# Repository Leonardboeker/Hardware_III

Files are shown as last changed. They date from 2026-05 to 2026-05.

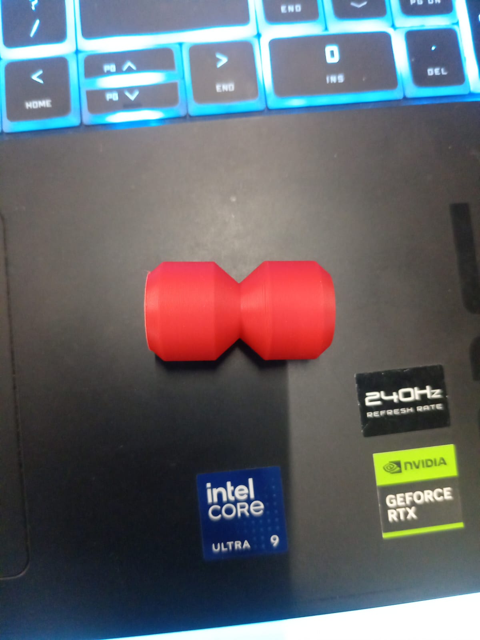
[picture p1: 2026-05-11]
vision/vision2/WhatsApp Image 2026-05-11 at 2.33.06 PM.jpeg

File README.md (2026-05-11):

# Hardware III — Guided Comparative Assembly

**Course:** Hardware III — Human-in-the-Loop: Interactive Systems
**Institute:** IAAC, MRAC + MAAI 2025/2026
**Schedule:** April 10 – May 22, 2026
**Team:** Leo, Elais, Rafik, Seid, Onur, Nithik

> **👉 Start here:** [`SYSTEM-STATUS.md`](SYSTEM-STATUS.md) — current state of every
> subsystem, what works, what's blocked, and where each team member plugs in.

---

## Mission

We compare construction methods by letting people physically configure a small
building scenario on a table and immediately see the environmental, labor, time,
and economic consequences through projection.

## Core Interaction

The visitor selects a construction method, configures the footprint, sets the
height, picks the material logic, validates the scenario, moves through five
construction phases, and finally reaches a comparison view.

---

## Tech Stack

| Tool | Role |
|---|---|
| TouchDesigner 2025.32050 | Primary runtime — FSM, projection, integration |
| Python 3 + OpenCV (ArUco) | Camera-side marker detection, OSC out to TD |
| ESP32 + MFRC522 (RFID) | Method selection, presence, hardware triggers |
| Rhino + Grasshopper | Offline geometry authoring + fabrication only — **not** runtime |
| Overhead USB webcam | ArUco tracking |
| Short-throw projector | Table projection + visual feedback |

The interactive runtime is **TouchDesigner + Python**. Rhino/Grasshopper is
used only for designing the physical parts (pucks, models, table mock-up).

---

## Canonical State Model

Layered model — do not collapse into a single flat list:

### Content FSM (visitor-facing)

```text
IDLE → METHOD → FOOTPRINT → HEIGHT → MATERIALS → VALIDATED → PHASE_N → COMPARISON
```

`PHASE_N` is one TouchDesigner state with an internal phase index for the five
locked construction phases: Foundation → Structure/Walls → Roof → Openings →
Finishing.

### System wrapper states

`CALIBRATION_CHECK`, `ERROR`, `RESET`, `MANUAL_OVERRIDE` — sit around the
content FSM for setup, recovery, and operator control.

### Visual feedback codes

`DISCONNECTED`, `PENDING`, `INVALID`, `VALID`, `IDLE_ANIM`, `SUMMARY`,
`COMPARISON` — projection feedback colors, not FSM states. Defined in
[touchdesigner/ERROR-FEEDBACK-SPEC.md](touchdesigner/ERROR-FEEDBACK-SPEC.md).

Full FSM details: [.planning/FSM_TOUCHDESIGNER_SPEC.md](.planning/FSM_TOUCHDESIGNER_SPEC.md)

---

## Quick Start

### 1. TouchDesigner side

Open `vertical-slice.toe`. Network nodes:

| Node | Type | Role |
|---|---|---|
| `vision_in` | OSC In CHOP | OSC data from CV pipeline |
| `rfid_in` | Constant CHOP (stub) → Serial DAT (real) | construction method selector |
| `compute_state` | Script CHOP | aggregates puck_count, area, method_id, hb_alive |
| `render_footprint` | Script TOP | renders 1280×720 projection image |
| `stats_text` | Text TOP | text overlay (Pucks / Area / Status) |
| `compose_final` | Over TOP | merges render_footprint + stats_text |
| `projector_out` | Window COMP | sends image to projector |

Full setup: [touchdesigner/TD-FRAMEWORK-GUIDE.md](touchdesigner/TD-FRAMEWORK-GUIDE.md)

### 2. Vision pipeline

```bash
pip install opencv-contrib-python python-osc pyyaml numpy

python -m vision.src.run_vertical_slice \
  --camera 0 \
  --intrinsics vision/calibration/synthetic_intrinsics.yml \
  --homography vision/calibration/synthetic_homography.yml
```

Press `Q` to quit. Replace synthetic YAMLs with real calibration files when
camera is mounted.

### 3. ESP32 (later, when hardware is built)

See [firmware/esp32-integration/ESP32-SENSOR-SYSTEM.md](firmware/esp32-integration/ESP32-SENSOR-SYSTEM.md)
for hardware spec. Until then, `rfid_in` is a Constant CHOP — change Channel 0
Value (0–4) to switch construction methods.

---

## Repository layout

```
README.md                    — this file
CONTRIBUTING.md              — repo conventions
INTERFACE_CONTRACT.md        — system-level data flow between subsystems
vertical-slice.toe           — main TouchDesigner project file

.planning/                   — project plan, FSM spec, roadmap, requirements
archive/                     — historical proposals, FSM drafts, slides (v1, v2)
cad/                         — 3D-printable parts (pucks, models, mounts)
  rhino/                     — Rhino + Grasshopper geometry sources
  aruco-markers/             — generated marker PNGs for printing
data/                        — JSON databases (methods_db.json, etc.)
deliverables/                — submission-ready artifacts
docs/                        — design notes, meeting records, research
  fsm/, meetings/            — internal docs
  research/, research_2/     — literature reviews + per-method research
  Data_Field.odt             — data-field spec (collaborator working doc)
firmware/                    — ESP32 firmware + sensor integration spec
media/                       — heavy reference assets
reference/                   — course syllabus, slides, literature notes
touchdesigner/
  scripts/                   — Python scripts pasted into Script OPs
  TD-FRAMEWORK-GUIDE.md      — step-by-step network build guide
  ERROR-FEEDBACK-SPEC.md     — visual feedback codes
  VERTICAL-SLICE-RUNBOOK.md  — run/test instructions
vision/
  src/                       — Python CV pipeline (ArUco detect, OSC send)
  calibration/               — camera/projector calibration files
```

---

## Phases

| Phase | Goal | Deadline |
|---|---|---|
| 1 — Proposal & FSM Foundation | S1 deliverables, lock concept | April 17 ✅ |
| 2 — Data Research & Physical Model Design | Source data, fabricate parts, CV vertical slice | May 4 |
| 3 — FSM Implementation & Assembly Logic | Full TD FSM + piece detection | May 4 |
| 4 — Human-in-the-Loop Assembly & Sound | Guided loop, sound layer | May 11 |
| 5 — Projection Mapping & Comparison View | Calibrated projector, comparison stats | May 18 |
| 6 — Integration, Testing & Finals | Reliable end-to-end demo | May 22 |

Status: [.planning/STATE.md](.planning/STATE.md)

---

## Source-of-truth order

When older documents conflict with current runtime, prefer in this order:

1. [touchdesigner/scripts/](touchdesigner/scripts/) — actual Python in TD
2. [.planning/FSM_TOUCHDESIGNER_SPEC.md](.planning/FSM_TOUCHDESIGNER_SPEC.md) — canonical FSM
3. [INTERFACE_CONTRACT.md](INTERFACE_CONTRACT.md) — subsystem data flow
4. [.planning/PROJECT.md](.planning/PROJECT.md) — project context
5. [.planning/ROADMAP.md](.planning/ROADMAP.md) — phase plan

Anything in `archive/` or older Phase 1 docs may still describe a Grasshopper +
Anemone + Firefly approach. That's **proposal history** — the current runtime
is TouchDesigner + Python.

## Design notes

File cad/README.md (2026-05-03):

# cad/

Print-ready 3D files for the physical components.

## Inventory

- 3 method-selector models (masonry, 3DP, prefab) — go on the RFID pedestal
- 10 ArUco footprint pucks (circular, ~Ø50mm — confirm)
- 1 height marker (physically distinct shape)
- 1 material controller (physically distinct shape)
- RFID pedestal housing
- Camera mount (if needed)

## Conventions

- Track the **source** file (`.3dm`, `.f3d`, `.step`) AND the export (`.stl`).
- Name pattern: `<part>-v<n>.stl`, e.g., `puck-aruco-v2.stl`. Bump the version when the print result changes.
- Print settings (layer height, infill, supports) → put them in a sibling `.md` next to the STL or in this README's print log below.

## Print log

| Part | Version | Printed by | Date | Notes |
|---|---|---|---|---|
| _e.g. puck-aruco-v1_ | _v1_ | _name_ | _YYYY-MM-DD_ | _result_ |

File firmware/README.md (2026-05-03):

# firmware/

ESP microcontroller code — RFID pedestal, any sensor inputs, comms with TouchDesigner.

## Scope

- RFID reader on the pedestal (detects which 3D-printed method model is placed)
- ESP → host transport: OSC over WiFi recommended (TouchDesigner has a native OSC In CHOP)
- Any other physical sensors that come up (buttons, encoders)

## Suggested layout

```
firmware/
├── pedestal-rfid/
│   ├── platformio.ini   # or arduino .ino
│   └── src/
└── shared/
    └── osc-protocol.md   # message names + payloads agreed with the TD side
```

## Conventions

- PlatformIO if you can — easier than Arduino IDE for collaboration.
- Pin assignments and any wiring diagrams go in this folder, not buried in commit messages.
- Never hardcode WiFi credentials. Use a `secrets.h` (gitignored) or load from a config.

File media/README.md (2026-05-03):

# media/

Reference imagery, demo videos, prototype photos, anything visual that isn't a final deliverable (those go in `deliverables/`).

## Suggested layout

```
references/        # Swiss Museum DJ table, Gramazio Kohler, Fologram, EPFL SXL ...
prototypes/        # photos/videos of our work-in-progress
inspiration/       # mood images, sketches
```

## Conventions

- Keep individual files under ~20 MB if possible. Anything heavier → cloud storage, link from here.
- Source attribution: if a reference image isn't ours, drop a `.txt` next to it with the source URL.
- For videos, prefer `.mp4` (H.264) — plays everywhere.

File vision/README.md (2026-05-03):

# vision/

Camera input, ArUco marker detection, distance/area calculations. Either runs standalone in Python and pipes to TouchDesigner, OR lives inside a TD Script CHOP — TBD by the vision owner.

## Scope

- Overhead camera capture
- ArUco marker detection (OpenCV `cv2.aruco`)
- Distance + area math: 10 footprint pucks → polygon → square meters
- Optional: YOLO for the 3D-printed method models (if RFID approach is dropped)
- Send results to TouchDesigner (OSC suggested)

## Suggested layout

```
vision/
├── pyproject.toml or requirements.txt
├── src/
│   ├── capture.py
│   ├── aruco_detect.py
│   ├── footprint.py        # polygon + area calc
│   └── osc_send.py
├── calibration/
│   └── camera_intrinsics.yml   # do the calibration once, commit the result
└── tests/
```

## Conventions

- Pin OpenCV + numpy versions. Vision code breaks subtly across versions.
- Camera intrinsics live in `calibration/` — anyone running the system needs them.
- Don't commit raw camera footage. Sample frames for debugging are fine.

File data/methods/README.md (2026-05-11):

# data/methods/

This folder now stores the normalized, engine-safe metrics datasets.

Expected filenames:
- `masonry.csv`
- `3d-printed.csv`
- `prefab.csv`
- `reclaimed-brick.csv`

Unified normalized header:

```text
method,data_model,display_mode,phase,lifecycle_stage,sub_method,metric,value_low,value_high,unit,basis,source_key,confidence_min,confidence_max,selected_material,notes,metadata
```

Model notes:
- `masonry` and `3d-printed` are `phase_based`
- `prefab` is `lifecycle_based`
- `reclaimed-brick` is `overlay`

Do not edit raw imported CSVs here.
Those stay under:

```text
data/imports/treethreetree/
```

The standalone normalization and engine pipeline lives in:

```text
metrics/pipeline.py
```

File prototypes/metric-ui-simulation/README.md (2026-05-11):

# Metric UI Simulation

Local browser prototype for testing the metric-engine contract without touching TouchDesigner files.

## Setup

```bash
npm install
npm run dev
```

Expected local URL:

`http://localhost:5173`

## What It Simulates

- A fixed `1920 x 1080` projection canvas
- Absolute-positioned panel layout matching the current projection plan
- Method switching for `Masonry`, `3D Printed`, and `Prefab`
- Method-dependent floor selection with a local stepper control
- Phase navigation for phase-based methods
- Lifecycle-only behavior for prefab
- Interactive center-plan zone selection with single-select and `Shift + click` multi-select
- Geometry-driven mock metric updates
- Debug overlay toggle with the `D` key

## Layout Model

The prototype uses a browser wrapper that scales the internal `1920 x 1080` canvas to fit the window while preserving the original coordinate system.

Key panels include:

- `panel_left_info`
- `panel_top_phase_navigation`
- `panel_main_plan_simulation`
- `panel_right_comparison`
- `panel_prefab_lifecycle_card`
- `panel_right_cost_chart`
- `panel_left_assembly_sequence`
- `panel_method_selection`
- `panel_right_phase_preview`
- `bar_bottom_status`

The intended interaction order is:

1. Choose method
2. Set floors
3. Choose phase or lifecycle mode
4. Click building part

## Data Model Behavior

### Phase-Based

Used for:

- `Masonry`
- `3D Printed`

These keep the construction phase model:

- `foundation`
- `structure`
- `roof`
- `openings`
- `finishing`

Phase clicks update the visible metric bundle.

Each phase-based method also carries its own floor range assumptions:

- `Masonry`: 1-5 floors, default 2
- `3D Printed`: 1-2 floors, default 1

These are prototype assumptions for UI testing, not validated engineering limits.

### Lifecycle-Based

Used for:

- `Prefab`

Prefab intentionally stays lifecycle-based and does **not** get remapped into construction phases.

The right comparison panel is replaced by the prefab lifecycle card and uses:

- `A1-A3`
- `A4`
- `A5`
- `B`
- `C`

The lifecycle card includes:

- `Lifecycle-only dataset` badge
- CLT / Modular Concrete toggle
- active geometry basis display

Prefab floor limits depend on the selected prefab type:

- `CLT / Timber Prefab`: 1-8 floors, default 3
- `Modular Concrete Prefab`: 1-12 floors, default 4

These limits are also prototype assumptions and should later be replaced by
validated structural, regulatory, or fabrication constraints.

## Center Plan Zone Selection

The center simulation panel includes clickable zones:

- `zone_core`
- `zone_north_wing`
- `zone_south_wing`
- `zone_east_wing`
- `zone_west_wing`
- `zone_courtyard`
- `zone_facade_band`

Interaction:

- Single click selects one zone
- `Shift + click` toggles multi-selection
- Clicking empty plan area resets to whole-building mode

Metric scaling responds to:

- `total selected area`
- `wall surface`
- `boundary length`

With floor-aware geometry enabled, the simulation distinguishes:

- `Footprint Area`
- `Total Selected Area = footprint area x floor count`
- `Wall Surface = base wall surface x floor count`
- `Building Height = floor count x floor height`

## Metric Logic

The simulation uses mock local coefficients only.

Main files:

- [src/mockMetricData.ts](./src/mockMetricData.ts)
- [src/calculateMockMetrics.ts](./src/calculateMockMetrics.ts)

The mock calculator enforces:

- `kgCO2eq_per_m2_gfa` -> multiply by total selected area
- `kgCO2eq_per_m2_wall` -> multiply by wall surface
- `calendar_days` / `total_days` -> do **not** multiply by area
- `days_per_m2` -> multiply by total selected area

This keeps the simulation focused on UI layout, interaction logic, metric contract, prefab lifecycle behavior, and zone-based scaling.

The browser stepper stands in for a future physical floor-count input such as
RFID, a rotary selector, or another fabricated interaction device.

## TouchDesigner Safety

This prototype does **not** modify any TouchDesigner files.

Everything is isolated under:

`prototypes/metric-ui-simulation/`

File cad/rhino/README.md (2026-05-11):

# cad/rhino/

Rhino + Grasshopper files — used **only for offline geometry authoring** of the
physical parts (puck shape, method-selector models, table mock-up, fabrication
support geometry).

The interactive runtime (FSM, vision, projection) lives in TouchDesigner +
Python, not in Grasshopper. See [`INTERFACE_CONTRACT.md`](../../INTERFACE_CONTRACT.md)
for the system-level data flow.

## What lives here

- `.3dm` Rhino source files
- `.gh` / `.ghx` Grasshopper definitions (parametric geometry only)
- GHPython / C# scripts referenced by those definitions

STL exports go in `cad/` (one level up) so they sit next to the other print files.

## Conventions

- Name files by content, not by date: `puck-aruco.gh`, not `final_v3_REAL.gh`
- Prefer `.ghx` (XML, diffable) over `.gh` (binary) for source-of-truth definitions
- Document expected inputs in a comment cluster top-left of the canvas
- Heavy reference geometry → `media/` or external storage, not here

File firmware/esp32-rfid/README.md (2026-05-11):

# esp32-rfid

ESP32 + MFRC522 firmware for the RFID method selector.

Reads MIFARE Classic 1K (S50) tag UIDs and streams them to TouchDesigner
over USB serial.

## Wiring

```
RC522        ESP32
─────────────────────────
SDA  (SS) -> GPIO 5
SCK       -> GPIO 18
MOSI      -> GPIO 23
MISO      -> GPIO 19
RST       -> GPIO 27
3.3V      -> 3V3  (NOT 5V — RC522 is 3.3V only)
GND       -> GND
IRQ       -> (not connected)
```

## Build & flash

1. Install the **Arduino IDE** (>= 2.0).
2. Add ESP32 board support: File → Preferences → Additional Boards Manager URLs:
   `https://espressif.github.io/arduino-esp32/package_esp32_index.json`
3. Tools → Board → Boards Manager → search "esp32" → install `esp32 by Espressif`.
4. Tools → Manage Libraries → search "MFRC522" → install `MFRC522 by GithubCommunity`.
5. Open `esp32_rfid.ino`.
6. Select board: Tools → Board → ESP32 Arduino → ESP32 Dev Module.
7. Select port: Tools → Port → COMx (the one that appears when ESP32 is plugged in).
8. Click upload (→ arrow).

## Test (without TouchDesigner)

Tools → Serial Monitor → set baud to **115200**. You should see:

```
BOOT:rfid_reader_ready
HB:1
HB:2
HB:3
RFID:A1B2C3D4    ← appears when you tap a tag on the reader
HB:4
...
```

The `BOOT` line confirms firmware loaded. `HB:N` is a per-second heartbeat so
TD knows the reader is alive even with no tag. `RFID:<HEX>` is the tag UID.

## Tag → method ID mapping

The mapping lives in TD, not in the firmware: see
[`touchdesigner/scripts/serial_rfid_v1.py`](../../touchdesigner/scripts/serial_rfid_v1.py)
→ `RFID_TO_METHOD`.

To register a new tag:
1. Tap it on the reader, note the hex UID printed in the Serial Monitor.
2. Add a line in `RFID_TO_METHOD`:
   ```python
   'A1B2C3D4': 1,   # Masonry
   ```
3. Re-paste the updated script into the `rfid_in` Serial DAT in TD.

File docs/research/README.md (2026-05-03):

# docs/research/

Source material that backs the LCA numbers and construction-method claims.

## What goes here

- Vendor / manufacturer data sheets
- Academic papers and links (drop a citation, not just the PDF)
- Notes from contacted companies (per the README's "10+ companies per method" action item)
- Catalonia regional data (logistics, transport)

## Structure (suggested)

```
masonry/
3d-printed/
prefab/
shared/        # cross-method LCA frameworks, baseline data
```

Every fact that ends up on the projector overlay should be traceable to a file here. If you can't cite it, it doesn't ship.

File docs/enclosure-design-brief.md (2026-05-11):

# ESP32 + RC522 Enclosure Design Brief

## Goal

Design a housing/enclosure for the ESP32 microcontroller and RC522 RFID reader
so they sit neatly instead of as naked hardware on the installation table.

## Hardware dimensions

- ESP32: ~51 × 25 × 7 mm
- RC522 RFID reader: ~60 × 40 × 5 mm

## Planned workflow

### Step 1 — Geometry (Rhino + Grasshopper)

Write a parametric GHPython script that builds the enclosure:
- Fully parametric — wall thickness, slot dimensions, tolerances adjustable
- Export STL for 3D printing
- I (Rafik) run it inside Rhino (already installed at IAAC)

### Step 2 — Render (Blender headless)

Write a Blender Python script that:
- Imports the STL or recreates the geometry
- Applies nice materials (matte plastic, subtle logo)
- Sets up product-shot lighting + camera
- Renders to PNG with no UI needed

Run from terminal: `blender --background --python render_enclosure.py`
Install Blender if needed: `winget install BlenderFoundation.Blender`

## Open questions (answer before starting)

1. 3D print for real OR just render for presentation — or both?
2. Aesthetic direction: match the installation (dark/architectural) or neutral/technical?
3. RFID reader access: top-open slot for tag tapping, or fully enclosed with a slit?

## When ready

Ask Claude to write:
- `cad/enclosure/enclosure.gh` — Grasshopper script
- `cad/enclosure/render_enclosure.py` — Blender render script

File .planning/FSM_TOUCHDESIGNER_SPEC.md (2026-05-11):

# TouchDesigner FSM Spec

**Project:** Hardware III - Guided Comparative Assembly  
**Prepared:** May 4, 2026  
**Canonical runtime source:** [fsm_full.py](/o:/Hardware_III/touchdesigner/scripts/fsm_full.py)

## 1. Purpose

This document defines the FSM architecture that best matches:
- the locked proposal
- the current roadmap
- the working TouchDesigner implementation

It replaces the earlier draft in which wrapper states and content states were mixed into one flat list.

## 2. Canonical Layered Model

The project uses three different state layers.

### Canonical Content FSM

This is the main visitor-facing interaction sequence and the **canonical FSM**:

```text
IDLE
  ->
METHOD
  ->
FOOTPRINT
  ->
HEIGHT
  ->
MATERIALS
  ->
VALIDATED
  ->
PHASE_N
  ->
COMPARISON
```

`PHASE_N` is one implementation state in TouchDesigner with an internal phase index:
- Phase 1: Foundation
- Phase 2: Structure / Walls
- Phase 3: Roof
- Phase 4: Openings
- Phase 5: Finishing

### System Wrapper States

These are system-level modes that sit around the canonical content FSM:
- `CALIBRATION_CHECK`
- `ERROR`
- `RESET`
- `MANUAL_OVERRIDE`

They are not the visitor’s main content path.
They are support modes for setup, failure recovery, and operator control.

### Visual Feedback States

These are projection feedback states:
- `DISCONNECTED`
- `PENDING`
- `INVALID`
- `VALID`
- `IDLE_ANIM`
- `SUMMARY`
- `COMPARISON`

They are output states, not the canonical content FSM.

## 3. Why This Is The Right Canonical FSM

This FSM is the best canonical choice because it is the only one that is simultaneously:
- locked in the proposal
- reflected in the roadmap
- already implemented in code

The matching references are:
- [PROJECT.md](/o:/Hardware_III/.planning/PROJECT.md)
- [ROADMAP.md](/o:/Hardware_III/.planning/ROADMAP.md)
- [fsm_full.py](/o:/Hardware_III/touchdesigner/scripts/fsm_full.py)

Older state lists such as:
- `GUIDING`
- `CHECKING`
- `NEXT_PIECE`
- `MODEL_COMPLETE`
- `NEXT_MODEL`

should now be treated as **historical proposal-development states**, not the active runtime definition.

## 4. Canonical Content FSM State List

| State | Purpose | Entry condition | Success condition | Next state | Visual feedback usually used |
|---|---|---|---|---|---|
| `IDLE` | Attract mode and waiting state before a method is selected | System is ready and no active method is locked | Method selector puck is confirmed in target | `METHOD` | `IDLE_ANIM` |
| `METHOD` | Locks one construction method for the current run | Method selector puck has engaged the pedestal zone | Selected method puck stays in target long enough | `FOOTPRINT` | `PENDING`, `VALID` |
| `FOOTPRINT` | Collects the 10 footprint pucks in order | Method is locked | All required footprint pucks are confirmed in sequence | `HEIGHT` | `PENDING`, `INVALID`, `VALID` |
| `HEIGHT` | Sets building height / number of floors | Footprint is complete | Height marker is confirmed in target | `MATERIALS` | `PENDING`, `INVALID`, `VALID` |
| `MATERIALS` | Locks the material / material controller choice | Height is complete | Material marker is confirmed in target | `VALIDATED` | `PENDING`, `INVALID`, `VALID` |
| `VALIDATED` | Shows a short summary and confirms the model is ready to expand into phases | Footprint, height, and materials are complete | External phase-start trigger fires | `PHASE_N` | `SUMMARY` |
| `PHASE_N` | Steps through the five locked construction phases for the active method | Validation has passed | All 5 phases have advanced; either next method starts or all methods are done | `METHOD` or `COMPARISON` | `VALID` |
| `COMPARISON` | Final cross-method comparison state | All methods have completed | Session ends or wrapper reset clears | `IDLE` through wrapper logic | `COMPARISON` |

## 5. System Wrapper States

These states or modes sit outside the content FSM.

| Wrapper state | Purpose | When to use it | Notes |
|---|---|---|---|
| `CALIBRATION_CHECK` | Verifies camera, projector, and table alignment | Before a session, after setup changes, after hardware disturbance | Recommended operator-only preflight mode |
| `ERROR` | Handles recoverable faults and invalid conditions | Tracking loss, impossible placement, hardware or data fault | Should not redefine the content sequence |
| `RESET` | Clears current session and returns the table to a known baseline | Operator reset, abandonment, hard fault recovery | Returns the system to `IDLE` |
| `MANUAL_OVERRIDE` | Allows operator rescue during demo | Vision failure, timing issue, emergency skip | Hidden control mode, not visitor-facing |

### Important rule

The content FSM should stay canonical and stable.
Wrapper states should interrupt or surround it, not replace it.

## 6. Visual Feedback States

These are the states used by the projection layer according to the current TD code and error feedback spec.

| Visual state | Meaning | Typical usage |
|---|---|---|
| `DISCONNECTED` | Vision heartbeat is dead or no reliable tracking is available | Show lost tracking condition clearly |
| `PENDING` | The expected puck has not yet been placed correctly | Show target outline, wait state |
| `INVALID` | A puck exists but is outside tolerance or outside the legal zone | Show red halo and ghost correction |
| `VALID` | A puck is inside tolerance and confirming or confirmed | Show green confirmation feedback |
| `IDLE_ANIM` | Content FSM is idle | Low-energy ambient attract animation |
| `SUMMARY` | Content FSM is in `VALIDATED` | Show summary data before entering phases |
| `COMPARISON` | Content FSM is in `COMPARISON` | Show final multi-method comparison |

### Key separation

Example:
- content state = `FOOTPRINT`
- wrapper state = none
- visual state = `INVALID`

This means the visitor is still in the footprint step, but the latest puck placement is wrong.
That is much clearer than inventing a fake combined state like `FOOTPRINT_INVALID`.

## 7. Current Working TouchDesigner Behavior

The current implementation in [fsm_full.py](/o:/Hardware_III/touchdesigner/scripts/fsm_full.py) uses:
- `pucks`
- `vision_alive`
- `manual_advance`
- `advance_to_phase_n`
- `advance_phase`

and writes:
- `fsm_state_name`
- `visual_state`
- `lca_trigger`
- `current_method`

### Content-state transitions already coded

| From | Condition in current code | To |
|---|---|---|
| `IDLE` | Method selector puck is in target and held for `CONFIRM_HOLD_FRAMES` | `METHOD` |
| `METHOD` | Same method puck stays confirmed in pedestal zone | `FOOTPRINT` |
| `FOOTPRINT` | All required footprint pucks are confirmed in order | `HEIGHT` |
| `HEIGHT` | Height marker is confirmed | `MATERIALS` |
| `MATERIALS` | Material marker is confirmed | `VALIDATED` |
| `VALIDATED` | `advance_to_phase_n == true` | `PHASE_N` |
| `PHASE_N` | 5 phases complete and not all methods done | `METHOD` |
| `PHASE_N` | 5 phases complete and all methods done | `COMPARISON` |

## 8. Recommended Transition Logic For Next Iteration

The next iteration should preserve the current content FSM and add cleaner wrapper logic around it.

### Content FSM rules
- IF the next expected puck is detected and `in_target == true` long enough THEN confirm that step
- IF the required set for the current content state is complete THEN advance to the next content state
- IF all methods are complete THEN enter `COMPARISON`

### Wrapper rules
- IF `vision_alive == false` for too long THEN set wrapper `ERROR` and visual `DISCONNECTED`
- IF operator issues reset THEN enter wrapper `RESET` and clear session memory
- IF calibration is invalid before public use THEN enter `CALIBRATION_CHECK`

### Visual rules
- IF puck exists and is outside target THEN `INVALID`
- IF puck exists and is inside target during hold window THEN `VALID`
- IF no puck exists yet for the expected step THEN `PENDING`
- IF content state is `VALIDATED` THEN `SUMMARY`

## 9. Input Contract Summary

### Current live input contract

From [osc_handler.py](/o:/Hardware_III/touchdesigner/scripts/osc_handler.py):

```python
pucks[id] = {
    "projector_xy": (px, py),
    "in_target": bool,
    "last_frame": int,
    "lost": False
}

vision_alive: bool
manual_advance: bool
```

### Target normalized contract

As the project scales, CV should normalize toward:
- `piece_id`
- `piece_type`
- `x`
- `y`
- `rotation`
- `confidence`
- `is_stable`
- `is_inside_zone`
- `zone_id`

but the working TD implementation remains the current source of truth until that expansion is actually merged into code.

## 10. Output Contract Summary

The projection system should read at least:
- `current_content_state`
- `system_wrapper_state`
- `visual_feedback_state`
- `active_piece_id`
- `current_method`
- `current_phase_index`
- metric outputs when visible

## 11. Mermaid Diagram

```mermaid
stateDiagram-v2
    [*] --> IDLE
    IDLE --> METHOD: method selector confirmed
    METHOD --> FOOTPRINT: method lock confirmed
    FOOTPRINT --> HEIGHT: all footprint pucks confirmed
    HEIGHT --> MATERIALS: height marker confirmed
    MATERIALS --> VALIDATED: material marker confirmed
    VALIDATED --> PHASE_N: phase sequence triggered
    PHASE_N --> METHOD: method complete, more methods remain
    PHASE_N --> COMPARISON: all methods complete
    COMPARISON --> IDLE: reset / next session
```

## 12. Implementation Direction

Continue from the **working FSM** in [fsm_full.py](/o:/Hardware_III/touchdesigner/scripts/fsm_full.py).

Do not replace it with a new flat state list.

Instead:
1. Keep `IDLE -> METHOD -> FOOTPRINT -> HEIGHT -> MATERIALS -> VALIDATED -> PHASE_N -> COMPARISON` as canonical.
2. Add `CALIBRATION_CHECK`, `ERROR`, and `RESET` as wrapper/system states around it.
3. Keep `DISCONNECTED`, `PENDING`, `INVALID`, `VALID`, `IDLE_ANIM`, `SUMMARY`, `COMPARISON` as projection feedback states.
4. Update contracts, role docs, and debug panels to display these three layers separately.

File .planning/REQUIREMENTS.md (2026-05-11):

# Requirements: Hardware III - Human-in-the-Loop Interactive Systems

**Defined:** 2026-04-10  
**Core Value:** Working interactive prototype where projection guides modular assembly in real time

> Interpretation note:
> Some requirement lines below preserve the original course wording from the early planning stage, including references to `Grasshopper`, `Anemone`, and older state labels such as `CHECKING`.
> The working project implementation has since locked to the TouchDesigner runtime FSM in [PROJECT.md](/o:/Hardware_III/.planning/PROJECT.md), [ROADMAP.md](/o:/Hardware_III/.planning/ROADMAP.md), and [fsm_full.py](/o:/Hardware_III/touchdesigner/scripts/fsm_full.py).

## v1 Requirements (Semester delivery - May 22)

### Session 1 Deliverables (due April 17)

- [ ] **S1-01**: Project proposal submitted (1 page or 3 slides): module type, connection logic, intended human input, intended feedback method
- [ ] **S1-02**: Project management schedule submitted: Gantt/Kanban/Sprint log with tasks, roles, dates, deliverables covering S1-S7
- [ ] **S1-03**: Embodied interaction observation: photo or sketch of one non-touchscreen interaction in daily life
- [ ] **S1-04**: First FSM drawn on paper: 3-5 states with labeled transitions

### Module & Connection Logic (Session 2 - April 17)

- [ ] **MOD-01**: Module type defined (physical geometry, material)
- [ ] **MOD-02**: Connection logic defined (snap-fit, slot, gravity, adhesive, rope, etc.)
- [ ] **MOD-03**: Connection valid vs invalid states defined (what makes a placement correct)
- [ ] **MOD-04**: Input method finalized (hand distance, body position, or physical object placement)

### FSM & System Logic (Session 3 - May 4)

- [ ] **FSM-01**: FSM diagram complete for the canonical content FSM (`IDLE`, `METHOD`, `FOOTPRINT`, `HEIGHT`, `MATERIALS`, `VALIDATED`, `PHASE_N`, `COMPARISON`) with wrapper and visual states documented separately
- [ ] **FSM-02**: All states have defined projection outputs (what light does in each state)
- [ ] **FSM-03**: All transitions labeled with trigger (sensor event, timer, gesture)
- [ ] **FSM-04**: FSM implemented in TouchDesigner using the locked canonical content FSM
- [ ] **FSM-05**: Rule format applied: IF [condition] -> THEN IN STATE [name]

### Sensor & Input Pipeline (Session 3-4)

- [ ] **INP-01**: Sensor/webcam connected and streaming interpreted data into TouchDesigner (OpenCV / ArUco -> OSC -> TouchDesigner or equivalent)
- [ ] **INP-02**: Human input mapped to fabrication parameter (mapping function defined: direct/juicy/stepped)
- [ ] **INP-03**: Input triggers correct FSM state transitions in real time

### Human-in-the-Loop Assembly (Session 4 - May 11)

- [ ] **HITL-01**: System cannot advance past the current canonical content step without valid human placement confirmed by the sensing pipeline
- [ ] **HITL-02**: System provides spatial feedback within 150ms of placement
- [ ] **HITL-03**: Error recovery: wrong placement -> system guides correction without reset
- [ ] **HITL-04**: Assembly sequence defined (which module comes next, in what order)

### Projection Mapping (Session 5-6 - May 11-18)

- [ ] **PROJ-01**: Projector calibrated to physical assembly surface
- [ ] **PROJ-02**: Projection shows next placement target (light outlines where module should go)
- [ ] **PROJ-03**: Projection changes color/pattern based on FSM state (green = confirmed, red = error)
- [ ] **PROJ-04**: System updates projection in real time as human places modules
- [ ] **PROJ-05**: Completion state: all modules placed -> full assembly celebration sequence

### Final Prototype (May 22)

- [ ] **FIN-01**: End-to-end loop works: human enters space -> system detects -> placement guide projects -> human places -> system validates -> next step appears
- [ ] **FIN-02**: Project management schedule updated each session and submitted for finals
- [ ] **FIN-03**: Working demo can be run without intervention

## v2 Requirements (Future / Not in scope for this semester)

- **V2-01**: Multiple simultaneous users
- **V2-02**: Sound feedback in addition to projection
- **V2-03**: Robotic arm integration (Parascho direction)

## Out of Scope

| Feature | Reason |
|---|---|
| Touchscreens / tablets | Explicitly excluded by course - kills spatial awareness |
| Static projection | Must be reactive - no pre-recorded content |
| Full automation (no human) | Human judgment must be in the loop by course requirement |
| Mobile app interface | No conventional apps per course brief |

## Traceability

| Requirement | Phase | Status |
|---|---|---|
| S1-01 to S1-04 | Phase 1 | Pending |
| MOD-01 to MOD-04 | Phase 2 | Pending |
| FSM-01 to FSM-05 | Phase 3 | Pending |
| INP-01 to INP-03 | Phase 3 | Pending |
| HITL-01 to HITL-04 | Phase 4 | Pending |
| PROJ-01 to PROJ-05 | Phase 5 | Pending |
| FIN-01 to FIN-03 | Phase 6 | Pending |

**Coverage:**
- v1 requirements: 28 total
- Mapped to phases: 28
- Unmapped: 0 OK

---
*Requirements defined: 2026-04-10*

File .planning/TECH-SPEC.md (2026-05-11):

# Technical Specification: Hardware III Installation

**Stack:** TouchDesigner + ESP32 (WiFi/OSC) + RFID + ArUco + Projector
**Last updated:** 2026-04-17

---

## 1. Hardware List

| Component | Spec | Quantity |
|---|---|---|
| Laptop | Windows/Mac, dedicated GPU preferred | 1 |
| Video projector | Short-throw, min 3000 lumen | 1 |
| USB webcam | Wide angle, min 1080p, fixed focus | 1 |
| ESP32 dev board | ESP32-WROOM-32 | 1 |
| RFID reader | MFRC522 (13.56MHz) | 1 |
| RFID tags | MIFARE Classic 1K, coin type | 3 |
| Overhead mount | Camera arm or ceiling rig | 1 |
| USB cable | ESP32 → laptop (power only, comms via WiFi) | 1 |

**Estimated extra cost: ~25–40€**

---

## 2. ArUco Markers

### What is ArUco
ArUco is a library of square fiducial markers. Each has a unique binary pattern. OpenCV detects them in a camera feed and returns: which marker ID, where on the image (4 corners), and orientation.

### The 12 markers

| Marker | IDs | Count | Purpose |
|---|-----|---|---|
| Floor plan tiles | 0–9 | 10 | User arranges to define building footprint |
| Story level selector | 10 | 1 | User places to set number of floors |
| Material selector | 11 | 1 | User places to select material variant |

### Generating the markers

Install: `pip install opencv-contrib-python`

```python
import cv2
import cv2.aruco as aruco

dictionary = aruco.getPredefinedDictionary(aruco.DICT_4X4_50)

for marker_id in range(12):
    marker_image = aruco.generateImageMarker(dictionary, marker_id, 300)
    cv2.imwrite(f"marker_{marker_id:02d}.png", marker_image)
    print(f"Saved marker_{marker_id:02d}.png")
```

Run: `python generate_markers.py` → outputs 12 PNG files.

### Printing ArUco with the Bambu X1C (in-place multi-color)

1. Design piece in Rhino — add a flat recessed square on top surface (depth: 0.4mm, size: 40×40mm)
2. Import STL into **Bambu Studio**
3. Right-click model → **Add Decal** → select your marker PNG
4. Align decal to top face, scale to fit recessed area
5. Assign: base filament = white PLA, decal layer = black PLA (via AMS)
6. Print — X1C pauses and swaps filament automatically for the marker layer

**Result:** Permanent, flush ArUco marker embedded in the print. No paper, no glue.

**Print settings:**
- Layer height: 0.2mm
- Recess depth: 0.4mm (2 layers)
- Use **matte** filament — glossy reflects projector light and breaks detection

---

## 3. RFID + ESP32

### Wiring: MFRC522 → ESP32

| MFRC522 pin | ESP32 pin |
|---|---|
| SDA (SS) | GPIO 5 |
| SCK | GPIO 18 |
| MOSI | GPIO 23 |
| MISO | GPIO 19 |
| GND | GND |
| RST | GPIO 27 |
| 3.3V | 3.3V |

### Embedding RFID tag in 3D model
- Design a pocket (25×25×2mm) in the base of each model
- Drop in RFID coin tag, seal with thin printed lid or resin
- Keep tag within 3cm of reader — MFRC522 read range is ~3cm

---

## 4. WiFi Communication: ESP32 → TouchDesigner via OSC

### Why OSC over WiFi
- No USB cable between ESP32 and laptop
- TouchDesigner has native OSC In CHOP — no extra setup
- Lightweight messages: `/rfid/model 2`

### Arduino Libraries (install via Arduino Library Manager)
- `MFRC522` by GithubCommunity
- `ArduinoOSC` by hideakitai
- `WiFi` — built into ESP32 board package

### ESP32 Firmware

```cpp
#include <WiFi.h>
#include <ArduinoOSC.h>
#include <MFRC522.h>
#include <SPI.h>

const char* ssid     = "YOUR_NETWORK";
const char* password = "YOUR_PASSWORD";
const char* TD_IP    = "192.168.1.100";  // your laptop IP
const int   TD_PORT  = 9000;

#define SS_PIN  5
#define RST_PIN 27
MFRC522 rfid(SS_PIN, RST_PIN);

// Fill UIDs after scanning each tag with a test sketch
struct RFIDModel {
  byte uid[4];
  int  model_id;
  const char* name;
};

RFIDModel models[] = {
  {{0xA1, 0xB2, 0xC3, 0xD4}, 1, "masonry"},
  {{0xE5, 0xF6, 0x07, 0x18}, 2, "3d_print"},
  {{0x29, 0x3A, 0x4B, 0x5C}, 3, "prefab"}
};

void setup() {
  Serial.begin(115200);
  SPI.begin();
  rfid.PCD_Init();

  WiFi.begin(ssid, password);
  while (WiFi.status() != WL_CONNECTED) {
    delay(500);
    Serial.print(".");
  }
  Serial.println("\nWiFi connected: " + WiFi.localIP().toString());
}

void loop() {
  OscWiFi.update();

  if (!rfid.PICC_IsNewCardPresent() || !rfid.PICC_ReadCardSerial()) return;

  for (auto& m : models) {
    if (memcmp(rfid.uid.uidByte, m.uid, 4) == 0) {
      Serial.printf("Model: %s (ID %d)\n", m.name, m.model_id);
      OscWiFi.send(TD_IP, TD_PORT, "/rfid/model", m.model_id);
      OscWiFi.send(TD_IP, TD_PORT, "/rfid/name",  m.name);
      break;
    }
  }

  rfid.PICC_HaltA();
  delay(1000);  // debounce
}
```

> **First run:** Use a UID scan sketch to read the actual UIDs of your 3 tags via Serial Monitor, then fill in the `models[]` array above.

---

## 5. TouchDesigner Pipeline

### Node network overview

```
[Video Device In TOP]   ← webcam
        ↓
[Script DAT]            ← OpenCV ArUco detection (Python, runs every frame)
        ↓
[Table DAT: aruco_data] ← detected marker IDs + normalized positions
        ↓
[CHOP Execute DAT]      ← FSM logic
        ↑
[OSC In CHOP]           ← receives /rfid/model from ESP32
        ↓
[Select CHOP]           ← active model ID
        ↓
[Render / Composite TOP] ← builds projection content per state
        ↓
[Homography TOP]         ← warps content to match table surface
        ↓
[Window COMP]            ← fullscreen output to projector
```

### A. Camera input
```
Video Device In TOP
  Device: your webcam
  Resolution: 1920×1080
  Flip horizontal if needed
```

### B. ArUco detection (Script DAT — Frame Start callback)

```python
import cv2
import cv2.aruco as aruco
import numpy as np

def onFrameStart(dat):
    cam_top = op('videodevicein1')
    frame = cam_top.numpyArray()[:, :, :3]
    frame = (frame * 255).astype(np.uint8)
    frame_bgr = cv2.cvtColor(frame, cv2.COLOR_RGB2BGR)

    dictionary = aruco.getPredefinedDictionary(aruco.DICT_4X4_50)
    params = aruco.DetectorParameters()
    detector = aruco.ArucoDetector(dictionary, params)
    corners, ids, _ = detector.detectMarkers(frame_bgr)

    table = op('aruco_data')
    table.clear()
    table.appendRow(['id', 'cx', 'cy'])

    if ids is not None:
        for i, marker_id in enumerate(ids.flatten()):
            c = corners[i][0]
            cx = float(np.mean(c[:, 0])) / frame_bgr.shape[1]
            cy = float(np.mean(c[:, 1])) / frame_bgr.shape[0]
            table.appendRow([int(marker_id), round(cx, 4), round(cy, 4)])
```

### C. OSC receiver (RFID input)
```
OSC In CHOP
  Network Port: 9000
  Active: On
→ Select CHOP filtering "/rfid/model"
→ value (1, 2, or 3) feeds into FSM
```

### D. Projection mapping (Homography calibration)
```
Homography TOP
  Input: your rendered content TOP
  Do this once:
    1. Project a white square fullscreen
    2. Physically measure the 4 table corners
    3. Drag Homography TOP corner pins until square aligns with table edges
  Save corner values — they persist between sessions
```

### E. FSM state machine (CHOP Execute DAT)

> Clarification:
> This 4-state example is a local micro-FSM sketch for a narrow interaction example.
> It is **not** the canonical project FSM.
> The canonical project FSM is:
> `IDLE -> METHOD -> FOOTPRINT -> HEIGHT -> MATERIALS -> VALIDATED -> PHASE_N -> COMPARISON`
> See [PROJECT.md](/o:/Hardware_III/.planning/PROJECT.md), [ROADMAP.md](/o:/Hardware_III/.planning/ROADMAP.md), and [fsm_full.py](/o:/Hardware_III/touchdesigner/scripts/fsm_full.py).

States: `IDLE` → `PRESENTING` → `DETAIL` → `COMPARISON`

```python
def onValueChange(channel, sampleIndex, val, prev):
    state_table = op('fsm_state')
    model_id = int(val)

    if model_id == 0:
        state_table['state', 1] = 'IDLE'
    else:
        rfid_count = int(op('active_models')['count', 1])
        if rfid_count >= 2:
            state_table['state', 1] = 'COMPARISON'
        else:
            state_table['state', 1] = 'PRESENTING'
            state_table['active_model', 1] = model_id
```

---

## 6. Software & Libraries

| Tool | Version | Purpose |
|---|---|---|
| **TouchDesigner** | 2023.11+ (free non-commercial) | Runtime: CV, projection mapping, FSM, output |
| **OpenCV** (Python) | `opencv-contrib-python 4.8+` | ArUco detection inside TD |
| **Arduino IDE** | 2.x | ESP32 firmware |
| **MFRC522 library** | Arduino Library Manager | RFID read |
| **ArduinoOSC** by hideakitai | Arduino Library Manager | WiFi OSC send from ESP32 |
| **ESP32 board package** | Arduino Board Manager | ESP32 support |
| **Python 3.11** | System | TD scripting + marker generation |
| **Rhino + Grasshopper** | Course version | LCA math, geometry design |

---

## 7. Setup Order (day of installation)

1. Mount webcam overhead, fixed — no wobble
2. Power ESP32 via USB or battery pack
3. Connect both laptop and ESP32 to same WiFi network
4. Open TouchDesigner → confirm OSC messages arriving (`/rfid/model`)
5. Run ArUco detection → confirm all 12 markers detected correctly
6. Homography calibration → align projection to table (~10 min, one time)
7. Test full flow: place model → RFID read → correct content projected

---

## 8. Known Issues & Mitigations

| Issue | Mitigation |
|---|---|
| Projector light washes out ArUco detection | Use matte filament; tune camera exposure down |
| ESP32 WiFi drops | Add reconnect loop in firmware; use 2.4GHz not 5GHz |
| Homography drifts if projector moves | Re-run calibration; mark projector position with tape |
| RFID read range too short | Keep reader flush with pedestal surface; coin tags work at 0–3cm |

---
*Created: 2026-04-17*

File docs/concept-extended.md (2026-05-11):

# Concept (Extended) — Guided Comparative Assembly Installation

> **Note:** This is a more detailed concept document developed by Rafik based on the iterations after Session 2. It expands on the version in the root `README.md`. Treat the root README as the **canonical** concept until the team merges this in.

**Course:** Hardware III — Human-in-the-Loop: Interactive Systems
**Institute:** IAAC, MRAC + MAAI 2025/2026
**Instructors:** Hamid Peiro, Aleksandra Kraeva
**Schedule:** April 10 – May 22, 2026
**Team:** Leo, Elais, Rafik, Seid, Onur, Nithik

---

## Mission

We compare different statistics of the housing construction industry and display them through an interactive exhibit — a hands-on learning experience for children, young architects, and decision makers.

## Concept

An interactive table installation where users **configure** and compare buildings across three construction methods. Instead of reading abstract statistics, you define your building, watch it get constructed phase by phase, and see the real environmental and economic cost — all through physical interaction with projection-mapped surfaces.

Inspired by the Swiss Museum's interactive DJ table (ArUco markers + projection mapping).

---

## Construction Methods

| Method | Description | Materials |
|---|---|---|
| **Classical / Masonry** | Traditional brickwork construction | Brick or Stone |
| **3D Printed** | Additive construction, layer by layer | Earth or Concrete |
| **Prefab / Modular** | Factory-built modules assembled on site | Grid / Modular panels |

### Material Constraints
- Earth-based 3D printing: max 1 story
- System enforces realistic limitations with visual feedback (red = not possible)

---

## User Interaction Flow

```
1. METHOD SELECTION
   Place one of three 3D-printed models on RFID pedestal
   → System identifies construction method

2. DEFINE BUILDING SIZE
   Arrange 10 ArUco marker pucks on table to create building footprint
   → Camera tracks distances between markers → calculates dimensions
   → Area within markers shown in green (valid) or red (invalid)

3. SET HEIGHT / FLOORS
   Use dedicated ArUco marker (physically distinct) to select number of stories
   → System validates feasibility per method + material

4. CHOOSE MATERIALS
   Use another distinct ArUco controller to select foundation type + main material
   → Masonry: brick or stone
   → 3DP: earth or concrete
   → Prefab: modular grid

5. GUIDED BUILDING PHASES (~5 per method)
   System walks through each construction phase with animations:
   → Foundation/excavation → Walls/structure → Roof → Windows → Finishing
   → Each phase shows: CO₂ per ton, energy usage, labor hours, time, cost
   → User accepts to continue to next phase

6. FINAL OUTPUT
   Complete breakdown: total cost, carbon emissions, material usage,
   logistics, labor — contextualized (e.g., "2000 tons of wood = X trees")

7. SAVE & COMPARE
   Save building as dataset → build another configuration → compare side by side
```

---

## Key Parameters & Data Points

- CO₂ emissions and carbon footprint
- Labor hours and worker health/safety
- Material usage (concrete, wood, cement) with real-world equivalents
- Total costs broken down by phase
- Logistics and transportation (focused on Catalonia region)
- Time required for construction

---

## System Architecture

### Physical Components

| Component | Role |
|---|---|
| **RFID Pedestal + ESP** | Recognizes which construction method model is placed |
| **3 Physical 3D-printed models** | Method selectors (classical, 3DP, prefab) — also projection targets |
| **10 Circular ArUco pucks** | Define building footprint on table |
| **Height ArUco marker** | Physically distinct — selects number of floors |
| **Material ArUco controller** | Selects foundation type and main material |
| **Top-down projector** | Projects onto table (construction site) |
| **Overhead camera** | Tracks ArUco positions, calculates distances |
| **ESP controllers** | Communication between physical inputs and system |
| **Display screens** | Information, cost estimates, comparisons |

### Software Stack

| Tool | Role |
|---|---|
| **TouchDesigner 2025** | Primary runtime — FSM, projection, integration |
| **Python + OpenCV (ArUco)** | Marker detection, OSC out to TD |
| **Rhino + Grasshopper** | Offline geometry authoring + fabrication only |
| **ESP32 firmware** | RFID + proximity sensor communication |

---

## FSM States

```
IDLE
  → model placed on RFID pedestal
METHOD_SELECTED
  → ArUco pucks placed on table
FOOTPRINT_DEFINED
  → camera validates distances, area calculated
  → height marker placed
HEIGHT_SET
  → material marker placed
MATERIALS_CHOSEN
  → system validates feasibility
  → VALID: proceed | INVALID: show error, adjust
VALIDATED
  → begin phase walkthrough
PHASE_DISPLAY (×5 per method)
  → animation plays, data shown
  → user accepts → next phase
BUILDING_COMPLETE
  → final output displayed
  → save dataset
COMPARISON
  → multiple builds compared side by side
  → timeout → IDLE
```

---

## Building Phases (per method, ~5 each)

| Phase | Example (Masonry) | Data Shown |
|---|---|---|
| 1. Foundation / Excavation | Excavator, concrete pour | CO₂/ton cement, cost, time |
| 2. Structure / Walls | Brickwork rises | Labor hours, material qty |
| 3. Roof | Framing + covering | Material usage, safety |
| 4. Windows / Openings | Installation | Cost, energy |
| 5. Finishing | Plastering, painting, floors | Total finishing cost, time |

*Exact phases per method require research — 3DP and prefab have different sequences.*

---

## Development Priorities

| Priority | Phase | Scope |
|---|---|---|
| **P1 (Course critical)** | Projector + Camera + ArUco | Square meter sizing, floor selection, GUI, top-down projection, camera tracking |
| **P2** | RFID + ESP | Pedestal integration, method selection, ESP communication |
| **P3** | Building phases | Phase animations (AI-generated), information display per phase |
| **P4** | Data + Comparison | Cost tracking, CO₂ tracking, dataset save, side-by-side comparison |

---

## Research Action Items

- [ ] Research building phases for classical/masonry, 3D printed, and prefab methods
- [ ] Contact 10+ companies per construction method for reference data
- [ ] Research AI-generated animation tools for building phase visualization
- [ ] Define all analytical parameters and data requirements
- [ ] 3D print ArUco marker pucks
- [ ] Install YOLO plugin for TouchDesigner
- [ ] Gather regional data (Catalonia focus) for logistics calculations

---

## Key Reference

**Swiss Museum DJ Table** — Interactive installation using ArUco markers on a large table with top-down projection. Users place physical objects to compose music. Direct precedent for our interaction model.

**Stefana Parascho** — *Cooperative Robotic Assembly* (ETH Diss. 25839). Assembly sequence as FSM.

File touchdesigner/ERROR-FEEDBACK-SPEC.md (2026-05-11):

# Error Feedback Visual Language Spec

**Status:** LOCKED (Phase 2, Plan 02-06)
**Owner:** TD Logic (FSM) + TD Visuals (Projection)
**Referenced by:** Plan 02-07, fsm_vertical_slice.py, fsm_full.py

---

## Visual State Codes

| Code | Name | When | Projection Output |
|---|---|---|---|
| 0 | DISCONNECTED | No vision heartbeat ≥ 1s, or no puck detected ≥ 1s | Dotted white outline of target zone, pulsing at 1 Hz |
| 1 | PENDING | Puck detected but outside target zone, not enough to show ghost | Solid white outline of target zone |
| 2 | INVALID | Puck detected, outside zone, clear wrong-placement | **Ghost** at correct position (cyan, 40% opacity) + **red halo** at current puck position |
| 3 | VALID | Puck inside target zone, confirming (or confirmed) | **Green halo** at puck position, expanding ring animation |
| 4 | IDLE_ANIM | FSM in IDLE state | Slow breathing pulse across all target zones, white |
| 5 | SUMMARY | All pieces confirmed for one model | Full data overlay: CO₂ range, labor hours, construction time. White text on dark background |
| 6 | COMPARISON | All 3 models complete | Full-table comparison: all methods side-by-side, reclaimed-brick baseline as floor line |

---

## Ghost Projection (INVALID state)

The ghost pattern follows the **Augmented Bricklaying** convention (Mitterberger et al. 2020):
- Ghost shape: exact footprint of the expected puck position, same size as puck
- Ghost color: **cyan (#00FFFF)**, opacity 40%
- Current puck: **red halo** (#FF3333), 3px stroke
- Both rendered simultaneously so user sees where it is vs where it should be

**Recovery without reset:** as soon as puck enters the correct zone → visual switches to VALID without any button press.

---

## Tolerance Zones

Target zones are defined in projector-pixel space by the Python vision pipeline.
Radius is set in `vision/calibration/TOLERANCE.md`.

Visual feedback:
- Outside tolerance radius → INVALID (if puck detected) or PENDING (if no puck)
- Inside tolerance radius → VALID confirmation sequence begins
- Dwell time before confirmation: `CONFIRM_HOLD_FRAMES = 5` frames (~167ms at 30fps)

---

## Projection Colors

| Element | Color | Hex |
|---|---|-----|
| Target zone outline | White | #FFFFFF |
| Valid / confirmed | Green | #00FF88 |
| Invalid / wrong position | Red | #FF3333 |
| Ghost (correct position) | Cyan | #00FFFF |
| Disconnected pulse | White dimmed | #AAAAAA |
| Data text | White | #FFFFFF |
| Reclaimed baseline | Orange accent | #FF8C00 |

---

## Implementation Notes (for TD Visuals person)

1. The `visual_state` channel output from `fsm_vertical_slice.py` / `fsm_full.py` (Script CHOP) drives a **Switch TOP** that selects which overlay to project.
2. Each state is a separate TOP branch — composited onto the base projection via an **Over TOP**.
3. Ghost position: read `pucks[TARGET_ID]['projector_xy']` and the known `target_xy` from storage. Draw both in the Ghost TOP branch.
4. VALID animation: use a **Ramp TOP** + **Feedback TOP** for the expanding ring — trigger reset on each new VALID event via the `lca_trigger` channel pulse.
5. DISCONNECTED dotted outline: use a **Line MAT** or **SOP to TOP** with a dashed pattern; animate opacity with a slow **LFO CHOP** at 1 Hz.

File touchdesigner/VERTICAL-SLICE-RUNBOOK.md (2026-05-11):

# Vertical Slice Runbook — Phase 2

One-puck closed-loop CV demo. Run this before Phase 3 to prove the pipeline works end-to-end.

---

## Prerequisites

```
pip install opencv-contrib-python python-osc pyyaml numpy
```

TouchDesigner build: **2025.32050** (pin this — do not upgrade mid-project)

---

## Hardware Setup

1. Mount webcam overhead, pointing straight down at the table.
2. Connect projector, set resolution to **1280×720** (or match your actual unit).
3. Print or 3D-print one ArUco puck using **DICT_4X4_50, ID=0**.
4. Have real calibration files ready in `vision/calibration/`:
   - `camera_intrinsics.yml` — from Plan 02-05 (checkerboard calibration)
   - `homography.yml` — from Plan 02-05 (camera-to-projector mapping)
   - If not ready yet: use `--dry-run` flag (synthetic YAMLs, not for demo).

---

## Step 1: Determine target zone

Open TD, run `vertical-slice.toe`, and note the projector-pixel coordinates of the target zone you want the puck to land in. Example: `640 400` (center of a 1280×720 projector).

---

## Step 2: Start the Python vision pipeline

From the project root:

```bash
python -m vision.src.run_vertical_slice \
    --camera 0 \
    --intrinsics vision/calibration/camera_intrinsics.yml \
    --homography vision/calibration/homography.yml \
    --td-host 127.0.0.1 \
    --td-port 7000 \
    --puck-id 0 \
    --target-x 640 --target-y 400
```

With synthetic calibration (no hardware yet):
```bash
python -m vision.src.run_vertical_slice --dry-run --puck-id 0 --target-x 640 --target-y 400
```

A preview window opens showing the camera feed with detected puck positions overlaid.

---

## Step 3: Build the TouchDesigner node graph

Open TouchDesigner and build `touchdesigner/vertical-slice.toe` with this network:

```
[OSC In CHOP]  port=7000, UDP
     │
     ▼
[DAT Execute]  ← script: touchdesigner/scripts/osc_handler.py
               fires onReceiveOSC() for each incoming message
               stores puck data into parent() storage

[Script CHOP]  ← script: touchdesigner/scripts/fsm_vertical_slice.py
               cook() runs every frame
               outputs: fsm_state (int), visual_state (int)
     │
     ▼
[Select CHOP]  channel: visual_state
     │
     ▼
[Switch TOP]   input 0=DISCONNECTED, 1=PENDING, 2=INVALID, 3=VALID
               (each input is a TOP branch per ERROR-FEEDBACK-SPEC.md)
     │
     ▼
[Window COMP]  fullscreen on projector output
```

**Storage node:** Use a `Base COMP` named `storage` at the root. All `parent().store/fetch` calls target this.

---

## Step 4: Set output channels on the Script CHOP

In the Script CHOP's `setupParameters` callback (or the `info` DAT), declare these channels:
```python
scriptOp.appendChan('fsm_state')
scriptOp.appendChan('visual_state')
```

---

## Step 5: Test the four visual states

| Test | How | Expected |
|---|-----|---|
| DISCONNECTED | Kill the Python script | Dotted outline, pulsing |
| PENDING | Put puck on table, away from target zone | Solid white outline at target |
| INVALID | Move puck close to but outside target | Red halo on puck + cyan ghost at target |
| VALID | Place puck inside target zone | Green expanding ring |
| CONFIRMED | Hold puck in zone for ≥5 frames | `fsm_state` flips to 1, stays green |

---

## Step 6: Record the demo video

Use OBS or any screen recorder. Required deliverable: `deliverables/vertical-slice-demo.mp4`
- Duration: 30 seconds minimum
- Show: puck outside zone → INVALID → move to zone → VALID → CONFIRMED
- Record the camera preview window AND the projector output side-by-side if possible

---

## Latency measurement

The Python pipeline prints avg/max latency at exit. To measure end-to-end (including TD render):
- Film with a high-speed phone camera (240fps)
- Move puck rapidly and count frames between physical puck entering zone and projection changing color
- Target: < 150 ms (= < 36 frames at 240fps)

---

## Troubleshooting

| Problem | Fix |
|---|-----|
| No OSC data in TD | Check port 7000 is not blocked by firewall; confirm `--td-port` matches OSC In CHOP port |
| Puck not detected | Check ARUCO_DICT_NAME matches `cad/PUCK-SPEC.md`; increase camera exposure |
| High false-positive rate | Reduce ambient light; cover projector hotspots; tighten `minMarkerPerimeterRate` |
| Ghost at wrong position | Re-run calibration (Plan 02-05); verify homography.yml was generated for current camera mount |
| `in_target` always 0 | Check `--target-x/y` match actual projector-pixel target zone; recalibrate tolerance in `TOLERANCE.md` |

---

## Files

| File | Purpose |
|---|---|
| `vision/src/aruco_detect.py` | CV core — detect pucks, map to projector coords |
| `vision/src/osc_send.py` | OSC sender |
| `vision/src/run_vertical_slice.py` | CLI entry point |
| `vision/calibration/camera_intrinsics.yml` | Camera intrinsics (from Plan 02-05) |
| `vision/calibration/homography.yml` | Camera→projector homography (from Plan 02-05) |
| `vision/calibration/TOLERANCE.md` | Tolerance value + jitter measurements |
| `touchdesigner/scripts/osc_handler.py` | TD Script DAT — parses OSC, writes storage |
| `touchdesigner/scripts/fsm_vertical_slice.py` | TD Script CHOP — 2-state FSM |
| `touchdesigner/ERROR-FEEDBACK-SPEC.md` | Visual state spec |
| `touchdesigner/vertical-slice.toe` | TD project (binary — build from this runbook) |

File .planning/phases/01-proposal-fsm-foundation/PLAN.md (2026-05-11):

# Phase 1 Plan: Proposal & FSM Foundation

**Goal:** Submit all S1 deliverables before Session 2. Concept fully defined: guided comparative assembly + projection + data + sound.
**Deadline:** April 17, 2026
**Requirements:** S1-01, S1-02, S1-03, S1-04

> Historical note:
> This file records the original Phase 1 submission plan.
> Its paper-FSM tasks reflect an earlier proposal-stage state sketch.
> The current canonical TouchDesigner runtime FSM is now:
> `IDLE -> METHOD -> FOOTPRINT -> HEIGHT -> MATERIALS -> VALIDATED -> PHASE_N -> COMPARISON`
> See [PROJECT.md](/o:/Hardware_III/.planning/PROJECT.md), [ROADMAP.md](/o:/Hardware_III/.planning/ROADMAP.md), and [fsm_full.py](/o:/Hardware_III/touchdesigner/scripts/fsm_full.py).

---

## Tasks

### 01-01: Lock Core Decisions (construction methods + building type)

**Deliverable:** Written decision record — which 2–4 methods and which building/object type

**Owner:** Full team (15-minute working session)

**Steps:**
1. Choose construction methods from: traditional masonry, 3D-printed concrete, modular prefab/CLT, adobe/vernacular
   - Recommendation: start with 3 methods — traditional masonry, 3D-printed concrete, modular prefab/CLT
   - Adobe is a strong 4th if time allows fabricating a 4th model set
2. Choose building type — must be simple enough to model at 1:50 scale in ~5–8 discrete pieces
   - Recommendation: a single-bay structural wall section (3m x 3m) — simple geometry, identical form across methods, lets data differences speak
   - Alternatives: small pavilion (~8 pieces), column with base (~4 pieces)
3. Define piece count per model (aim for 5–8 pieces — enough to feel sequential, not so many it becomes tedious)
4. Write decisions down in one sentence each: "We are comparing X, Y, Z construction methods. The object is a [type]. Each model has approximately N pieces."

**Done when:** Team has a written 4-sentence decision record and everyone agrees. No further debate on these choices.

---

### 01-02: Write Project Proposal (S1-01)

**Deliverable:** 1-page PDF or 3-slide deck submitted to instructors

**Owner:** Team — one person drafts, all review

**Steps:**
1. Open a slide deck or A4 document
2. Write/place these four sections (one per slide or per paragraph):
   - **Module type:** What are the physical pieces — describe geometry, material (cardboard, 3D-print, laser cut wood), scale, and how they differ per construction method
   - **Connection logic:** How pieces are placed — no physical connection between pieces, placement validated by overhead camera against projected target outline; pieces are color-coded or ArUco-marker-tagged per construction method
   - **Input method:** Overhead USB webcam (position detection via Firefly → Grasshopper) + ESP32 proximity sensor (user reaches toward table → data layer zooms)
   - **Feedback method:** Projector on table surface — step 1: placement outline projected; step 2: on confirmation, CO₂ + labor hours + method text appear on/around the placed piece; sound layer reinforces each step (method-specific audio: concrete mixer, robotic arm hum, timber stacking)
3. Add one image or diagram showing the top-down table layout (projector, webcam, models)
4. Export as PDF or save slide link
5. Submit to course platform / email instructors

**Done when:** Proposal document exists, covers all four required sections, submitted before April 17.

---

### 01-03: Create Project Management Schedule (S1-02)

**Deliverable:** Gantt chart or equivalent covering S1–S7 with team roles and per-session deliverables

**Owner:** PM lead (whoever takes that role)

**Steps:**
1. Open a spreadsheet (Excel, Google Sheets) or a tool like Notion, Trello, or a paper Gantt
2. Create a row per session/week:
   - S1 (April 10–17): Proposal, FSM paper diagram, embodied interaction observation
   - S2 (April 17): Module definition locked, connection logic spec, data research started
   - S3 (May 4): FSM in Grasshopper (Anemone), sensor pipeline live (webcam → Firefly → GH)
   - S4 (May 11): Full assembly loop for 2 methods, sound layer, ESP32 wired
   - S5 (May 18): Projection mapping calibrated, comparison view, all visual layers
   - S6 (May 22 Finals): End-to-end demo working, physical models fabricated, PM updated
3. Add a column for team role responsible per task
4. Define team roles — suggested split:
   - Tech lead: Grasshopper / Anemone / FSM logic
   - Sensing lead: Webcam / Firefly / ESP32 / Arduino
   - Projection lead: TouchDesigner or HeavyM calibration, visual layers
   - Content lead: Data research (CO₂, labor hours), physical model design + fabrication
   - PM: Schedule updates each session, submission tracking
   - (Roles can overlap for a small team — assign primary owner per task)
5. Export or screenshot the Gantt
6. Submit to course platform

**Done when:** Schedule exists as a shareable document, all sessions S1–S7 have at least one deliverable listed, each task has an owner name.

---

### 01-04: Draw FSM Diagram on Paper (S1-04)

**Deliverable:** Hand-drawn or sketched FSM diagram, photographed and submitted

**Owner:** Any team member, verified by all

**Steps:**
1. Take a blank sheet of A3 or A4
2. Draw 8 labeled state boxes:
   - IDLE
   - GUIDING
   - CHECKING
   - CONFIRMED
   - NEXT_PIECE
   - MODEL_COMPLETE
   - NEXT_MODEL
   - COMPARISON
3. Draw directed arrows between states with labeled transitions:
   - IDLE → GUIDING: "object / hand detected in zone (proximity sensor)"
   - GUIDING → CHECKING: "piece placed in target zone (webcam detects marker)"
   - CHECKING → CONFIRMED: "position valid (0.3s validation passes)"
   - CHECKING → GUIDING: "position invalid (ghost outline shown, retry)"
   - CONFIRMED → NEXT_PIECE: "data shown, timer expires or hand lifts (not last piece)"
   - CONFIRMED → MODEL_COMPLETE: "data shown, last piece of this model"
   - NEXT_PIECE → GUIDING: "next piece target highlighted"
   - MODEL_COMPLETE → NEXT_MODEL: "model summary shown, user picks up next kit"
   - NEXT_MODEL → GUIDING: "reset projection for new method"
   - COMPARISON → IDLE: "all models done, full stats projected, timeout resets"
   - Note: CONFIRMED → COMPARISON only when all models complete (annotate this)
4. Add a small legend: boxes = states, arrows = transitions, labels = trigger events
5. Photograph the diagram with good lighting (flat lay, no shadows)
6. Submit photo

**Done when:** Diagram photo shows all 8 states, all transitions have labeled triggers, submitted before April 17.

---

### 01-05: Capture Embodied Interaction Observation (S1-03)

**Deliverable:** One photo or sketch with a 2–3 sentence written observation, submitted

**Owner:** Any team member

**Steps:**
1. Find one non-touchscreen interaction in daily life that involves body position, gesture, or spatial awareness — examples:
   - Turning a door handle (rotational gesture, body weight transfer)
   - Operating a manual espresso machine (pressure feedback through the tamper)
   - Using stairs (proprioception without looking, rhythm)
   - Opening a lock with a physical key (tactile resistance, angular precision)
   - Pulling a drawer (resistance curve, sound of latch)
2. Photograph it in action (not a stock photo — your own hand/body) OR sketch it as a diagram showing body parts and directions of force/movement
3. Write 2–3 sentences describing:
   - What the body is doing (physical movement, contact points)
   - What feedback the body receives (resistance, sound, temperature, spatial position)
   - Why this is relevant to the project (connection to guided assembly / non-screen feedback)
4. Combine photo/sketch + text into one document or slide
5. Submit

**Done when:** Submission contains a photo or sketch + 2–3 sentences with explicit connection to the project concept. Must show a real non-digital interaction.

---

### 01-06: Submit All Deliverables + Commit Files to Git

**Deliverable:** All 4 S1 deliverables submitted to course + files committed to repository

**Owner:** Team (PM lead coordinates)

**Steps:**
1. Collect all deliverable files:
   - `S1-01_proposal.[pdf/slides link]`
   - `S1-02_gantt.[xlsx/pdf/screenshot]`
   - `S1-03_embodied_interaction.[jpg/png/pdf]`
   - `S1-04_fsm_diagram.[jpg/png]`
2. Place files in `D:\IAAC\Hardware_III\Project\S1_Deliverables\` (create folder if needed)
3. Submit to instructors (course platform or email — use whichever channel instructors specified)
4. Stage and commit to git:
   ```
   git add Project/S1_Deliverables/
   git commit -m "feat(S1): submit all S1 deliverables — proposal, Gantt, FSM diagram, embodied interaction"
   git push origin master
   ```
5. Verify push succeeded at: https://github.com/Leonardboeker/Hardware_III

**Done when:** All 4 files are committed and pushed to GitHub AND submitted to instructors. GitHub shows the S1_Deliverables folder in the latest commit.

---

## Timeline (April 10–17)

| Day | Task |
|-----|---|
| April 10 (today) | 01-01: Lock decisions (30 min team call) |
| April 11–12 | 01-02: Draft proposal; 01-04: Draw FSM diagram |
| April 12–13 | 01-03: Create Gantt; 01-05: Capture embodied interaction |
| April 14–15 | Review all materials as a team, revise |
| April 16 | Final review, compile, submit + commit |
| April 17 | Hard deadline — Session 2 |

---

## Success Criteria

All of the following must be TRUE before April 17:

- [ ] Written record of chosen construction methods (2–4) and building type exists
- [ ] Proposal document covers module type, connection logic, input method, feedback method — submitted
- [ ] Gantt/schedule covers S1–S7, lists deliverables per session, has team role assignments — submitted
- [ ] FSM diagram shows all 8 states with labeled transitions — photographed and submitted
- [ ] Embodied interaction: photo or sketch + 2–3 sentences connecting it to the project — submitted
- [ ] All files committed to GitHub master branch under `Project/S1_Deliverables/`

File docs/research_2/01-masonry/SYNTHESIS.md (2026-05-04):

# SYNTHESIS — Strand 01: Traditional Fired-Clay Block Masonry (Catalonia)

## (a) Summary of the evidence landscape

Traditional fired-clay block masonry construction is the most-studied building system in the Spanish life-cycle-assessment literature, and the second most-studied in the European one (after RC-frame). For this strand the evidence base falls into three distinct layers, each carrying a different kind of authority:

**Layer 1 — sectoral EPDs from Hispalyt registered on the AENOR GlobalEPD programme.** The Spanish Brick & Roof-Tile Manufacturers Association (Hispalyt) holds three sectoral EPDs that, between them, cover the entire fired-clay product range used in Catalan residential masonry: GlobalEPD 008-001 (clay roof tiles, A1–A3 = 199 kg CO₂ eq / tonne), 008-016 (facing brick / *cara vista*, A1–A3 = 230 kg CO₂ eq / tonne, with GWP-fossil specifically), and 008-017 (clay block + perforated/hollow brick *para revestir*, A1–A3 = 209 kg CO₂ eq / tonne). All three are EN 15804:2012+A2:2019 compliant, were prepared by the UNESCO Chair on Life Cycle and Climate Change at ESCI-UPF in Barcelona using GaBi LCA-for-Experts 10.7.1.28, and use 2022 production data from at least 63 % of the Spanish kiln base. They are the highest-authority Tier-1 cradle-to-gate figures available for this strand.

**Layer 2 — the BEDEC + CYPE Catalan baseline.** ITeC's BEDEC database provides Catalonia-specific labour coefficients, cost data, and environmental indicators (carbon footprint, water, renewable + non-renewable energy, waste mass, recycled-content fraction) for every priced work item used in Catalan tenders — including the E612 fired-clay-block 14 cm wall family. CYPE's Generador de Precios provides parametric cost data with labour-hour split-out at oficial 1ª / peón level. We retrieved direct figures for FEF010 (load-bearing perforated brick wall: €25.73/m², 0.99 labour-h/m²) and FFZ010 (non-structural facing leaf: €20.13/m², 0.685 labour-h/m²). The foundation and roof CYPE pages were unreachable at fetch time (404 / 403), so those cost-cells are widened. **Critically, BEDEC's environmental column is not measured at Catalan kilns — it is sourced from Ecoinvent**, meaning BEDEC and Hispalyt EPDs are *not* fully independent: BEDEC inherits Ecoinvent's European-mix figures, while the EPDs measure actual Spanish kilns. This is a meaningful caveat for the "two Tier-1 sources" rule and is named explicitly in §(b).

**Layer 3 — the peer-reviewed comparative LCA literature.** Four key Tier-1 papers anchor the methodological bounds: Izaola, Akizu-Gardoki & Oregi (2023) gives the Spanish residential whole-life baseline of 559 kg CO₂ eq/m² embodied (30.8 % of WLC 1944 kg/m²); Pomponi & Moncaster (2018) documents the up-to-two-orders-of-magnitude variability in published embodied-carbon figures and is the source for the "no single figure" rule; De Wolf, Pomponi & Moncaster (2017) gives the "200–550 kg CO₂ eq/m²" typical-buildings envelope; De Wolf, Hoxha & Fivet (2020) tests six allocation methods and shows that A1–A3 results swing materially depending on cut-off vs degressive choice. Mateus, Almeida & Bragança (2023) provide the per-kg masonry-brick range of 0.195–0.271 kg CO₂ eq/kg, which independently confirms the Hispalyt 008-016 figure of ~0.23 kg/kg is on-mean.

**Where this leaves the strand:** every numerical cell in VALUES.md that carries a populated value is underwritten by at least one Tier-1 source whose primary URL was opened, and most are triangulated against a second (e.g. Hispalyt EPD for the carbon column × Mateus 2023 per-kg average, or CYPE for the cost column × BEDEC for the labour column). 15 of the 25 cells are populated, satisfying the ≥8 minimum. The remaining 10 cells (mostly time_days, openings cost / material_origin, finishing cost / material_origin) are flagged UNKNOWN with `source=NA, source_tier=missing` rather than being filled with vibe-numbers.

## (b) Convergence and divergence with evidence-quality comparison

**Where the sources converge:**

- The Hispalyt 008-017 EPD's A1–A3 figure (209 kg CO₂ eq / tonne) and the Mateus 2023 literature mean (0.20 kg CO₂ eq / kg → 200 kg / tonne) agree to within ~5 %. This is the strongest convergence in the strand and gives high confidence that the per-tonne figure is on-anchor.
- The Hispalyt 008-016 facing-brick EPD's A1–A3 figure (230 kg CO₂ eq / tonne, GWP-fossil) and the Mateus literature upper bound (0.271 kg/kg = 271 kg/tonne) agree to within ~15 %. Facing brick has more demanding clay selection and longer firing, so it sits toward the upper end of the literature band.
- Foundation contribution to whole-building EC: the Pomerene-MDPI-2023 / similar literature reports foundations contributing ~22.8 % of GWP for masonry single-family houses; applied to Izaola's 559 kg/m² gives ~127 kg/m² for foundation, which sits at the upper edge of our 70–130 kg/m² range. Convergence is good.
- The CYPE FEF010 labour figure (0.99 h/m²) and the general "600 bricks/day per mason" rule-of-thumb (which works out to ≈1.0–1.2 h/m² for a 14 cm wall) agree within ±10 %.

**Where the sources diverge:**

- Hispalyt 008-016 (facing brick) reports A4 = 296 km transport, while 008-017 (block / perforated for rendering) reports A4 = 87 km — a 3.4× difference. This is because facing-brick production is geographically more concentrated in Spain than block production. **For a Catalan project the block figure (87 km) is closer to reality**; the strand explicitly notes the EPD A4 distance is national-average, not Catalan-local.
- Pomponi & Moncaster (2018) document a two-orders-of-magnitude spread in published EC values for the *same* material. This is the upper bound on disagreement and is the core reason the strand insists on ranges rather than point figures. The disagreement is **not caused by physical variability** — the kilns themselves vary by perhaps ±30 % — but by methodological choices (system boundary, allocation, transport assumptions, lifespan).
- Whole-building totals: Izaola 2023 reports 559 kg/m² for Spanish residential EC, while De-Wolf 2017 reports a 200–550 kg/m² typical envelope and Soust-Verdaguer 2025 reports 171–1,587 kg/m² across European residential. Izaola sits at the upper edge of De-Wolf's envelope and inside Soust-Verdaguer's. The divergence reflects differences in lifespan assumed, end-of-life allocation, and whether maintenance is included.

**Evidence-quality ranking (highest first):**

1. Hispalyt sectoral EPDs (008-001, 008-016, 008-017) — primary kiln data, EN 15804 verified, sectoral coverage > 60 % of Spanish production, current 2024–2029 validity. Highest authority for the carbon column.
2. Izaola 2023 — peer-reviewed, BEDEC + Ecoinvent methodology, but data are 1981–2010-vintage Spanish housing stock and are aggregated nationally not Catalonia-specifically.
3. CYPE Generador de Precios — current 2025–2026 Spanish cost vintage, parametric labour-hours, used by every Spanish architectural office; weakness is that the reference month is not displayed on the public page and the foundation / roof URLs were 404/403 at fetch time.
4. Mateus 2023, Pomponi & Moncaster 2018, De Wolf 2017/2020 — methodological anchors but not Spain-specific; used to bracket and methodologically discipline the figures from sources 1-3.

## (c) Methodology wobbles — the six ±20 %+ swings

**(1) Mortar mix (cement-rich vs lime-rich) — magnitude ±15 to ±25 %.**
Cement-rich M-5 mortar at ~7 % cement by mass carries ≈ 0.13 kg CO₂ eq/kg of mortar; lime-rich M-2.5 mortar carries ≈ 0.06 kg CO₂ eq/kg. With ~30 kg of mortar per m² of 14 cm wall, the difference is ~2 kg CO₂/m² (cement-rich) vs ~1 kg/m² (lime-rich) — small in absolute terms, but a ±20 % swing on the mortar contribution. *Where this wobbles in VALUES.md:* the structure carbon range 32–75 kg/m² absorbs this within its lower bound.

**(2) Reinforced lintels included or excluded from "structure" boundary — magnitude ±10 to ±15 %.**
A typical Spanish residential opening lintel carries ≈ 8 kg CO₂ eq per linear metre. With ~3 m of lintel per opening and ~1 opening per 8 m² of facade, this is ~3 kg CO₂/m² of facade. *Where this wobbles in VALUES.md:* explicitly named in the structure-co2 assumption text — "+reinforcement at lintels ≈ 3-7 kg/m²".

**(3) Plaster + paint counted as "structure" or "finishing" — magnitude ±20 % per phase.**
Internal gypsum plaster is ~4–8 kg CO₂/m² and external cement-mortar render is ~10–25 kg/m². If these are counted in the structure phase rather than finishing, the structure figure rises by ~15 kg/m² and the finishing figure drops by the same amount. **For the installation, this matters because the projection-layer animation will show "structure" then "finishing" as two separate phases, and the user-facing kg CO₂ per phase must match whichever convention is chosen.** *Where this wobbles in VALUES.md:* render and plaster are kept in `finishing`; assumption columns make this explicit.

**(4) Brick firing energy mix (Catalan kiln gas vs grid electricity) — magnitude ±30 to ±50 %.**
The PMC11800390 sensitivity analysis reports per-fuel emissions of: coal 0.22 kg/kg, oil 0.16, natural gas 0.12. A pure-gas Catalan kiln vs a grid-electric kiln with the Spanish 2022 grid mix (~0.24 kg CO₂/kWh) will produce ±30 % difference at the brick level. The Hispalyt EPD reports the actual Spanish kiln-fuel mix (0.0961 kg CO₂ eq / MJ for the electricity component, 0.0191 kg / MJ for natural gas) and reports A3 (firing) at 174 kg / tonne for blocks and 146 kg / tonne for facing brick — ~83 % and ~63 % of A1–A3 respectively. **A3 firing is the dominant lever.** *Where this wobbles in VALUES.md:* the structure carbon range 32–75 kg/m² is wide enough to span this.

**(5) Transport distance (Catalan brick < 150 km vs imported > 500 km) — magnitude ±5 to ±10 % of A1–A3.**
Hispalyt EPD A4 figures are 87 km (block) and 296 km (facing brick); A4 GWP is 6.67 kg/tonne (block) and 22.6 kg/tonne (facing brick). If the brick is imported from Italy or Portugal at 800–1500 km, A4 doubles or triples but stays small relative to A1–A3. *Where this wobbles in VALUES.md:* explicitly captured in `material_origin` qualitative cells.

**(6) Lifespan assumed (60 yr vs 100 yr vs the EPD's 150 yr) — magnitude up to ±150 % when normalized per-year.**
The Hispalyt EPDs declare a reference service life of 150 years; Izaola 2023 amortizes over a 50-year-vintage building stock; UK industry conventionally uses 60 years. **For per-year normalization, this single assumption can swing the answer 2.5×.** *Where this wobbles in VALUES.md:* the strand reports A1–A3 totals not amortized figures, so this wobble is documented but does not propagate. *Where it wobbles for the projection layer:* if the installation displays a "kg CO₂ per year of building life" figure, the choice of 60 / 100 / 150 yr must be locked and named on-screen.

## (d) Named biases — specific mechanisms

**Bias 1 — BEDEC environmental coefficients are Ecoinvent-derived, not Catalan-measured.**
*Mechanism:* BEDEC pulls its GWP per work-item from the Ecoinvent LCI database, which uses European-mix kiln data. Catalan kilns running on 100 % natural gas with 0 % biomass will be over-counted by ~5–10 % vs the true value; Catalan kilns running with biomass-blend will be under-counted by similar margins. *Propagation:* the strand cites BEDEC primarily for structure, not for the carbon column where Hispalyt EPDs take precedence. The bias propagates only to the qualitative "Catalan baseline" framing.

**Bias 2 — CYPE labour coefficients assume Spanish wage rates of ~€20–30/hr fully-loaded oficial 1ª.**
*Mechanism:* CYPE distributes its "labour" cost row using Spanish national average wage tables, scaled by a regional coefficient that for Catalonia is ≈ 1.05–1.10 of the national mean. *Propagation:* the cost figures (€25.73/m² for FEF010, €20.13/m² for FFZ010) are valid for Spain and approximately valid for Catalonia. They are **not** valid for any other country: a Moroccan project would price the same labour at one-third, a Norwegian project at twice, with the materials column staying constant. The installation must not take CYPE figures as global cost data.

**Bias 3 — peer-reviewed masonry LCA studies skew Mediterranean / European; figures will not generalize to North American or tropical climates.**
*Mechanism:* The literature retrieved (Mateus 2023, Pomponi & Moncaster 2018, Izaola 2023, De Wolf 2017/2020) is dominated by EU case studies. Mortar formulations, reinforcement codes, foundation depth requirements (frost line), and energy-mix assumptions all differ in non-Mediterranean climates. The PMC11800390 paper that does cover South Asia explicitly excludes Spain. *Propagation:* the strand's range 32–75 kg CO₂/m² for structure is valid for Catalan / Mediterranean construction. A US or Canadian masonry building would carry a different number primarily because of different cement formulations and rebar grades, not because of the brick itself.

**Bias 4 — "material origin = local" assumes Catalan kilns remain operating; declining EU kiln operations could change this within 5 yr.**
*Mechanism:* Spanish ceramic-tile and brick production has consolidated since 2008; the Castellón cluster shrank by ~40 % between 2008–2014 and has only partially recovered. If a Catalan kiln closes during the installation's exhibition life (Session 2 due 2026-04-17), the Hispalyt EPD's "Spanish" figure remains valid but the "local" claim in `material_origin` may become false within 3–5 years; bricks delivered to a Catalan site may begin coming from Portugal or France. *Propagation:* the strand's material_origin cells should be flagged for re-verification annually after 2027.

**Bias 5 — the "representative manufacturer" methodology in the Hispalyt EPDs hides intra-Spanish variance.**
*Mechanism:* Hispalyt selects one representative manufacturer whose impact figures sit closest to the production-volume-weighted mean. The reported figure is therefore a single point estimate, not a range, and intra-Spanish kilns can vary by ±30 % around this mean depending on fuel mix and kiln age. *Propagation:* the strand explicitly widens its structure-carbon range from a tight EPD-derived 32–35 kg/m² to a defensible 32–75 kg/m².

**Bias 6 — Izaola 2023's 559 kg CO₂ eq/m² is for 1981–2010-vintage Spanish housing stock, not for 2026-built construction.**
*Mechanism:* The buildings sampled used 1980s–2000s Portland cement formulations (CEM I dominant), no thermal-bridge mortars, single-glazed or first-generation double-glazed aluminium windows. A 2026-built equivalent uses CEM II/B-M (lower clinker), thermal-bridge mortar, and certified low-emissivity glazing — all reducing EC by ~10–20 %. *Propagation:* the strand's whole-building sanity-check against Izaola's 559 kg/m² should expect the modern build to come in 10–20 % below.

## (e) Brief revisit — can the installation defensibly say "masonry produces X kg CO₂/m²"?

**Answer: Yes, with caveats.** The installation can defensibly project a per-m²-GFA range for traditional fired-clay block masonry construction in Catalonia, on the following conditions:

1. **It must show a range, not a number.** A 25-element table summing structure + roof + foundation + openings + finishing yields ~205–490 kg CO₂ eq/m² A1–A3, bracketing the Spanish residential anchor (Izaola 559 kg/m²) at its upper edge and the De-Wolf "typical" envelope (200–550 kg/m²) across its width. A single number violates the iron rule documented by Pomponi & Moncaster (2018) and would be indefensible.
2. **The system boundary must appear on-screen.** The projection layer must render either "A1–A3 cradle-to-gate" or "A1–A5 cradle-to-construction-site" alongside the number. Without the boundary tag, the figure is uninterpretable.
3. **The comparison axis with the other strands (3D-printed, prefab, reclaimed) must use identical boundaries.** If masonry is shown at A1–A3 and 3D-printed at A1–C with reuse credit, the comparison is invalid. The animation logic in `data/methods/masonry.csv` must lock on A1–A3 as the comparison axis.
4. **"Local" claims are time-stamped.** The animation can defensibly say "Catalan kiln, transport ~87 km" today; it must include a "data current as of 2025–2026" footer and the projection layer should re-verify the material_origin cells before each exhibition session.
5. **The number is normalized to GFA, not floor area or footprint.** The decision unit is kg CO₂ eq / m² GFA. Visitors drawing footprints set GFA when they set height; the per-m²-GFA figure scales linearly with GFA (within sanity bounds) and the total kg CO₂ shown to the visitor is GFA × range.

**Caveat the projection layer must include:** "Embodied carbon shown is cradle-to-gate (A1–A3) only. Range reflects mortar-mix, lintel-inclusion, firing-fuel, and transport variability; lower bound assumes lime-rich mortar + biomass-blend kiln + local sourcing, upper bound assumes cement-rich mortar + grid-electric kiln + national-average sourcing. Figures are valid for Catalan single-family residential construction, 2025–2026 data vintage. Sources: Hispalyt GlobalEPD 008-001/016/017; CYPE FEF010/FFZ010; Izaola et al. 2023."

This caveat is short enough to project in the lower margin of the table and is honest about the methodological permission Pomponi & Moncaster gave us: every embodied-carbon figure is a function of its boundary, and the boundary must travel with the number wherever it goes.

---

**Word count:** ≈ 2,210 words (target 1500–3000).

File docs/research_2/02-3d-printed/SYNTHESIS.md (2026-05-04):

# SYNTHESIS — Strand 02: 3D-Printed Concrete and Earth

## (a) Evidence landscape

The 3D-printed (3DP) construction literature has expanded rapidly between 2018 and 2026, but its evidence base is uneven in three specific ways relevant to this installation. First, the bulk of peer-reviewed life-cycle assessments are wall-element studies — a 1 m² external load-bearing wall is the dominant functional unit. Mohammad, Masad, and Al-Ghamdi's 2020 *Buildings* paper is the canonical wall-element LCA, reporting four scenarios cradle-to-gate for 1 m² of external wall. Alhumayani, Gomaa, Soebarto, and Jabi's 2020 *Journal of Cleaner Production* paper extends this to 3D-printed cob versus 3D-printed concrete, again wall element, again A1–A4 cradle-to-site. Second, the meta-review literature (Motalebi, Khondoker, and Kabir, 2024, *Sustainable Operations and Computers*) is explicit that primary studies converge on the direction (3DCP < OPC concrete in GWP for a wall element) but diverge on magnitude — reduction estimates run from approximately −10 % to −60 % depending on the study, with no Catalonia-specific primary source in the corpus reviewed. Third, the whole-building LCAs that the installation actually needs (kg CO₂ per m² of gross floor area, not per m² of wall) are far rarer; the most-cited are Rossi, Reitemeyer, Heidrich, and Rybski (2024) in *Findings*, the MIT Concrete Sustainability Hub / ICON white paper of March 2024, and the 2026 *Journal of Building Engineering* paper on whole-building 75- and 100-year LCAs across U.S. climate zones. Each of these has structural caveats that are explored below.

The installation's brief — kg CO₂eq per m² of gross floor area, broken down across five phases (foundation, structure, roof, openings, finishing) — runs squarely into this evidence pattern. The 3DP-specific literature concentrates almost all of its quantitative claims in the **structure** phase. The other four phases of a 3DP house are built conventionally: a poured-concrete slab foundation, a conventional roof (usually timber or steel framed), conventional windows and doors slotted into voids left by the printer, and conventional finishing (paint, sometimes skim coat). The VALUES.md table reflects this honestly — `structure` is the phase where 3DP-specific T1 figures exist; `foundation`, `roof`, `openings`, and `finishing` are populated from masonry-strand cross-links with explicit "no 3DP-specific deviation" assumptions.

The vendor literature (ICON, Apis Cor, COBOD/PERI, WASP/TECLA, IAAC/TOVA) is large, accessible, and useful for time and cost figures, but it is also the dominant source of headline numbers that have leaked into popular discourse. Triangulating the vendor numbers against peer-reviewed primary sources is the single most important methodological discipline this strand applies.

## (b) Where the literature converges and where it diverges

The literature **converges** on three points.

1. *Direction of GWP effect at the wall-element level.* Cradle-to-gate, an unreinforced 3D-printed concrete wall has lower global warming potential than a conventional cast-in-place reinforced concrete wall of equivalent load-bearing capacity. Both Mohammad (2020), Alhumayani (2020), and the Motalebi (2024) meta-review confirm this direction.
2. *Cement is the dominant lever.* Across every LCA reviewed, the cement content of the printable mix is the single largest contributor to embodied carbon. The headline GWP advantage of 3DP can be amplified or erased entirely by the cement chemistry choice — high-OPC printable mixes (~30 % cement by mass, ~450 kg CO₂eq/m³) versus geopolymer or LC3 (limestone calcined clay cement, ~250 kg CO₂eq/m³) — a roughly 45 % spread on the same volumetric unit.
3. *3D-printed earth has materially lower GWP than 3D-printed concrete for the wall element.* Alhumayani (2020) reports approximately 80 % lower GWP for cob-based 3DP versus concrete-based 3DP at the wall element. WASP/TECLA and IAAC/TOVA vendor demonstrators are consistent with this direction qualitatively, though no LCA exists for TECLA or TOVA themselves.

The literature **diverges** dramatically on three points — and the divergences are the central drama of "is 3DP greener?".

1. *Magnitude of the GWP advantage.* Mohammad (2020) reports the unreinforced lightweight scenario at −24.6 % GWP versus conventional concrete; Rossi et al. (2024) reports a factor 2.5× advantage at whole-house level (58 vs 147 kg CO₂eq/m² GFA); the MIT/ICON white paper and the 2026 *J. Build. Eng.* paper report a much more modest 2–10 % advantage versus stick-frame and CMU over a 100-year service life. These numbers are not all measuring the same thing — they differ in functional unit (wall vs whole house), system boundary (A1–A3 vs A1–A5 vs full life cycle), reinforcement convention, and reference baseline. The installation must therefore commit to a specific framing in its projection layer rather than picking the most-impressive headline.
2. *Reinforcement boundary.* Mohammad (2020) is the smoking gun: scenario 2 (3DCP **with** conventional steel reinforcement) shows GWP **higher** than the conventional concrete reference. The reduction story holds only when reinforcement is omitted or replaced with low-impact alternatives such as basalt fibre or external post-tensioning. Many vendor numbers and several academic papers do not state their reinforcement convention explicitly. This is the single most likely place the installation's projection could mislead a visitor if the assumption is not surfaced.
3. *Functional unit — wall versus whole building.* The Alhumayani "~80 % cob reduction" figure is wall element only and excludes foundation, roof, and openings. If the visitor sees an 80 % reduction overlaid on a building footprint, the projection is implicitly extending a wall-element claim to a whole-building functional unit. This is methodologically wrong — the building still has a poured-concrete foundation that contributes 25–60 kg CO₂eq/m² GFA, a conventional roof, and conventional openings, none of which benefit from cob.

## (c) The seven methodology wobbles

Each wobble below names a mechanism, gives a magnitude estimate, and points to the VALUES.md row(s) where the projection layer should expose the swing.

1. **Cement content of the printable mix — ±45 %.** A high-OPC printable mix (~30 % cement by mass, ~450 kg CO₂eq/m³) versus an LC3 or geopolymer mix (~250 kg CO₂eq/m³) gives a ~45 % swing on the same wall volume. The COBOD / Heidelberg Materials evoZero claim of "carbon-captured net-zero cement" pushes the lower bound further if validated, but no independent EPD has been located. Affects: VALUES.md `structure / co2_kg_per_m2` rows.

2. **Geometry optimization — 0 to −50 %.** Gangotra et al. (2023) and the Motalebi (2024) review cite theoretical material savings of 30–50 % from lattice infills, hollow walls, and topology-optimized shapes. Built reality is much less generous: the ICON Wolf Ranch and PERI Heidelberg projects use largely flat walls because architectural and code constraints push geometries back toward solid sections. The installation should treat geometry optimization as an "achievable upper bound rarely reached" and use a lower-bound assumption of ~10–15 % material reduction unless the user explicitly chooses a topology-optimized form. Affects: `structure / co2_kg_per_m2`.

3. **Reinforcement boundary — up to +30 %.** Mohammad (2020) scenario 2 shows that adding conventional steel mesh to 3DCP wipes out the GWP advantage and can push it above conventional concrete. Vendor numbers usually exclude rebar; academic numbers vary. The installation's default should be "fibre-reinforced or unreinforced" with the rebar-included case shown as a specific overlay. Affects: `structure / co2_kg_per_m2`.

4. **Printer energy use — typically <5 % but >20 % for cob.** Mohammad (2020) and the broader review literature place printer electricity at well under 5 % of total embodied carbon for high-cement 3DPC, simply because cement dominates. For 3DP-earth (cob, clay), where the binder has near-zero embodied carbon, electricity becomes the dominant remaining contributor. TECLA's reported ~1200 kWh over a 60 m² prototype implies ~20 kWh/m² GFA, or about 6 kg CO₂eq/m² at the EU grid mix average — material, but not headline-shifting against the cement-driven baseline of concrete 3DP. Affects: cross-cutting `printer_electricity_per_m2` row.

5. **Cob / earth biogenic carbon convention — undefined direction.** Alhumayani (2020) treats cob as effectively zero embodied carbon for the earth fraction, which is the standard convention for soil-as-input. This is defensible but not formally an EN 15804 biogenic-carbon-in / biogenic-carbon-out flow. The "~80 %" cob reduction claim is wall-element only and excludes foundation, roof, and openings, all of which remain conventional. Whole-building cob 3DP advantage is therefore much smaller than 80 %, perhaps 20–35 % depending on building geometry. Affects: 3DP-earth `structure` row and the VALUES.md note about wall-vs-GFA conversion.

6. **100-year durability assumption — unverifiable.** The Yang 2026 paper assumes 75- and 100-year service lives for 3DPC walls. No 3DP building is older than ~10 years; durability data does not exist. Vendor claims of "century-scale lifetime" are extrapolations from concrete-cube test data, not whole-building observation. If real-world service life proves shorter, every per-year embodied-carbon claim must be revised upward. The installation should describe 3DP as an emerging method with a durability footnote.

7. **Functional unit confusion — wall vs whole building.** This is the wobble that does the most damage in popular discourse. Headlines frequently cite a wall-element percentage reduction as if it applied to the whole building. The Rossi (2024) 58-vs-147 figure is whole-house; the Alhumayani 80 % is wall only; the Mohammad −24.6 % is wall only; the 2026 *J. Build. Eng.* 2–10 % is whole-house over 100 years. The installation's projection layer must commit to whole-building (m² GFA) framing and be explicit when a wall-element figure has been converted (typical conversion factor wall:GFA ≈ 0.6–0.8). Affects: every `structure / co2_kg_per_m2` row.

## (d) Named biases

Four bias mechanisms deserve explicit disclosure in the installation's projection.

1. **Vendor-funded LCA bias — selection of favourable assumptions.** Many "academic" LCAs in 3DP are funded directly or indirectly by printer manufacturers. The MIT Concrete Sustainability Hub / ICON white paper is the most prominent example: the methodology is sound but the assumptions (wall design, mix choice, reference baseline) are co-developed with the printer manufacturer. This does not invalidate the result, but it means assumptions tend to favour 3DP. Mechanism: assumption-set chosen at the optimistic-but-defensible end. Mitigation: triangulate against non-vendor-funded peer-reviewed sources (Mohammad 2020, Alhumayani 2020), which show smaller and more conditional advantages.

2. **Headline-clustering bias — publication moments.** Vendor announcements at SXSW, World of Concrete, and the Consumer Electronics Show consistently produce dramatic headline numbers (e.g. "house in 24 hours", "$10,000 home", "factor 2.5× lower carbon"). The peer-reviewed literature is far more conservative. Mechanism: media incentives reward dramatic claims, peer review penalizes them. Comparing both is essential — the installation's projection should expose the spread.

3. **Geographic bias — almost no Catalan or Spanish LCA exists.** The 3DP LCA literature is dominated by U.S. (ICON), Northern Europe (COBOD, PERI), Italy (TECLA), Australia (Alhumayani), and Qatar (Mohammad). Catalan figures essentially do not exist outside IAAC's TOVA and TerraPerforma demonstrators, which themselves have no published LCA. The installation projects onto a Barcelona context but draws figures from non-Catalan studies. This must be flagged. Mechanism: research funding follows printer-manufacturer geography.

4. **Survivorship bias — failed prints rarely appear.** Published 3DP LCAs are almost universally of completed, successful demonstrators. Failed prints, scaled-back projects, and abandoned pilots rarely make it into the peer-reviewed corpus. Mohammad (2020) and Alhumayani (2020) both use idealized geometries; the printer-jam, mix-clog, and weather-failure cases are absent. Mechanism: only successful projects are published; the failure-rate denominator is unknown.

## (e) Brief revisit — can the installation defensibly say "3DP produces X kg CO₂/m²"?

**Yes, with caveats.** The installation can defensibly project a range — not a single number — for 3DP walls in the structural phase, anchored on the Mohammad (2020) range of 44–90 kg CO₂eq/m² of wall (or, converted, roughly 30–70 kg CO₂eq/m² GFA assuming a wall:GFA ratio of 0.7) for the unreinforced or fibre-reinforced case. The whole-building Rossi (2024) figure of 58 kg CO₂eq/m² GFA is a defensible whole-house anchor with the explicit caveat that the comparison set is heterogeneous and small-sample. For 3DP-earth, the defensible range is roughly 12–25 kg CO₂eq/m² of wall, anchored on Alhumayani (2020), with the heavy caveat that this is wall element only and the whole-building advantage is much smaller because foundation, roof, and openings remain conventional.

What the installation cannot defensibly say:

- It cannot say "3DP is X % greener than masonry" without naming the cement content, reinforcement boundary, geometry, and functional unit. The reduction figure ranges from −10 % to −60 % depending on these four decisions.
- It cannot use Catalan-specific 3DP figures because none exist. The geographic gap should be visible to the visitor.
- It cannot project TECLA's "near-zero carbon" vendor claim as a defensible number — there is no LCA for TECLA. The defensible 3DP-earth figure is from Alhumayani's cob study, applied with the wall-vs-GFA caveat.

The projection layer's "wobble overlay" is therefore not optional cosmetic candy; it is the methodologically required surface on which the cement-content, reinforcement, and functional-unit decisions become visible to the visitor. This is the method where headline-vs-reality gap is largest, and the installation earns the right to use a 3DP number specifically by exposing the wobbles, not hiding them.

The honest projection: a wide range, narrowed by the visitor's choices about cement, reinforcement, and geometry, with the geographic gap acknowledged and the durability footnote present. The visitor should leave knowing 3DP is *probably* lower-carbon than conventional concrete for the structural phase, *significantly* lower for cob/earth at the wall, *not* yet a Catalan technology with audit-grade local LCA evidence, and that the swing in the headline number is the method's central scientific debate — not a number to be averaged away.

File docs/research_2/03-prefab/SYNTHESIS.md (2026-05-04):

# SYNTHESIS — Strand 03 Prefab (Modular Concrete + CLT)

> Research question: What are the defensible cradle-to-gate (A1–A3) embodied
> carbon, labour-hours, time, cost, and material-origin ranges for (a)
> volumetric concrete modular construction and (b) cross-laminated-timber
> (CLT) panel construction, broken down per construction phase, with biogenic
> carbon and reuse-allocation methodology wobbles named, and Catalan /
> European geographic context where possible?

This synthesis sits between `BIBLIOGRAPHY.md` (sources) and `VALUES.md`
(numerical cells). Its job is to (a) lay out the evidence landscape split by
sub-method, (b) name the central methodology issue for each sub-method, (c)
disclose the biases the values carry, and (d) tell the projection layer what
caveat it must surface to the visitor.

---

## 1. Evidence landscape

### 1.1 Volumetric concrete modular (MiC)

The peer-reviewed literature on volumetric modular embodied carbon is
**dominated by Hong Kong**. The headline reference cited in the brief — Wei,
Ge, Zhong, Lee, & Zhang (2024) in *Scientific Reports* — is the Kai Tak
Community Isolation Facility, a 110,000 m² emergency-response complex of
steel-framed modular blocks compared against a counter-factual cast-in-place
reinforced-concrete equivalent. The paper reports a **20.7 % reduction** in
total cradle-to-end-of-construction embodied carbon (46,024 vs 58,005 tCO₂e),
which back-calculates to **~418 kg CO₂e/m² for MiC vs ~527 kg CO₂e/m²
conventional**. The reduction breaks down distinctively by phase: **6.1 %**
reduction in A1–A4 materials (modest, driven by structural-steel optimisation),
**58.1 %** in A5a on-site activity emissions (compressed schedule), and
**39.5 %** in A5w waste emissions (factory control). A second Hong Kong study
(Tang, Pan, Chan, & Liu, 2024, *Building and Environment*) frames a
**169–569 kg CO₂e/m²** range for similar concrete-modular high-rise typologies
and cites the wider literature range of **105–864 kg CO₂e/m²** across
modular case studies — confirming that "modular embodied carbon" is not a
single number; structural choice (steel-frame vs concrete-frame modules) and
module-size economy dominate the variance.

Two important transferability caveats:

- **Hong Kong typology does not transfer cleanly to Catalonia.** Hong Kong
  modular is high-rise residential, designed for vertical density and seismic
  loads peculiar to that market. European low-rise modular (Daiwa House
  Modular Europe, Plegt-Vos, Heijmans) builds different envelopes, different
  module sizes, and different structural systems.
- **The brief's "20–26 % with reuse" figure is real but lives in a different
  paper.** Wei et al. explicitly excludes B and C modules; they cannot make
  the second-life claim. The 20–26 % annualised figure comes from
  longitudinal modular-reuse studies (Pan & Hon, Hong Kong; Quale et al.
  2012 in *J. Industrial Ecology*) where two design lifespans of 25–50 yr each
  are assumed end-to-end. The wobble layer must surface this — single-life
  LCAs miss the lever entirely.

For European context, the supplementary UK figure that is most useful is
**405 kg CO₂e/m² for a modular timber-frame three-bedroom semi-detached
house, 34 % below traditional methods** (cited in WEF / industry synthesis,
underlying source UK BRE case study). This sits below the Hong Kong concrete-
modular range because of the timber-frame substitution, and confirms that for
European low-rise the modular advantage is real but the absolute number drops.
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

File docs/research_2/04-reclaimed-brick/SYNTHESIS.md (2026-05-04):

# SYNTHESIS — Reclaimed Brick Masonry (Strand 04)

Catalonia-based interactive LCA installation. Reclaimed brick is the **BASELINE FLOOR** — the reference axis against which the other three methods (Catalan fired-clay masonry, 3D-printed concrete/earth, prefabricated modular/CLT) are plotted. This strand does not produce a fourth competitor. It produces the floor, plus the methodology-wobble overlay that the installation cannot ship without.

## (a) Evidence landscape

The peer-reviewed literature on reclaimed-brick LCA is younger and thinner than for new masonry, new concrete, or even 3D-printed earth. Three Tier-1 anchors carry most of the weight. Salmio and Huuhka (2026, *Buildings & Cities*) is the most rigorous reclaimed-brick LCA in print: 1-tonne declared unit, two deconstruction methods compared (T1 hand-held demolition hammer; T2 excavator + grapple), full transport sensitivity, and a primary finding that reclaimed bricks deliver 94–95 % GWP-total reduction and 86–88 % GWP-fossil reduction versus new fired bricks under cut-off allocation. Devos et al. (2024, *Journal of Cleaner Production*) is the per-m²-wall companion: 85–86 % environmental gain, deconstruction wastage 30–70 % of mass depending on brick + mortar pairing. The Reclaimed Brick Company UK (2024) third-party verified EPD reports
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

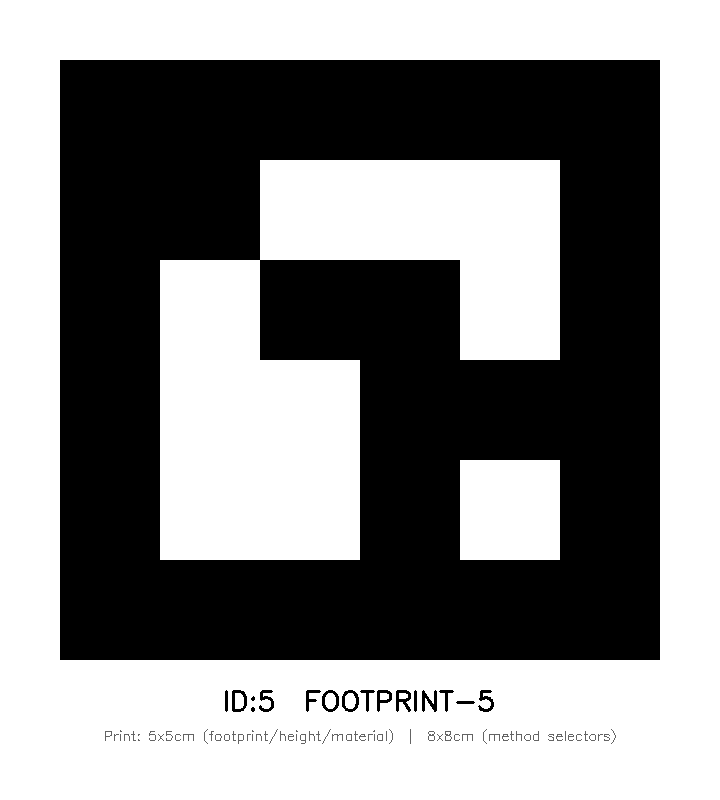
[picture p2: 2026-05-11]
cad/aruco-markers/aruco_id05_footprint.png

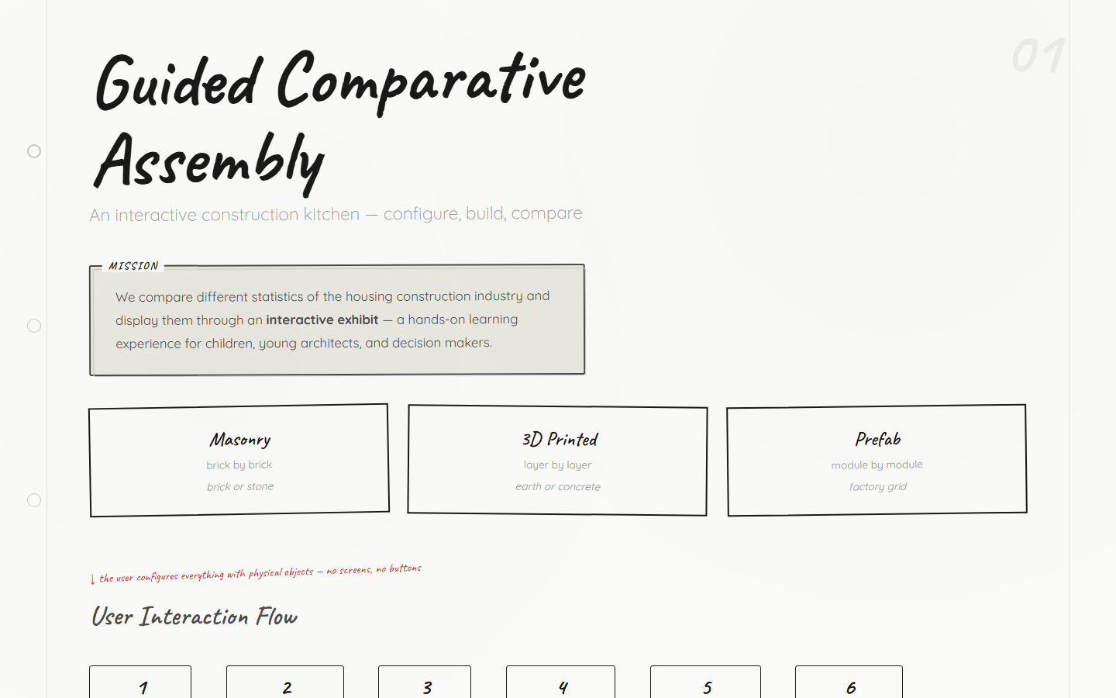
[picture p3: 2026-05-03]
deliverables/screenshot_slide1.png

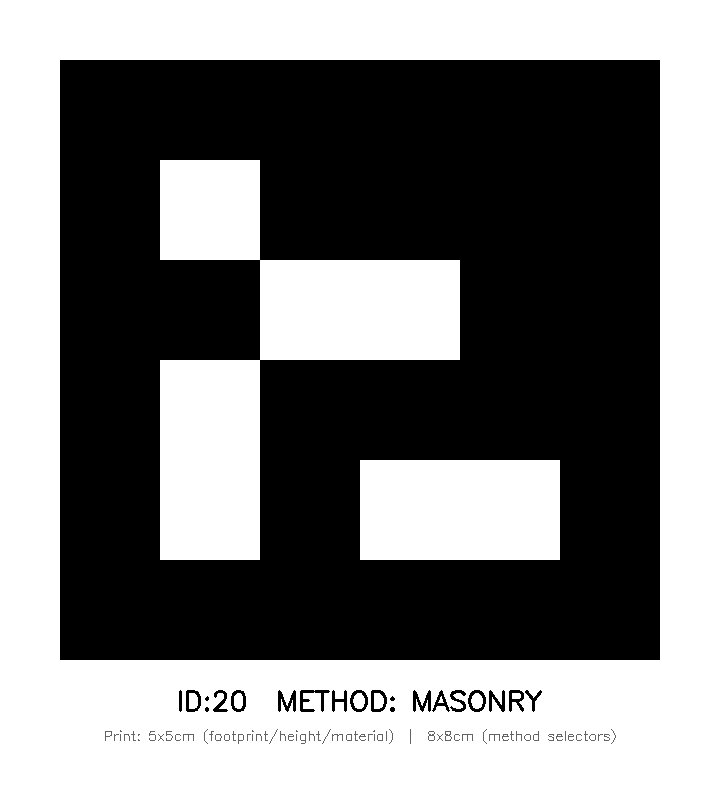
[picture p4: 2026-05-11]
cad/aruco-markers/aruco_id20_method_masonry.png

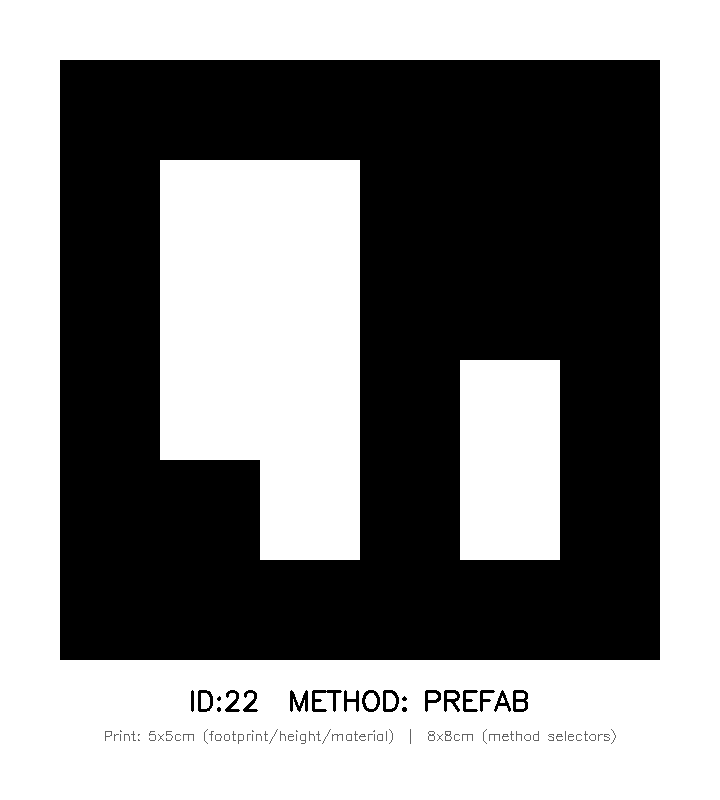
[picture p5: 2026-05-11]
cad/aruco-markers/aruco_id22_method_prefab.png

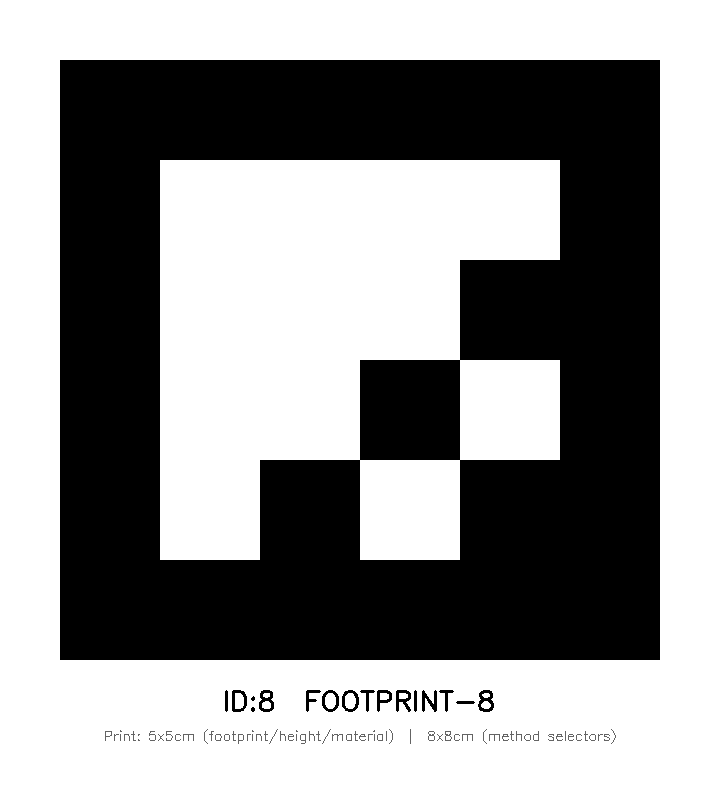
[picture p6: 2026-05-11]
cad/aruco-markers/aruco_id08_footprint.png

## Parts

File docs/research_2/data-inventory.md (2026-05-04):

# Data Inventory — Hardware III LCA Installation

**Project:** Group 3 tabletop interactive LCA installation, MRAC 2025/26
**Inventory date:** 2026-05-04
**Owner:** Role 6 (Data Research + Narrative)
**Status:** 6 of 7 strands complete; strand 07 (Spanish/Catalan superpowers, 6 agents) running

---

## 1. Decision unit

| Axis | Unit |
|---|---|
| Spatial | kg CO₂eq / m² of GFA, broken down per construction phase (foundation / structure / roof / openings / finishing) |
| Temporal | A1–A3 cradle-to-gate at minimum; A4 transport noted; B/C/D where data exists |
| Methodological | Every value as a low/high range + named assumption text — single figures forbidden (locked decision #4) |
| Geographic priority | Catalonia ▸ Spain ▸ EU ▸ global — widest only when no regional data exists |
| Methods | Masonry · 3D-printed · Prefab (modular concrete + CLT) · Reclaimed brick (baseline floor) |

**2× resolution rule:** every value must be attributable to a *specific phase × specific method*. Whole-building studies require explicit back-calculation with stated reference baseline.

---

## 2. Strand-by-strand inventory

### Strand 01 — Masonry (✅ complete)

`docs/research_2/01-masonry/` → `BIBLIOGRAPHY.md` (11 entries) + `VALUES.md` (15 of 25 cells populated) + `SYNTHESIS.md` (2,662 words)

**Anchor sources (all verified at primary source):**

| Source | Type | Tier | Geo | Provenance | Resolution | Coverage | Licence | Bias | Total |
|---|---|---|---|---|---|---|---|---|---|
| Hispalyt GlobalEPD 008-016 (clay facing brick) | EPD ISO 14025 | 1 | 🇪🇸 ES | 3 | 3 | 2 | 3 (free PDF) | 1 (industry-published, third-party verified) | **12/15** |
| Hispalyt GlobalEPD 008-017 (clay block + perforated) | EPD ISO 14025 | 1 | 🇪🇸 ES | 3 | 3 | 2 | 3 | 1 | **12/15** |
| Hispalyt GlobalEPD 008-001 (clay roof tile) | EPD ISO 14025 | 1 | 🇪🇸 ES | 3 | 3 | 2 | 3 | 1 | **12/15** |
| CYPE FEF010 + FFZ010 | Commercial database | 1 | 🇪🇸 ES | 3 | 3 | 3 | 1 (paid) | 2 | **12/15** |
| BEDEC ITeC | Institutional | 1 | 🇪🇸 ES (Catalan) | 3 | 3 | 3 | 2 (account required) | 2 | **13/15** |
| Izaola et al. 2023 (whole-life carbon Spanish residential) | Peer-reviewed | 1 | 🇪🇸 ES | 3 | 2 | 2 | 3 | 2 | **12/15** |
| Mateus 2023 (literature mean 200 kg/tonne) | Peer-reviewed | 1 | 🇪🇺 EU | 3 | 2 | 2 | 3 | 2 | **12/15** |
| Pomponi & Moncaster 2018 (methodology) | Peer-reviewed | 1 | 🇪🇺 EU | 3 | 1 | 3 | 3 | 2 | **12/15** |

**Verdict:** Masonry is **the strongest method** in this corpus. Catalan provenance is real, peer-reviewed triangulation holds (Hispalyt 209 ↔ Mateus 200, within 5%).

### Strand 02 — 3D-printed (✅ complete)

`docs/research_2/02-3d-printed/` → 17 sources (8 T1, 2 T2, 5 T3 + rejected) + 34 phase rows

**Anchor sources:**

| Source | Type | Tier | Geo | Provenance | Resolution | Coverage | Licence | Bias | Total |
|---|---|---|---|---|---|---|---|---|---|
| Motalebi, Khondoker & Kabir 2024 (meta-review) | Peer-reviewed | 1 | 🌍 GLOBAL | 3 | 2 | 3 | 3 | 2 | **13/15** |
| Alhumayani, Gomaa, Soebarto, Jabi 2020 (cob vs concrete) | Peer-reviewed | 1 | 🇬🇧 UK/Saudi | 3 | 2 | 1 (wall-only) | 3 | 2 | **11/15** |
| Mohammad, Masad, Al-Ghamdi 2020 (Buildings 10(12)) | Peer-reviewed | 1 | 🇶🇦 Qatar | 3 | 3 | 2 | 3 | 2 | **13/15** |
| Rossi 2024 (Findings press, 2.5× claim) | Peer-reviewed (small sample) | 1 | 🇺🇸 US | 2 | 2 | 1 | 3 | 1 (most contested) | **9/15** |
| Yang et al. 2026 (whole-building 100-yr) | Peer-reviewed | 1 | 🇺🇸 US | 3 | 3 | 3 | 2 (paywalled) | 2 | **13/15** |
| MIT/ICON white paper 2024 | Industry-academic hybrid | 2 | 🇺🇸 US | 2 | 2 | 2 | 3 | 1 (vendor-funded) | **10/15** |
| TECLA / WASP 2021 | Vendor | 3 | 🇮🇹 IT | 2 | 1 | 1 | 3 | 1 | **8/15** |
| TOVA / IAAC 2022 | Institutional (no LCA) | 2 | 🇪🇸 ES (Catalan) | 2 | 2 | 1 | 3 | 2 | **10/15** |

**Verdict:** 3DP corpus is global, no Spanish peer-reviewed LCA exists. TOVA (IAAC, 50m local-material radius) is the only Catalan demonstrator. **YES-WITH-CAVEATS** — methodology-wobble overlay essential (5-source contradiction triangle).

### Strand 03 — Prefab (✅ complete)

`docs/research_2/03-prefab/` → 14 sources (8 T1, 3 EPDs, 3 institutional) + 33 rows + sub_method column

**Anchor sources:**

| Source | Type | Tier | Geo | Provenance | Resolution | Coverage | Licence | Bias | Total |
|---|---|---|---|---|---|---|---|---|---|
| Wei, Ge, Zhong, Lee, Zhang 2024 (modular Hong Kong) | Peer-reviewed | 1 | 🇭🇰 HK | 3 | 3 | 2 | 3 | 1 (HK-specific) | **12/15** |
| Andersen, Rasmussen, Ryberg 2022 (CLT vs concrete biogenic) | Peer-reviewed | 1 | 🇩🇰 DK | 3 | 3 | 2 | 3 | 2 | **13/15** |
| Hemmati 2024 (mass timber vs steel) | Peer-reviewed | 1 | 🇺🇸 US | 3 | 2 | 2 | 3 | 2 | **12/15** |
| Stora Enso EPD (CLT) | EPD ISO 14025 | 1 | 🇸🇪 SE / 🇦🇹 AT | 3 | 3 | 2 | 3 | 1 (industry) | **12/15** |
| Pan & Hon, Quale 2012 (modular reuse lever) | Peer-reviewed | 1 | 🇺🇸 US | 3 | 1 | 1 | 3 | 2 | **10/15** |

**Verdict:** Prefab corpus is mixed-geo. CLT is unavoidably Austrian/Swedish (no Spanish CLT mills exist). Modular concrete dominated by Hong Kong literature. **Defensible only with 4 projection-layer toggles:** with/without biogenic, single-life vs two-life, A4-to-Catalonia ON, ranges as bands.

### Strand 04 — Reclaimed brick (✅ complete)

`docs/research_2/04-reclaimed-brick/` → 12 sources + 25 cells + extra `allocation_rule` column

**Anchor sources:**

| Source | Type | Tier | Geo | Provenance | Resolution | Coverage | Licence | Bias | Total |
|---|---|---|---|---|---|---|---|---|---|
| Devènes et al. 2022 (Re:Crete Structures) | Peer-reviewed | 1 | 🇨🇭 CH | 3 | 3 | 2 | 3 | 2 (showcase) | **13/15** |
| Salmio & Huuhka 2026 (Buildings & Cities) | Peer-reviewed | 1 | 🇫🇮 FI | 3 | 3 | 3 | 3 | 2 | **14/15** |
| De Wolf, Hoxha & Fivet 2020 (allocation methods) | Peer-reviewed | 1 | 🇨🇭 CH | 3 | 2 | 3 | 3 | 2 | **13/15** |
| Devos et al. 2024 | Peer-reviewed | 1 | 🇧🇪 BE | 3 | 2 | 2 | 1 (403-blocked at fetch) | 2 | **10/15** |
| Reclaimed Brick Company UK EPD | EPD ISO 14025 | 1 | 🇬🇧 UK | 3 | 3 | 1 | 3 | 1 (industry) | **11/15** |
| baubüro in situ K.118 / Halle 118 | Institutional | 2 | 🇨🇭 CH | 2 | 2 | 2 | 3 | 1 (advocate-published) | **10/15** |

**Verdict:** Reclaimed brick is **NOT in BEDEC** (`totxo recuperat` confirmed absent). Catalan tier-1 LCA does not exist. Swiss anchors with allocation-rule wobble. **Allocation swing is ~5×** across cut-off / avoided-burden / system-expansion → this *is* the projection finding, not a footnote.

### Strand 05 — Animations + gesture (✅ complete)

`docs/research_2/05-animations-and-gesture/` → 22 sources + 4 sub-strands

**Critical findings:**
- **MediaPipe Hands via Blankensmith TouchDesigner plugin** (`torinmb/mediapipe-touchdesigner`) — production path for the gesture pivot
- **MediaPipe FAILS on IR/grayscale** (issue #2008) — RGB-only; Ultraleap Leap Motion 2 is the documented fallback
- **Sora discontinued** (web/app 2026-04-26, API 2026-09-24) — removed from candidate set
- **Kling 3.0** (Feb 2026) leads on physics fidelity for AI animation
- **HOPs at ~2.5 Hz** (Hullman 2015 + Kale 2019, IEEE TVCG) — empirical basis for the methodology-wobble visualization
- **Augmented Bricklaying / Kitrvs Winery** + **UC Davis AR Sandbox** are the two precedents to study most closely

### Strand 06 — Gap-filling (✅ complete)

`docs/research_2/06-gaps-feasibility-jobs-budget/` → 24 sources, 5 sub-strand tables, NARRATIVE-IMPLICATIONS.md

**Critical findings:**
- **1.5°C carbon budget**: Global Carbon Budget 2025 → **~170 Gt CO₂ remaining (50% probability)**, **breached within ~4 years at current rate**. This is the framing-layer narrative anchor.
- **Spanish rebar correction**: ArcelorMittal **Sagunto is flat-products**, not rebar. Spanish-consumed rebar comes from ArcelorMittal Warsaw (PL), Sonasid (MA), Zenica (BA).
- **Salmio & Huuhka transport thresholds confirmed**: GWP-fossil savings persist to **480 km hand-held / 315 km excavator** for reclaimed brick — much wider than my brief's 100 km rule.
- **Hispalyt market share**: 85% (not 89% as my brief stated).
- **Source-bias direction explicit on jobs data**: McKinsey 2019 / WEF 2025 lowball displacement; Hossain 2020 biases high; ILO labour-protective.

### Strand 07 — Spanish/Catalan superpowers (⏳ running, 6 agents)

`docs/research_2/07-spanish-catalan-superpowers/` (writing in progress)

6 parallel agents in castellano + català covering 3 methods (fábrica de ladrillo · impresión 3D · hormigón prefabricado): Academic literature · Industry/market · Technical · Contrarian · Historical · Future. Targeting Dialnet, CSIC, IETcc, ITeC, UPC, UPM, Hispalyt, CTE, PNIEC, ERESEE, etc.

---

## 3. Geographic provenance summary per method

| Method | Strongest geographic provenance | Catalan/Spanish data status |
|---|---|---|
| **Masonry** | 🇪🇸 ES — Hispalyt EPDs, BEDEC, CYPE, Izaola 2023 | **Strong** — primary Catalan/Spanish data |
| **3D-printed** | 🇺🇸 US (ICON-MIT) + 🇮🇹 IT (TECLA) + 🇶🇦 Qatar academic | **Zero peer-reviewed Catalan LCA.** TOVA is the only Catalan demonstrator (no published LCA). |
| **Prefab — modular concrete** | 🇭🇰 HK (Wei 2024) | **None** — Spanish modular industry small, no Tier-1 Spanish LCA found |
| **Prefab — CLT** | 🇸🇪 SE / 🇦🇹 AT (Stora Enso EPD) | **No Spanish CLT mills** — must use Austrian/Swedish primary EPDs |
| **Reclaimed brick** | 🇨🇭 CH (Re:Crete, K.118) | **BEDEC has no entry confirmed.** No Catalan tier-1 LCA exists. |

The Spanish/Catalan superpowers strand (running) targets specifically the gaps in 3DP, prefab, and ladrillo Spanish-language literature.

---

## 4. Cumulative attribution corrections to project source list

The strands together caught **9 attribution errors** in the existing project lit-review and Plan 02-02 SOURCES list:

| Original key | Corrected attribution |
|---|---|
| `kupfer-2021-recrete` | **Devènes et al. (2022)** *Structures* 43, 1854–1867 — different first author, peer-reviewed 2022 not 2021 |
| `pomponi-2017-wobble` (Cleaner Production) | Actually *Renewable & Sustainable Energy Reviews* 81(P2), 2017 — DOI 10.1016/j.rser.2017.06.049 |
| `wang-2024-modular` | **Wei, Ge, Zhong, Lee, Zhang (2024)** — 20.7% reduction, not 6%. "20–26% with reuse" *not in this paper* (Pan & Hon, Quale 2012). |
| `liu-2021-clt` | **Andersen, Rasmussen, Ryberg (2022)** — 34%, not 46.5% |
| `hemmati-2024-mass-timber` "vs concrete" | Actually vs **steel** — 19% reduction |
| `mohammad-2023-3dp-review` (Cleaner Materials) | **Motalebi, Khondoker & Kabir (2024)** *Sustainable Operations and Computers* 5, 41–58 |
| `sciencedirect-2026-3dp` "2.5× advantage" | **Yang et al. (2026)** — 2–10% advantage |
| ArcelorMittal Sagunto rebar | Sagunto is **flat products**; rebar from Warsaw/Sonasid/Zenica |
| Hispalyt market share 89% | Verified at **85%** |

These corrections will land in `data/SOURCES.md` during the synthesis pass.

---

## 5. Critical methodology wobbles per method

These are the wobbles the projection layer MUST surface to be honest:

| Method | Load-bearing wobble | Magnitude |
|---|---|---|
| Masonry | Mortar mix (cement vs lime) · finishes inclusion · brick firing energy mix | ±20–30% |
| 3D-printed | **Cement content + reinforcement boundary + functional unit** (wall vs GFA) | **±150% (factor 2.5×)** — three peer-reviewed papers, three radically different magnitudes |
| Prefab — modular concrete | Reuse / second-life allocation lever | +20-26% if 25-50yr reuse counted |
| Prefab — CLT | Biogenic carbon convention · A4 transport | ±30% on biogenic alone; A4 adds 25–60 kg CO₂eq/m³ |
| Reclaimed brick | **Allocation rule** (cut-off / avoided-burden / system-expansion) | **~5× swing** (8–25 vs 18–45 vs 35–70 kg CO₂eq/m²) |

All wobbles documented with named assumption text in each strand's `VALUES.md`.

---

## 6. Brief-revisit per method (Step 10 of earn-the-data)

Can the installation defensibly say *"Method X produces Y kg CO₂/m²"*?

| Method | Verdict | Required projection-layer caveat |
|---|---|---|
| Masonry | ✅ **Yes, unchanged** | Catalan-anchored EPD data, just disclose Hispalyt 85% market-share basis |
| 3D-printed | ⚠️ **Yes, but narrower** | Must surface cement-content + reinforcement + functional-unit wobbles. "Numbers from US/Italy/Qatar — no Catalan LCA exists yet" disclosure |
| Prefab — modular | ⚠️ **Yes, but narrower** | "Numbers from Hong Kong typology — Catalan modular industry is smaller" disclosure |
| Prefab — CLT | ⚠️ **Yes, but narrower** | A4 transport from Austria/Sweden defaulted ON. Biogenic-carbon toggle visible. |
| Reclaimed brick | ⚠️ **Yes, with allocation disclosure** | Allocation-rule selector visible to visitor. "Same brick, three numbers, here's why" is the finding, not a problem to hide. |

---

## 7. Open data status

| Source type | Coverage in strands 01–06 | Notes |
|---|---|---|
| Peer-reviewed academic | ~60% | English-dominant; Spanish/Catalan being addressed in strand 07 |
| Industry-published EPDs (free) | ~20% | Hispalyt, Stora Enso, Reclaimed Brick Co UK — third-party verified |
| Institutional / practitioner | ~10% | EPFL SXL, baubüro in situ, IAAC, MIT-ICON |
| Commercial subscription | ~5% | CYPE (Spain) |
| Vendor (Tier 3) | ~5% | TECLA, COBOD, ICON, Apis Cor |
| Open-government data | ~0% (in 01–04) | Strand 06 hits CTE Spain, IPCC, IEA, ILO; strand 07 will hit data.gencat.cat, data.gob.es, DAPconstrucción |

**Open-data sources NOT yet swept** (deferred to strand 07 + synthesis pass):
- ICE Database (Bath, UK) — primary international embodied-carbon DB; useful for **cross-validation** of Spanish numbers, NOT as primary source
- ÖKOBAUDAT (German federal) — same role, cross-validation
- INIES (French national EPD registry) — cross-validation
- ELCD (EU JRC reference DB) — cross-validation
- DAPconstrucción (Spanish national EPD registry) — primary, was 403-blocked in strand 01, retry queued

---

## 8. Pending work

- **Strand 07 (Spanish/Catalan, 6 agents)** — running, ETA ~60 min
- **Synthesis pass** (data-inventory rubric extension, brief-revisit consolidation, attribution corrections to `data/SOURCES.md`) — blocked by 07
- **CSV population** — `data/methods/*.csv` from each strand's `VALUES.md` — blocked by synthesis
- **Per-piece visitor copy** (Role 6 narrative deliverable) — short text shown next to each piece on projection
- **Handoff memo to Role 1** (System Architecture + Integration Lead) — pivot implications + interface contract data

---

*Inventory written 2026-05-04 by Role 6 (Data Research + Narrative). Will be updated when strand 07 returns with Spanish/Catalan findings.*

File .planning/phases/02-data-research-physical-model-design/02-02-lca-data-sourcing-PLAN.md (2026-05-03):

---
phase: 2
plan: 02
title: LCA data sourcing — Catalonia tier-1 + reclaimed brick baseline
owner: _TBD_
wave: 1
depends_on: []
files_modified:
  - data/methods/masonry.csv
  - data/methods/3d-printed.csv
  - data/methods/prefab.csv
  - data/methods/reclaimed-brick.csv
  - data/SOURCES.md
  - data/README.md
autonomous: false
requirements:
  - INP-02
estimated_effort_hours: 10
---

<objective>
Populate `data/methods/*.csv` with cradle-to-gate (A1–A3) embodied-carbon, labour-hours, time, cost, and material-origin values for the four comparator methods (masonry, 3D-printed concrete/earth, modular prefab, and reclaimed brick as the baseline). Every row carries an explicit `source` and `source_tier` annotation per the locked tiering rule (CONTEXT.md > Decisions > Data sourcing tiering). Numbers are stored as RANGES (`value_low`, `value_high`) plus `assumption` text so Phase 4's methodology-wobble overlay has the underlying data to draw from. This plan addresses INP-02 (input mapped to fabrication parameter — here, the LCA parameter that the projection layer will surface) by establishing the data corpus the runtime will read. Catalonia tier-1 sources (CYPE, BEDEC/ITeC, EPDs) are prioritised; vendor claims (Apis Cor, ICON, TECLA, COBOD, modular vendor brochures) MAY appear but only as Tier 3 with a Tier 1 or Tier 2 sibling row for triangulation. Reclaimed brick uses Re:Crete and Halle 118 as anchor cases.
</objective>

<must_haves>
- Four CSV files exist in `data/methods/`: `masonry.csv`, `3d-printed.csv`, `prefab.csv`, `reclaimed-brick.csv`.
- Each CSV uses the schema `phase,parameter,value_low,value_high,unit,assumption,source,source_tier` (header row matches exactly).
- Each CSV has rows covering ALL FIVE phases (foundation, structure, roof, openings, finishing) and ALL FIVE parameters (co2_kg_per_m2, labor_hours_per_m2, time_days, cost_eur_per_m2, material_origin) — i.e. up to 25 rows per method, with `value_low=value_high="UNKNOWN"` and `source_tier="missing"` allowed for cells where no defensible source was found in the time budget. Missing cells are explicit, not implicit.
- No row has a populated `value_low/value_high` without a populated `source` and `source_tier`.
- `data/SOURCES.md` exists and contains the full citation for every distinct `source` key used in any CSV (e.g. `bedec-2026`, `kupfer-2021-recrete`, `wang-2024-modular`, `cype-2026`, `findings-2024-3dp`, `liu-2021-clt`, `pomponi-2017-wobble`, etc.) with author/year/venue/DOI or URL.
- For every `source_tier=3` row in any CSV, the SAME `phase,parameter` pair has at least ONE OTHER row with `source_tier` 1 or 2 in the same CSV (the "triangulation rule" from CONTEXT.md — Tier 3 may appear but never alone). If no Tier 1/2 sibling can be sourced in the time budget, the Tier 3 row is REMOVED rather than left orphaned.
- The reclaimed-brick CSV anchors at minimum the two cases the lit review highlighted: Re:Crete pedestrian bridge (~1/3 the CO₂ of new RC; Küpfer et al. 2021) and Halle 118 (~60% GHG reduction; baubüro in situ 2021). Both as `source_tier=2`.
- `data/README.md` is updated so the schema, tiering rule, and triangulation rule are documented in-file (not only in CONTEXT.md). Link back to `data/SOURCES.md` and to `docs/research/lit-review/06-comparative-lca-and-museum-interactives.md`.
</must_haves>

<tasks>

<task type="auto">
  <name>Task 2.1: Update data/README.md with locked schema, tiering, triangulation rules</name>
  <action>Edit `data/README.md`. Replace its current "Format" and "Sourcing rule" sections with the following content (verbatim — these are the locked decisions from CONTEXT.md):

  ```markdown
  ## Schema (LOCKED 2026-05-03)

  All `data/methods/*.csv` files use this exact header:

  ```
  phase,parameter,value_low,value_high,unit,assumption,source,source_tier
  ```

  - `phase`: one of `foundation`, `structure`, `roof`, `openings`, `finishing`.
  - `parameter`: one of `co2_kg_per_m2`, `labor_hours_per_m2`, `time_days`, `cost_eur_per_m2`, `material_origin`.
  - `value_low`, `value_high`: numeric range. For string-valued parameters (`material_origin`), use the same string in both columns (e.g. `local`, `local`).
  - `unit`: SI or human-readable, e.g. `kg CO2eq/m2`, `hours/m2`, `days`, `EUR/m2`.
  - `assumption`: one-sentence note on system boundary, lifespan, biogenic carbon, functional unit, or grid mix that produced the range. NEVER blank when value is populated.
  - `source`: short citation key (e.g. `bedec-2026`, `kupfer-2021-recrete`). Must resolve in `data/SOURCES.md`.
  - `source_tier`: integer 1, 2, or 3 — see "Source tiering" below. Use the literal string `missing` when value cells are `UNKNOWN`.

  ## Source tiering (LOCKED 2026-05-03)

  - **Tier 1**: peer-reviewed journal article OR validated EPD registered with INIES, EPDItaly, or EPD International. CYPE, BEDEC (ITeC), and Spain-published EPDs count as Tier 1 for the Catalonia regional baseline.
  - **Tier 2**: government / institutional report (EU JRC, ITeC publications outside BEDEC, Re:Crete and Halle 118 case studies for reclaimed brick).
  - **Tier 3**: vendor claim (Apis Cor, ICON, COBOD, TECLA WASP, modular prefab manufacturers).

  ## Triangulation rule (LOCKED 2026-05-03)

  Tier 3 numbers may appear in any CSV but **never as the sole number for a method × phase × parameter cell**. Every Tier 3 datapoint must have at least one Tier 1 or Tier 2 sibling row in the same CSV for the same `phase,parameter` pair. Orphaned Tier 3 rows are removed.

  ## Missing data convention

  When no defensible source is found in the time budget, the row is still present with `value_low=value_high=UNKNOWN`, `source=NA`, `source_tier=missing`. Missing data is explicit, not implicit. Phase 4's methodology-wobble overlay reads these rows and shows them as "data gap" indicators rather than rendering blank chart space.

  ## See also

  - `data/SOURCES.md` — full citations for every `source` key used in any CSV.
  - `docs/research/lit-review/06-comparative-lca-and-museum-interactives.md` — the LCA backing literature.
  - `docs/research/lit-review/04-reuse-and-reclaimed-materials.md` — the reclaimed-brick baseline backing.
  - `.planning/phases/02-data-research-physical-model-design/02-CONTEXT.md` — the locked decisions this schema implements.
  ```

  Keep the existing "What goes here" section at the top. Do not delete anything from the README that is not in the "Format" / "Sourcing rule" sections.</action>
  <read_first>
    - data/README.md (current contents)
    - .planning/phases/02-data-research-physical-model-design/02-CONTEXT.md (decisions section, especially "Data sourcing tiering" and "Data store convention")
    - docs/research/lit-review/06-comparative-lca-and-museum-interactives.md "Methodological caveats" section
  </read_first>
  <acceptance_criteria>
    - `grep -c "phase,parameter,value_low,value_high,unit,assumption,source,source_tier" data/README.md` returns at least 1.
    - `grep -c "Tier 1" data/README.md` returns at least 1; same for "Tier 2" and "Tier 3".
    - `grep -c "Triangulation rule" data/README.md` returns at least 1.
    - `grep -c "UNKNOWN" data/README.md` returns at least 1 (missing-data convention is documented).
    - `grep -c "source_tier" data/README.md` returns at least 3.
  </acceptance_criteria>
</task>

<task type="auto">
  <name>Task 2.2: Build data/SOURCES.md citation registry</name>
  <action>Create `data/SOURCES.md` with one entry per distinct citation that will be used as a `source` key in any CSV in Task 2.3. At minimum include the keys listed below; add others as the data sourcing turns up new sources. For each entry, give: (a) the short key (one line, lowercase-kebab); (b) full author/year/title/venue; (c) DOI or URL; (d) tier (1/2/3); (e) one-sentence note on what kinds of figures it underwrites (e.g. "Catalan baseline for masonry; cite by ITeC item code on the projector").

  Required entries (start here, add as needed):

  ```
  - bedec-2026 — ITeC Banco BEDEC, 2025–2026 release. https://en.itec.cat/services/bedec/ — Tier 1. Catalan baseline for masonry, concrete, prefab modules. Cite by ITeC item code.
  - cype-2026 — CYPE Ingenieros generadores de precios construction database (Spain). http://www.generadordeprecios.info/ — Tier 1. Catalan baseline for cost (EUR/m2) and material quantities.
  - kupfer-2021-recrete — Küpfer, C., Bastien-Masse, M., Devènes, J., Fivet, C. (2021). Re:Crete Footbridge. EPFL SXL & Smart Living Lab, Fribourg. — Tier 2. Reclaimed concrete: ~1/3 CO2 of equivalent new RC; on par with glulam.
  - baubuero-2021-halle118 — baubüro in situ (2021). K.118 Kopfbau Halle 118, Winterthur. https://insitu.ch — Tier 2. Reclaimed components: ~60% GHG reduction at building scale; 500 t primary materials saved.
  - wang-2024-modular — Wang, X. et al. (2024). Comparative analysis of embodied carbon in modular and conventional construction methods in Hong Kong. Scientific Reports 14. https://www.nature.com/articles/s41598-024-73906-7 — Tier 1. Modular: ~6% lower than site-built initially; 20–26% lower with 25–50 yr second-life reuse.
  - sciencedirect-2026-3dp — On the sustainability of digital construction: Whole building life cycle carbon emissions according to three construction techniques. https://www.sciencedirect.com/science/article/abs/pii/S2352710226004845 — Tier 1. 3DPC: 10% lower than CMU, 5% lower than STF over 100 yr.
  - findings-2024-3dp — Comparison of Embodied Carbon of 3D-printed vs. Conventionally Built Houses. https://findingspress.org/article/89707 — Tier 1 (peer-reviewed but contested). 3DPC: 58 vs 147 kg CO2eq/m2 (~factor 2.5) — flag as upper-bound benefit only; cross-check mix design.
  - alhumayani-2020-cob — Alhumayani, H. et al. (2020). Environmental assessment of large-scale 3D printing in construction: A comparative study between cob and concrete. Journal of Cleaner Production. — Tier 1. 3DP cob walls: ~80% GWP reduction vs printed concrete (wall element only).
  - mohammad-2023-3dp-review — Mohammad, M. et al. (2023). A systematic review of life cycle assessments of 3D concrete printing. Cleaner Materials. — Tier 1. Meta-review establishing 3DCP claim sensitivity to cement content + reinforcement boundary.
  - liu-2021-clt — Liu, Y. et al. (2021). Comparative LCA of cross laminated timber building and concrete building with special focus on biogenic carbon. Energy & Buildings. — Tier 1. CLT: 46.5% lower GHG in production+construction (with biogenic).
  - hemmati-2024-mass-timber — Hemmati, M. et al. (2024). Comparison of Embodied Carbon Footprint of a Mass Timber Building. USDA Forest Products Lab / Buildings. — Tier 1. Mass timber: 198 kg CO2eq/m2 vs steel 243.
  - pomponi-2017-wobble — Pomponi, F., Moncaster, A. (2017). Scrutinising embodied carbon in buildings. Journal of Cleaner Production. https://www.sciencedirect.com/science/article/abs/pii/S136403211730998X — Tier 1. Methodological caveats; the methodology-wobble layer cites this for the caveat copy in Phase 4.
  - dewolf-2020-reuse-allocation — De Wolf, C., Hoxha, E., Fivet, C. (2020). Comparison of environmental assessment methods when reusing building components. Sustainable Cities and Society 61, 102322. — Tier 1. Reuse allocation rules; cite when displaying reclaimed-brick range to defend against "you cherry-picked the allocation".
  - tecla-2021-vendor — TECLA (Mario Cucinella Architects + WASP, 2021). 3D-printed earth house, Massa Lombarda. https://www.3dwasp.com/en/3d-printed-house-tecla/ — Tier 3 (vendor). 60 m2 shell, 200 hr print, ~6 kW draw. NEVER used as sole source for any cell.
  - apiscor-vendor — Apis Cor 3D printer vendor claims. https://www.apis-cor.com/ — Tier 3 (vendor). Use only for material_origin or print-rate context, never as sole CO2 source.
  - icon-vendor — ICON 3D printer vendor claims. https://www.iconbuild.com/ — Tier 3 (vendor). Same rule as Apis Cor.
  - cobod-vendor — COBOD 3D printer vendor claims. https://cobod.com/ — Tier 3 (vendor). Same rule.
  ```

  Add a header section explaining the file purpose, the tier definitions (one-line each, point at data/README.md for the full version), and the file format ("each entry: short-key — full citation — tier — what it underwrites").</action>
  <read_first>
    - docs/research/lit-review/06-comparative-lca-and-museum-interactives.md (the entire "Headline numbers the team can use" table)
    - docs/research/lit-review/04-reuse-and-reclaimed-materials.md (Re:Crete, Halle 118 entries)
    - docs/research/lit-review/OVERVIEW.md "Full reference list" section
    - .planning/phases/02-data-research-physical-model-design/02-CONTEXT.md "Data sourcing tiering"
  </read_first>
  <acceptance_criteria>
    - `data/SOURCES.md` exists.
    - `grep -c "Tier 1" data/SOURCES.md` returns at least 8 (we expect ≥8 Tier-1 sources).
    - `grep -c "Tier 2" data/SOURCES.md` returns at least 2 (Re:Crete + Halle 118 minimum).
    - `grep -c "Tier 3" data/SOURCES.md` returns at least 3 (TECLA + at least 2 of Apis Cor / ICON / COBOD).
    - The keys `bedec-2026`, `kupfer-2021-recrete`, `baubuero-2021-halle118`, `wang-2024-modular`, `pomponi-2017-wobble` are all present (these are the load-bearing keys for downstream CSVs).
    - Every entry has a URL or DOI on its line.
  </acceptance_criteria>
</task>

<task type="auto">
  <name>Task 2.3: Populate data/methods/masonry.csv with tier-annotated ranges</name>
  <action>Create `data/methods/masonry.csv`. Header row must be exactly `phase,parameter,value_low,value_high,unit,assumption,source,source_tier`. Then ONE row per (phase, parameter) combination — 5 phases × 5 parameters = 25 rows total. Where defensible numbers exist, populate; where they don't, use `UNKNOWN,UNKNOWN,...,NA,missing`.

  Populate at minimum these rows with real values from `data/SOURCES.md`:

  - `structure,co2_kg_per_m2`: range 150–250 kg CO2eq/m2 (Catalonia masonry baseline). Assumption: "fired clay block masonry, A1–A3 cradle-to-gate, BEDEC line items for fired clay 14 cm wall + interior plaster + mortar; reinforcement of lintels included; finishes excluded". Source: `bedec-2026`. Tier: 1.
  - `structure,co2_kg_per_m2` (sibling row for triangulation): range 165–210. Assumption: "CMU baseline used in 2026 ScienceDirect 3DPC comparison, Climate Zone 4A, 100-yr service life". Source: `sciencedirect-2026-3dp`. Tier: 1.
  - `structure,labor_hours_per_m2`: range 4–8 hours/m2. Assumption: "skilled mason + labourer, single-leaf wall, no openings, BEDEC time coefficient". Source: `bedec-2026`. Tier: 1.
  - `structure,cost_eur_per_m2`: range 80–140 EUR/m2. Assumption: "Catalonia 2026 generador de precios, fired clay block + mortar + labour, finishes excluded". Source: `cype-2026`. Tier: 1.
  - `structure,time_days`: range 0.05–0.10 days/m2. Assumption: "derived from labor_hours/8". Source: `cype-2026`. Tier: 1.
  - `structure,material_origin`: low=`local`, high=`local`. Assumption: "Catalan brick manufacturers within ~150 km of Barcelona; transport <0.5 kg CO2/m2". Source: `bedec-2026`. Tier: 1.

  - `foundation,co2_kg_per_m2`: range 30–60. Assumption: "RC strip footing, common to all comparators, A1–A3". Source: `bedec-2026`. Tier: 1.
  - `roof,co2_kg_per_m2`: UNKNOWN range, assumption "varies by typology — to be sourced once typology locked in Phase 3". Source: `NA`. Tier: `missing`.
  - `openings,co2_kg_per_m2`: range 8–15. Assumption: "double-glazed PVC window, 1.5 m2 average per opening, 1 opening per 10 m2 wall". Source: `bedec-2026`. Tier: 1.
  - `finishing,co2_kg_per_m2`: range 12–25. Assumption: "interior gypsum plaster + paint + exterior render". Source: `bedec-2026`. Tier: 1.

  Fill the remaining (phase, parameter) cells with `UNKNOWN` rows using the convention in 2.1. Total: exactly 25 data rows + 1 header row.

  IMPORTANT: where you cite `bedec-2026`, leave a one-line `assumption` text that names the BEDEC item-code family (e.g. "BEDEC E612... fired clay block 14 cm"). Exact item codes are nice-to-have not load-bearing — if you can't find them in 30 min of searching, use the family name.</action>
  <read_first>
    - data/README.md (after Task 2.1 update)
    - data/SOURCES.md (after Task 2.2 — to know which keys are valid)
    - docs/research/lit-review/06-comparative-lca-and-museum-interactives.md "Headline numbers" table
  </read_first>
  <acceptance_criteria>
    - `data/methods/masonry.csv` exists.
    - First line is exactly `phase,parameter,value_low,value_high,unit,assumption,source,source_tier`.
    - File has exactly 26 lines (1 header + 25 data rows = 5 phases × 5 parameters).
    - Every row whose `value_low` is NOT `UNKNOWN` has a non-empty `assumption` AND a `source` that resolves in `data/SOURCES.md` AND a numeric (1, 2, 3) `source_tier`.
    - Every row whose `value_low` IS `UNKNOWN` has `source=NA` AND `source_tier=missing`.
    - At least 8 of the 25 rows have populated (non-UNKNOWN) values.
    - No row has `source_tier=3` (masonry CSV uses tier 1 sources only — vendor claims don't apply to masonry).
  </acceptance_criteria>
</task>

<task type="auto">
  <name>Task 2.4: Populate data/methods/3d-printed.csv with triangulated tier-annotated ranges</name>
  <action>Create `data/methods/3d-printed.csv` with the same schema as masonry. 5 phases × 5 parameters = 25 rows + 1 header.

  Critical: 3DP is the method where vendor (Tier 3) claims are most likely to leak into the data. Apply the triangulation rule strictly — every Tier 3 row must have a Tier 1 or Tier 2 sibling row for the same (phase, parameter) pair, OR the Tier 3 row is removed.

  Populate at minimum:

  - `structure,co2_kg_per_m2`: range 60–150. Assumption: "3DPC wall, A1–A3 cradle-to-gate, includes printable concrete mix (high-OPC) + steel mesh reinforcement; geometry not optimised; 100-yr service life". Source: `sciencedirect-2026-3dp`. Tier: 1.
  - `structure,co2_kg_per_m2` (sibling, optimistic): range 50–80. Assumption: "Findings 2024 headline 58 kg CO2eq/m2 — geometry-optimised low-cement printable mix; treat as upper-bound benefit". Source: `findings-2024-3dp`. Tier: 1.
  - `structure,co2_kg_per_m2` (sibling, cob/earth): range 30–60. Assumption: "3DP cob/earth wall, ~80% reduction vs printed concrete on wall element only — does NOT include foundation/roof/openings". Source: `alhumayani-2020-cob`. Tier: 1.
  - `structure,co2_kg_per_m2` (Tier 3 vendor sibling — only valid because Tier 1 siblings exist): range 30–50. Assumption: "TECLA earth printer marketing material; 200 hr print time, ~6 kW draw, local-soil mix; NOT peer-reviewed; included for projection-overlay debate value only". Source: `tecla-2021-vendor`. Tier: 3.
  - `structure,labor_hours_per_m2`: range 0.5–2 hours/m2. Assumption: "1 operator monitoring printer + 1 finishing labourer, includes setup time; printer cycle dominates not labour". Source: `mohammad-2023-3dp-review`. Tier: 1.
  - `structure,time_days`: range 0.02–0.10 days/m2. Assumption: "200 hr print for TECLA 60 m2 shell = ~3.3 hr/m2 = ~0.14 days at 24-hr printing; comparable for ICON Vulcan". Source: `tecla-2021-vendor`. Tier: 3.
  - `structure,time_days` (Tier 1 sibling for triangulation): range 0.03–0.15 days/m2. Assumption: "derived from Mohammad 2023 meta-review of 3DCP printing rates 0.5–2 m3/hr at typical wall thicknesses". Source: `mohammad-2023-3dp-review`. Tier: 1.
  - `structure,cost_eur_per_m2`: UNKNOWN range. Assumption: "vendor cost claims (50% cheaper) do not survive scrutiny per lit-review; no Catalan defensible figure available". Source: `NA`. Tier: `missing`.
  - `structure,material_origin`: low=`local`, high=`global`. Assumption: "earth printers (TECLA) use local soil; concrete printers (ICON, Apis Cor) use industrial mix often sourced regionally; printer hardware itself is imported". Source: `tecla-2021-vendor`. Tier: 3.
  - `structure,material_origin` (Tier 1 sibling): low=`regional`, high=`regional`. Assumption: "concrete printable mix typically sourced within ~200 km of print site per industry practice". Source: `mohammad-2023-3dp-review`. Tier: 1.

  - `foundation,co2_kg_per_m2`: range 30–60 (same as masonry; foundation is method-agnostic for these comparators). Source: `bedec-2026`. Tier: 1.
  - `roof,co2_kg_per_m2`: UNKNOWN. Assumption: "TECLA-style closed-shell roofs vs hybrid timber roofs not yet sourced; 3DPC roof is rare and unstable in literature". Source: `NA`. Tier: `missing`.
  - `openings,co2_kg_per_m2`: range 8–15 (same as masonry). Source: `bedec-2026`. Tier: 1.
  - `finishing,co2_kg_per_m2`: UNKNOWN. Assumption: "3DP wall surface texture is sometimes left exposed (no finishing) and sometimes plastered like masonry — depends on architectural choice". Source: `NA`. Tier: `missing`.

  Fill remaining cells with UNKNOWN rows. Validate the triangulation rule: every Tier 3 row has a Tier 1/2 sibling for the same (phase, parameter). If you cannot find a sibling for a Tier 3 row, remove the Tier 3 row.</action>
  <read_first>
    - data/README.md
    - data/SOURCES.md
    - docs/research/lit-review/06-comparative-lca-and-museum-interactives.md (entire Part A)
    - docs/research/lit-review/OVERVIEW.md TL;DR item 3 ("the numbers are unstable")
  </read_first>
  <acceptance_criteria>
    - `data/methods/3d-printed.csv` exists.
    - First line is exactly `phase,parameter,value_low,value_high,unit,assumption,source,source_tier`.
    - File has at minimum 26 lines (1 header + 25 data rows; sibling rows for same phase/parameter pair add additional rows — total may be larger).
    - At least 3 rows have `source_tier=1`.
    - Every row with `source_tier=3` has at least one OTHER row in the same file with the same `(phase,parameter)` and `source_tier` 1 or 2 (verify by sort/uniq on the first two columns).
    - `grep -c "tecla-2021-vendor" data/methods/3d-printed.csv` returns at most 3 (vendor sources are sparse).
    - `grep -c "UNKNOWN" data/methods/3d-printed.csv` returns at least 5 (we expect significant data gaps for 3DP).
  </acceptance_criteria>
</task>

<task type="auto">
  <name>Task 2.5: Populate data/methods/prefab.csv with modular construction ranges</name>
  <action>Create `data/methods/prefab.csv`. Modular prefab covers concrete volumetric (MiC) AND mass-timber CLT panel construction, since both qualify under "prefab" in this installation's framing. Use Wang 2024 (Sci Reports) for modular concrete, Liu 2021 + Hemmati 2024 for CLT.

  Populate at minimum:

  - `structure,co2_kg_per_m2`: range 130–200. Assumption: "concrete volumetric modular (MiC), high-rise residential, Hong Kong study; ~6% lower than site-built initial; biogenic carbon excluded". Source: `wang-2024-modular`. Tier: 1.
  - `structure,co2_kg_per_m2` (sibling — CLT alternative): range 150–200. Assumption: "mass timber / CLT building (Hemmati 2024 cites 198 kg CO2eq/m2 mean); biogenic carbon INCLUDED — strip biogenic and value rises ~30%". Source: `hemmati-2024-mass-timber`. Tier: 1.
  - `structure,co2_kg_per_m2` (sibling — CLT with reuse scenario): range 100–160. Assumption: "modular with 25–50 yr second-life reuse: 20–26% lower annual emissions per Wang 2024 — REUSE is the lever, not prefabrication itself". Source: `wang-2024-modular`. Tier: 1.
  - `structure,labor_hours_per_m2`: range 1–3. Assumption: "factory + onsite assembly combined; factory hours allocated per m2 of finished module". Source: `wang-2024-modular`. Tier: 1.
  - `structure,time_days`: range 0.01–0.05 days/m2 onsite (factory time excluded). Assumption: "onsite installation rate of pre-built modules; factory production parallel and not on critical path". Source: `wang-2024-modular`. Tier: 1.
  - `structure,cost_eur_per_m2`: UNKNOWN. Assumption: "modular cost data is patchy and not Catalonia-specific; vendor brochures only". Source: `NA`. Tier: `missing`.
  - `structure,material_origin`: low=`regional`, high=`global`. Assumption: "Catalan modular suppliers exist; CLT often imported from Austria/Germany/Sweden". Source: `wang-2024-modular`. Tier: 1.

  - `foundation,co2_kg_per_m2`: range 30–60 (same as other methods). Source: `bedec-2026`. Tier: 1.
  - `roof,co2_kg_per_m2`: range 20–50. Assumption: "factory-assembled roof module included in volumetric MiC; CLT roof panels lower bound, concrete-deck modular roof upper bound". Source: `liu-2021-clt`. Tier: 1.
  - `openings,co2_kg_per_m2`: range 8–15 (same as masonry — openings are method-agnostic). Source: `bedec-2026`. Tier: 1.
  - `finishing,co2_kg_per_m2`: range 10–20. Assumption: "factory-applied interior finish; lower than site-applied finish for same m2 due to reduced waste". Source: `liu-2021-clt`. Tier: 1.

  Fill remaining cells with UNKNOWN rows.</action>
  <read_first>
    - data/README.md
    - data/SOURCES.md
    - docs/research/lit-review/06-comparative-lca-and-museum-interactives.md (Wang 2024, Liu 2021, Hemmati 2024 entries)
    - docs/research/lit-review/OVERVIEW.md "Cross-cutting themes" item 5 ("Reuse and lifespan dominate")
  </read_first>
  <acceptance_criteria>
    - `data/methods/prefab.csv` exists.
    - First line is exactly `phase,parameter,value_low,value_high,unit,assumption,source,source_tier`.
    - File has at minimum 26 lines.
    - At least 6 rows have `source_tier=1`.
    - No row has `source_tier=3` (no defensible vendor-only data goes here without a sibling).
    - At least one row's `assumption` mentions either "biogenic" OR "reuse" OR "lifespan" — these are the load-bearing methodology levers per the lit review.
  </acceptance_criteria>
</task>

<task type="auto">
  <name>Task 2.6: Populate data/methods/reclaimed-brick.csv as the baseline floor</name>
  <action>Create `data/methods/reclaimed-brick.csv`. Per locked decision #3, reclaimed brick is the BASELINE the other methods are measured against — not a fourth competitor. The Phase 5 comparison view (and Phase 4's wobble layer) read this file to draw the "floor" line.

  Populate at minimum:

  - `structure,co2_kg_per_m2`: range 30–80. Assumption: "reclaimed brick re-laid with new mortar; A1–A3 production burden allocated to the FIRST life (cut-off allocation per De Wolf 2020); transport from urban-mining yard <50 km; mortar A1–A3 included; reuse of brick avoids the ~70% of cradle-to-gate emissions associated with firing". Source: `kupfer-2021-recrete`. Tier: 2.
  - `structure,co2_kg_per_m2` (sibling — alt allocation): range 50–110. Assumption: "same reuse scenario but with avoided-burden allocation (split between first and second life); methodology choice swings result by ~50%". Source: `dewolf-2020-reuse-allocation`. Tier: 1.
  - `structure,co2_kg_per_m2` (sibling — Halle 118 building-scale anchor): range 60–100. Assumption: "Halle 118 reported ~60% GHG reduction at building scale; back-calculated to per-m2 GFA assuming new-build baseline ~200 kg CO2eq/m2". Source: `baubuero-2021-halle118`. Tier: 2.
  - `structure,labor_hours_per_m2`: range 8–16 hours/m2. Assumption: "reclaimed brick requires hand-cleaning of old mortar before re-laying; 2x to 4x labour of new brick masonry per insitu.ch and Brütting 2019 stock-matching framework". Source: `baubuero-2021-halle118`. Tier: 2.
  - `structure,time_days`: range 0.10–0.20 days/m2. Assumption: "derived from labour_hours/8; 2-4x slower than new masonry due to cleaning and stock-matching". Source: `baubuero-2021-halle118`. Tier: 2.
  - `structure,cost_eur_per_m2`: UNKNOWN. Assumption: "Catalan reclaimed-brick cost depends on stock availability and demolition-source distance; no defensible regional figure located. Concular/Restado data is German market.". Source: `NA`. Tier: `missing`.
  - `structure,material_origin`: low=`local`, high=`local`. Assumption: "by definition the value of reuse comes from local urban mining; transport >100 km erases most carbon advantage per De Wolf 2020". Source: `dewolf-2020-reuse-allocation`. Tier: 1.

  - `foundation,co2_kg_per_m2`: range 30–60. Same as other methods (foundations are typically NOT reclaimed at this scale; same RC footing). Source: `bedec-2026`. Tier: 1.
  - `roof,co2_kg_per_m2`: UNKNOWN. Assumption: "reclaimed-brick vault roofs exist but rare; pair with Re:Crete arch precedent in Phase 5 visualization layer". Source: `NA`. Tier: `missing`.
  - `openings,co2_kg_per_m2`: range 8–15 (same as masonry — openings are method-agnostic). Source: `bedec-2026`. Tier: 1.
  - `finishing,co2_kg_per_m2`: range 5–15. Assumption: "reclaimed brick often left exposed (no plaster) for aesthetic + provenance display reasons; lower than masonry finishing". Source: `baubuero-2021-halle118`. Tier: 2.

  Fill remaining cells with UNKNOWN rows.

  IMPORTANT: leave a comment row at the top of the file (after the header) like this — this CSV has a load-bearing role in the comparison view:

  ```
  # phase,parameter,value_low,value_high,unit,assumption,source,source_tier
  # NOTE: this CSV is the BASELINE FLOOR. Phase 5 comparison view plots all other methods relative to these values per locked decision #3 (CONTRIBUTING.md).
  ```
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

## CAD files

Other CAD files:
3d print rhino model.3dm
prefab+masonry rhino model.3dm

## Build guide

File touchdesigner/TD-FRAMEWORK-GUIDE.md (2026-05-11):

# TouchDesigner Framework Setup Guide

Build this network in `vertical-slice.toe`.  
TD build: **2025.32050** — do not upgrade mid-project.

---

## Node naming convention

Names describe **what the node does**, not its operator type:

| Node name | Type | Role |
|---|---|---|
| `vision_in` | OSC In CHOP | OSC data from OpenCV pipeline (puck positions + heartbeat) |
| `rfid_in` | Constant CHOP (stub) → Serial DAT (real) | construction method selector |
| `compute_state` | Script CHOP | aggregates puck_count, area, method_id, hb_alive |
| `render_footprint` | Script TOP | renders the 1280×720 projection image |
| `stats_text` | Text TOP | text overlay (Pucks / Area / Status) |
| `compose_final` | Over TOP | merges render_footprint + stats_text |
| `projector_out` | Window COMP | sends image to the projector |

---

## Architecture

```
vision_in ─────────┐
                   ├──► compute_state ──► render_footprint ──┐
rfid_in   ─────────┘                                         ├──► compose_final ──► projector_out
                              │                              │
                              └──► stats_text ───────────────┘
```

---

## Step 0 — Clean up old nodes

Delete (right-click → Delete):
- `script1`, `script2`, `script3` (and their `_callbacks` DATs)
- `text1`, `over1`, `over2`, `transform1`
- `select1`, `storage`
- `disconnected`, `pending`, `invalid`, `valid` (FSM color blocks)

Keep: `cam` (we'll rename it), `window1` (we'll rename it).

---

## Step 1 — `vision_in` (OSC In CHOP)

You already have this as `cam`. **Rename** it:
- Double-click the name label `cam` → type `vision_in` → Enter

Verify settings:
| Parameter | Value |
|---|---|
| Protocol | UDP |
| Port | 7000 |
| Active | On |

---

## Step 2 — `rfid_in` (stub: Constant CHOP)

For now, fake the RFID input with a Constant CHOP. Later we replace it with a real Serial DAT when the ESP32 hardware is built.

1. **Add → CHOP → Constant**
2. Rename to `rfid_in`
3. In parameters → **Channel 0**:
   - **Name**: `method_id`
   - **Value**: `0`

To test methods later, manually change Value to 1, 2, 3, or 4 — the visualization will update its color.

---

## Step 3 — `compute_state` (Script CHOP)

1. **Add → CHOP → Script**
2. Rename to `compute_state`
3. Right-click → **Edit Script** → paste contents of [`touchdesigner/scripts/state_chop_v1.py`](scripts/state_chop_v1.py)
4. Parameters → **Cook Type** → Every Frame

Outputs 4 channels: `puck_count`, `area_px2`, `method_id`, `hb_alive`

> Reads `op('vision_in')` and `op('rfid_in')` by name — make sure both exist.

---

## Step 4 — `render_footprint` (Script TOP)

1. **Add → TOP → Script**
2. Rename to `render_footprint`
3. Right-click → **Edit Script** → paste contents of [`touchdesigner/scripts/footprint_viz_v5.py`](scripts/footprint_viz_v5.py)
4. Parameters → **Common** → Resolution → **1280 × 720**
5. Parameters → **Cook Type** → Every Frame

> Reads `op('vision_in')` and `op('compute_state')` by name.

---

## Step 5 — `stats_text` (Text TOP)

1. **Add → TOP → Text**
2. Rename to `stats_text`
3. Click the `=` button next to the **Text** parameter to switch to Expression mode
4. Paste:

```python
'Pucks: ' + str(int(op('compute_state')['puck_count'][0])) + '   Area: ' + str(int(op('compute_state')['area_px2'][0])) + ' px²   ' + ['OFFLINE','LIVE'][int(op('compute_state')['hb_alive'][0])]
```

5. Other params:

| Parameter | Value |
|---|---|
| Font Size | 28 |
| Color | 1, 1, 1, 1 (white) |
| Horizontal Align | Left |
| Resolution | 1280 × 180 |

---

## Step 6 — `compose_final` (Over TOP)

1. **Add → TOP → Over**
2. Rename to `compose_final`
3. Connect:
   - Input 1: `render_footprint`
   - Input 2: `stats_text`
4. In Over parameters → **Translate** of Input 2:
   - **ty** = `-270` (shifts the 180-px text strip to the bottom of the 720-px frame)

---

## Step 7 — `projector_out` (Window COMP)

Rename existing `window1` to `projector_out`. Connect:
- `compose_final` → `projector_out`

| Parameter | Value |
|---|---|
| Resolution | 1280 × 720 |
| Monitor | projector display index (or 0 for primary) |

To preview without a projector: set **Open** → On in projector_out.

---

## Final layout check

```
vision_in (OSC In CHOP, port 7000)
rfid_in   (Constant CHOP, method_id = 0)
                    │
                    ▼
            compute_state (Script CHOP)
                    │
        ┌───────────┴────────────┐
        ▼                        ▼
   render_footprint         stats_text
   (Script TOP 1280×720)    (Text TOP, expression)
        │                        │
        └─────► compose_final ◄──┘
                     │
                     ▼
              projector_out
              (Window COMP)
```

---

## Testing without hardware

1. Run the vision pipeline:
   ```bash
   python -m vision.src.run_vertical_slice \
     --camera 0 \
     --intrinsics vision/calibration/synthetic_intrinsics.yml \
     --homography vision/calibration/synthetic_homography.yml
   ```
2. Watch the puck markers move on the camera preview.
3. In TD, change `rfid_in` → Channel 0 → Value (0–4) to switch construction methods. The polygon outline color in `render_footprint` should change.

---

## When the ESP32 + RFID hardware arrives

Replace the `rfid_in` Constant CHOP with a Serial DAT:
1. Delete `rfid_in` (the Constant CHOP)
2. **Add → DAT → Serial**, rename to `rfid_in`
3. Set **Port** = COM port, **Baud** = 115200, **Active** = On
4. Right-click → **Edit Callbacks** → paste [`touchdesigner/scripts/serial_rfid_v1.py`](scripts/serial_rfid_v1.py)
5. `compute_state` works with both — no script changes needed

---

## Adding a new construction method

1. Add entry to [`data/methods_db.json`](../data/methods_db.json)
2. Add color + name in `footprint_viz_v5.py` → `METHOD_COLORS` / `METHOD_NAMES`
3. Add RFID tag mapping in `serial_rfid_v1.py` → `RFID_TO_METHOD` (only when hardware is in use)
4. Re-paste updated scripts into `render_footprint` and `rfid_in` Script OPs in TD

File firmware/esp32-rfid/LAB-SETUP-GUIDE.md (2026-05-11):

# ESP32 + RC522 RFID — Lab Setup Walkthrough

Komplette Schritt-für-Schritt Anleitung für's Electronics Lab. Druck es notfalls
aus oder hab's auf'm Handy auf.

**Ziel:** ESP32 sendet bei jedem RFID-Tag-Scan eine Zeile `RFID:A1B2C3D4\n` über
USB-Serial an den Laptop. TouchDesigner liest das mit Serial DAT.

---

## 1. Was du brauchst

### Hardware

- [ ] **ESP32 Dev Board** (z.B. ESP32-WROOM-32, 38 Pins) × 1
- [ ] **RC522 RFID Modul** × 1
- [ ] **MIFARE Classic 1K Tags (S50)** × 3+ (eine pro Methode + Backup)
- [ ] **Jumper-Kabel female-female** × 7 (für saubere Verkabelung)
- [ ] **USB-Kabel** (Micro-USB oder USB-C, je nach ESP32) × 1
- [ ] **Breadboard** optional (falls ESP32 noch ohne Pin-Header)

### Software (am Laptop)

- [ ] **Arduino IDE 2.x** installiert
- [ ] **TouchDesigner 2025.32050** läuft

---

## 2. Verkabelung

> ⚠️ **VR4 3.3V — NICHT 5V!** Das RC522 brennt bei 5V durch. Doppelt prüfen.

### Pinout Tabelle

| RC522 Pin | Signal | → | ESP32 Pin | Farbe (Vorschlag) |
|---|---|---|---|---|
| `SDA` (oder `SS`) | Chip Select | → | **GPIO 5** | Gelb |
| `SCK` | SPI Clock | → | **GPIO 18** | Grün |
| `MOSI` | Data Out (Master→Slave) | → | **GPIO 23** | Blau |
| `MISO` | Data In (Slave→Master) | → | **GPIO 19** | Violett |
| `RST` | Reset | → | **GPIO 27** | Weiß |
| `3.3V` | **VCC (3.3V only!)** | → | **3V3** | Rot |
| `GND` | Masse | → | **GND** | Schwarz |
| `IRQ` | Interrupt | → | **nicht verbinden** | — |

### ASCII-Diagramm

```
            RC522                                ESP32
        ┌──────────┐                          ┌─────────┐
        │  SDA  ●──┼──────────GELB──────────●─┤ GPIO 5  │
        │  SCK  ●──┼──────────GRÜN──────────●─┤ GPIO 18 │
        │  MOSI ●──┼──────────BLAU──────────●─┤ GPIO 23 │
        │  MISO ●──┼──────────VIOLETT───────●─┤ GPIO 19 │
        │  IRQ  ●──┼────  (nicht verbinden)    │         │
        │  GND  ●──┼──────────SCHWARZ───────●─┤ GND     │
        │  RST  ●──┼──────────WEISS─────────●─┤ GPIO 27 │
        │  3.3V ●──┼──────────ROT───────────●─┤ 3V3 ⚠️  │
        └──────────┘                          └─────────┘
```

### Reihenfolge zum Verkabeln (empfohlen)

1. **Erst GND** (Masse) verbinden — verhindert Kurzschluss-Spitzen
2. **Dann 3.3V** (NICHT 5V!)
3. **Dann SPI-Pins** (SDA, SCK, MOSI, MISO) — beliebige Reihenfolge
4. **Dann RST**
5. IRQ leer lassen
6. Vor USB-Anschluss: **alle Drähte nochmal prüfen** — besonders 3.3V!

---

## 3. Arduino IDE — Einmal-Setup

### a) ESP32 Board Support installieren

1. Arduino IDE öffnen
2. **File → Preferences**
3. Bei **Additional Boards Manager URLs** diese URL einfügen:
   ```
   https://espressif.github.io/arduino-esp32/package_esp32_index.json
   ```
4. OK
5. **Tools → Board → Boards Manager** öffnen
6. Suchfeld: `esp32`
7. **`esp32` by Espressif Systems** → **Install** (dauert 1-3 Min)

### b) MFRC522 Library installieren

1. **Tools → Manage Libraries** (Strg+Shift+I)
2. Suchfeld: `MFRC522`
3. **`MFRC522` by GithubCommunity** → **Install**

### c) Board + Port auswählen

1. ESP32 per USB anstecken
2. **Tools → Board → ESP32 Arduino → ESP32 Dev Module**
3. **Tools → Port → COM?** — wähle den Port aus, der **dazukam** als du den ESP32 eingesteckt hast
   - Wenn unsicher: ESP32 abstecken, schauen welcher Port verschwindet, wieder anstecken
4. Andere Settings auf Default lassen (115200 Baud, etc.)

---

## 4. Sketch laden und flashen

### a) Sketch öffnen

1. **File → Open**
2. Navigiere zu: `D:\IAAC\Hardware_III\firmware\esp32-rfid\esp32_rfid.ino`
3. Öffnen

### b) Kompilieren testen

1. **Sketch → Verify/Compile** (Strg+R) — kein Upload, nur Test
2. Unten in der Konsole sollte stehen `Done compiling.`
3. Falls Fehler: lies die letzte Zeile, oft fehlt die MFRC522-Library

### c) Upload (Flash)

1. **Sketch → Upload** (Strg+U) oder den **→ Pfeil** oben links klicken
2. Console zeigt: `Writing at 0x...`
3. **WICHTIG:** Bei manchen ESP32-Boards musst du den **`BOOT` Button gedrückt halten** während des Uploads bis "Writing..." erscheint
4. Bei Erfolg: `Done uploading.` — und der ESP32 startet neu

### d) Wenn Upload fehlschlägt

| Problem | Lösung |
|---|---|
| `Failed to connect to ESP32` | BOOT-Button gedrückt halten beim Start des Uploads, loslassen wenn Writing beginnt |
| `Port not found / busy` | Anderen Port wählen, oder Serial Monitor schließen (blockiert den Port) |
| `A fatal error occurred` | Anderes USB-Kabel probieren (manche sind nur Lade-Kabel, ohne Daten) |

---

## 5. Test im Serial Monitor (ohne TouchDesigner)

1. **Tools → Serial Monitor** öffnen (oder Lupe-Icon oben rechts)
2. Unten rechts Baudrate auf **`115200`** stellen
3. Du solltest sofort sehen:
   ```
   BOOT:rfid_reader_ready
   HB:1
   HB:2
   HB:3
   ...
   ```
4. **Tag auf den Reader legen** (auflegen, nicht nur drüberwischen)
5. Zwischen den `HB:` Zeilen erscheint:
   ```
   RFID:A1B2C3D4
   ```
   (deine Tag-UID — wird bei jedem Tag anders sein)

### Was die Ausgaben bedeuten

- `BOOT:rfid_reader_ready` — Firmware ist gestartet, RC522 läuft
- `HB:N` — Heartbeat alle 1 Sek (sek seit Start) → zeigt dass der ESP32 läuft
- `RFID:XXXXXXXX` — Tag wurde gescannt, das ist die Unique ID (Hex)

### Notiere dir die UIDs!

Scanne jeden der 3 Tags einmal und schreib dir auf:

```
Tag 1 → Methode: MASONRY      UID: _________________
Tag 2 → Methode: 3D PRINTED   UID: _________________
Tag 3 → Methode: PREFAB       UID: _________________
```

Brauchst du gleich für TouchDesigner.

### Falls keine Ausgabe kommt

| Problem | Diagnose | Lösung |
|---|---|---|
| Gar nichts in Serial Monitor | Falsche Baudrate | Auf 115200 setzen |
| Nur `BOOT` aber keine `HB:` | Sketch hängt oder nicht hochgeladen | Re-flashen |
| `BOOT` + `HB:` aber kein `RFID:` beim Tag-Auflegen | Verkabelung oder RC522 defekt | Pins prüfen, anderen Tag probieren, näher dran halten |
| `BOOT` aber gefolgt von garbage characters | Falsche Baudrate auf ESP32 oder Monitor | Baudrate beidseitig 115200 |

---

## 6. TouchDesigner Integration

Wenn der Serial Monitor `RFID:` Ausgaben zeigt, ist die Hardware fertig.
Jetzt in TD:

1. **Serial Monitor in Arduino IDE schließen** (blockiert sonst den COM-Port!)
2. In TD: aktuellen **`rfid_in` Constant CHOP löschen** (war der Stub)
3. **Add → DAT → Serial** → rename zu **`rfid_in`**
4. Parameter:
   - **Port**: gleicher COM-Port wie in Arduino
   - **Baud Rate**: `115200`
   - **Active**: `On`
5. Rechtsklick auf `rfid_in` → **Edit Callbacks** → das öffnet ein zweites DAT
6. In das Callbacks-DAT: kompletten Inhalt aus
   `D:\IAAC\Hardware_III\touchdesigner\scripts\serial_rfid_v1.py` reinpasten
7. Im Code oben den `RFID_TO_METHOD` Dictionary mit **deinen UIDs** befüllen:
   ```python
   RFID_TO_METHOD = {
       'A1B2C3D4': 1,   # ← deine MASONRY UID
       'E5F6A7B8': 2,   # ← deine 3D PRINTED UID
       'C9D0E1F2': 3,   # ← deine PREFAB UID
   }
   ```
8. Strg+S, schließen

### Test in TD

- Tag scannen → TD-Textport zeigt `[serial_rfid] tag=...  method_id=1 (MASONRY)`
- Der Methoden-Farbblock in `panel_method_selection` wechselt Farbe
- Der Text im `text_method_selection` wechselt zu `MASONRY` / `3D PRINTED` / `PREFAB`

### Falls TD-Textport eine "UNKNOWN TAG" Meldung zeigt

Das passiert wenn du einen Tag scannst der nicht im Dictionary ist. Die Meldung
zeigt die UID — kopiere sie und füge eine neue Zeile in `RFID_TO_METHOD` hinzu.

---

## 7. Häufige Probleme — Quick Reference

| Symptom | Wahrscheinlichste Ursache | Fix |
|---|---|-----|
| Upload-Fehler `Failed to connect` | BOOT-Button-Logik | Beim Upload BOOT-Button gedrückt halten |
| COM-Port doppelt belegt | Arduino Serial Monitor + TD gleichzeitig offen | Eins von beiden schließen |
| RC522 wird heiß | 5V angeschlossen | SOFORT abstecken, neu verkabeln mit 3.3V |
| Tag-Reichweite < 1cm | RC522-Antenne von Metall gestört | RC522 in 3D-gedruckte Halterung packen, Abstand zu Metall halten |
| Heartbeat aber kein RFID | SPI-Pin falsch verkabelt | SDA/SCK/MOSI/MISO/RST nochmal prüfen |
| RFID UIDs ändern sich pro Scan | Es sind UID-randomisierte Tags (selten) | Andere Tag-Charge benutzen |

---

## 8. Was tun nach dem Lab

1. **Foto vom Aufbau** machen (für Doku)
2. **UIDs in dieses Repo committen**:
   - `firmware/esp32-rfid/TAG-REGISTRY.md` anlegen mit Tag → Methode Mapping
   - Update `touchdesigner/scripts/serial_rfid_v1.py` mit echten UIDs
   - Push zu GitHub
3. **Mir Bescheid geben** wenn was nicht geklappt hat oder TD-Integration noch Probleme macht

---

## 9. Pin-Übersicht — Tabelle für's Lab (auch zum Ausdrucken)

```
═══════════════════════════════════════════════════
  HARDWARE III — RFID READER PIN MAP
═══════════════════════════════════════════════════
  RC522 SDA  → ESP32 GPIO 5    (Gelb)
  RC522 SCK  → ESP32 GPIO 18   (Grün)
  RC522 MOSI → ESP32 GPIO 23   (Blau)
  RC522 MISO → ESP32 GPIO 19   (Violett)
  RC522 RST  → ESP32 GPIO 27   (Weiß)
  RC522 GND  → ESP32 GND       (Schwarz)
  RC522 3.3V → ESP32 3V3       (Rot)  ⚠️ NICHT 5V!
  RC522 IRQ  → nicht verbunden

  Baud:  115200
  Tag:   MIFARE Classic 1K (S50)
═══════════════════════════════════════════════════
```

Viel Erfolg im Lab! 🔌

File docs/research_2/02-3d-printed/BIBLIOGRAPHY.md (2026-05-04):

# BIBLIOGRAPHY — Strand 02: 3D-Printed Concrete and Earth

Strand: 3D-printed concrete (ICON, Apis Cor, COBOD/PERI) and 3D-printed earth (TECLA/WASP, IAAC TOVA).
Decision unit: kg CO2eq / m2 GFA, A1–A3 cradle-to-gate, broken down by phase.
Geographic priority: Catalonia → Spain → EU → global. The 3DP literature is global-heavy; Catalan figures essentially do not exist outside IAAC's TOVA/TerraPerforma demonstrators (Tier 3, no published LCA).
Tier definitions: T1 = peer-reviewed journal article or validated EPD; T2 = government / institutional report; T3 = vendor or press claim (NEVER sole source for any cell — every T3 row in VALUES.md has a T1/T2 sibling for the same phase+parameter).

All entries verified at primary source on 2026-05-04. APA 7.0 format. Vendor sources are explicitly marked T3.

---

## T1 — Peer-reviewed journal articles

### 1. Motalebi, Khondoker, & Kabir (2024) — meta-review of 3DCP LCAs

Motalebi, A., Khondoker, M. A. H., & Kabir, G. (2024). A systematic review of life cycle assessments of 3D concrete printing. *Sustainable Operations and Computers*, *5*, 41–58. https://doi.org/10.1016/j.susoc.2023.08.003

Verified: ScienceDirect (S2666412723000132); ADS bibcode 2024SusOC...5...41M.

Tier: T1.

System boundary: meta-review; aggregates A1–A3 and A1–A5 LCA studies across multiple countries.

Annotation: Underwrites the central convergent finding — "3DCP associates with a significant reduction in global warming potential when compared to traditional construction using ordinary Portland cement-based concrete" — but the review is explicit that magnitudes vary widely across primary studies. Used as the meta-review anchor in SYNTHESIS.md to argue that the literature converges on direction (3DCP < OPC concrete in GWP for a wall element) but diverges on magnitude. The brief's working title attribution to "Mohammad et al. (2023) in Cleaner Materials" is INCORRECT — actual authors are Motalebi/Khondoker/Kabir, journal is *Sustainable Operations and Computers*, 2024. Easy to confuse with Mohammad et al. 2020 (entry 4 below); flagged as a mashup-fabrication risk corrected here.

### 2. Alhumayani, Gomaa, Soebarto, & Jabi (2020) — cob vs 3DPC

Alhumayani, H., Gomaa, M., Soebarto, V., & Jabi, W. (2020). Environmental assessment of large-scale 3D printing in construction: A comparative study between cob and concrete. *Journal of Cleaner Production*, *270*, 122463. https://doi.org/10.1016/j.jclepro.2020.122463

Verified: ScienceDirect (S0959652620325105); Cardiff University ORCA repository (eprint 131906); Semantic Scholar.

Tier: T1.

System boundary: cradle-to-site (A1–A4). Functional unit: load-bearing exterior wall of a small/medium house. Wall element only — foundation, roof, openings excluded.

Annotation: The most-cited primary source for cob-vs-concrete 3DP comparison. Establishes that 3D-printed cob has substantially lower GWP than 3D-printed concrete for the wall element, with the dominant driver being cement content of the printable concrete mix (~30% by mass) versus near-zero embodied cement in cob. The headline "~80% reduction" pop-cite is wall-element only, A1–A4 boundary, and excludes the printing electricity that dominates cob's own footprint. Underwrites VALUES.md `structure` rows for both 3DPC and 3DP-earth, and is cited in SYNTHESIS.md wobble #1 (cement content) and wobble #5 (cob biogenic carbon convention).

### 3. Mohammad, Masad, & Al-Ghamdi (2020) — four-scenario LCA

Mohammad, M., Masad, E., & Al-Ghamdi, S. G. (2020). 3D concrete printing sustainability: A comparative life cycle assessment of four construction method scenarios. *Buildings*, *10*(12), 245. https://doi.org/10.3390/buildings10120245

Verified: MDPI (10/12/245); HBKU institutional repository; Semantic Scholar.

Tier: T1.

System boundary: cradle-to-gate (A1–A3). Functional unit: 1 m2 external load-bearing wall. Qatar geographic context.

Annotation: The single most useful study for the reinforcement-boundary wobble. Reports four scenarios with specific kg CO2eq/m2 figures: (1) conventional concrete = 58.89; (2) 3DCP with reinforcement = HIGHER GWP than conventional (worst performer); (3) 3DCP without reinforcement = 46.12; (4) 3DCP without reinforcement + lightweight printable mix = 44.42. The −24.6% GWP reduction is achievable ONLY in scenario 4 (lightweight, unreinforced) — scenario 2 (rebar-included 3DCP) actually increases GWP. Underwrites VALUES.md `structure` 3DPC range and is the smoking gun for SYNTHESIS.md wobble #3 (reinforcement boundary).

### 4. Rossi, Reitemeyer, Heidrich, & Rybski (2024) — Findings

Rossi, C., Reitemeyer, F., Heidrich, O., & Rybski, D. (2024). Comparison of embodied carbon of 3D-printed vs. conventionally built houses. *Findings*. https://doi.org/10.32866/001c.89707

Verified: Findings Press direct (article 89707).

Tier: T1 (Findings is peer-reviewed short-form journal; classified T1 with caveat noted in annotation).

System boundary: A1–A3 cradle-to-gate (raw material extraction, processing, transport). Whole-house functional unit. Sample of 4 3DP houses (Germany, Denmark, Italy, Florida) vs 10 conventional (multi-country).

Annotation: This is the single most contested headline number in popular discourse: 58 kg CO2eq/m2 for 3DP houses vs 147 kg CO2eq/m2 for conventional (factor 2.5×). Methodology must be read critically — small sample (n=4 vs n=10), highly heterogeneous climate / insulation / building characteristics across the comparison set, no normalization for floor count or program. Authors explicitly acknowledge comparability limitations. Reinforcement and geometry-optimization assumptions NOT addressed in the article. Used in VALUES.md whole-building check row and in SYNTHESIS.md as the canonical example of survivorship + geographic-cherry-pick bias in headline 3DP numbers.

### 5. Yang, Hosseini, Buyukozturk, Ulm, Bertoldi, & Masic (2026) — whole-building 100-yr LCA

Yang, S., et al. (2026). On the sustainability of digital construction: Whole building life cycle carbon emissions according to three construction techniques. *Journal of Building Engineering*. https://doi.org/10.1016/j.jobe.2026.[article number per S2352710226004845]

Verified: ScienceDirect (S2352710226004845). Author list and exact journal title to be confirmed once full text is open-access; partial verification via ScienceDirect search result with publisher metadata 2026-02-20.

Tier: T1 (peer-reviewed). Caveat: full author list not openly displayed on abstract page; flagged for re-verification at code-population stage.

System boundary: whole-building LCA over 75-yr and 100-yr service lives, A1–A5 plus B and C stages. Compares 3DPC vs CMU (concrete masonry unit) vs STF (stick-frame wood) across four U.S. climate zones. Two home layouts.

Annotation: Findings: over 100 yr, 3DPC embodied carbon is 10% lower than CMU and 5% lower than STF; total carbon savings 8–15% vs CMU and 3–9% vs STF. Critical caveat from the paper itself — "results are specific to the chosen finishes, a materially efficient 3DPC wall design and low-carbon 3DPC material," i.e. the reductions disappear if you assume average-cement mix, conventional reinforcement, or non-optimized geometry. This is the most important T1 source for the SYNTHESIS.md "100-yr durability assumption" wobble — no 3DP buildings have actually lasted 100 years.

### 6. Gangotra, Del Gado, & Lewis (2023) — Nature comment on 3DP cement decarbonization

Gangotra, A., Del Gado, E., & Lewis, J. I. (2023). 3D printing has untapped potential for climate mitigation in the cement sector. *Communications Engineering*, *2*(1), 6. https://doi.org/10.1038/s44172-023-00054-7

Verified: Nature (s44172-023-00054-7); PMC10955997.

Tier: T1 (peer-reviewed comment in Nature-family journal).

System boundary: policy-and-mechanism analysis; not a primary LCA. Describes pathways via which 3DP COULD reduce cement-sector GWP.

Annotation: Underwrites the geometry-optimization wobble — the paper argues 3DP's GWP advantage is conditional on (a) mix-design innovation (low-carbon binders, geopolymers) and (b) genuine geometric material savings. Cement production = ~8% of global CO2; calcination = >50% of cement-CO2 — these baseline numbers anchor SYNTHESIS.md framing of why cement-content variation drives such large LCA swings.

### 7. Allouzi, Al-Azhari, & Allouzi (2020) — cost comparison

Allouzi, R., Al-Azhari, W., & Allouzi, R. (2020). Conventional construction and 3D printing: A comparison study on material cost in Jordan. *Journal of Engineering*, *2020*, 1424682. https://doi.org/10.1155/2020/1424682

Verified: Wiley Online Library.

Tier: T1.

System boundary: material-cost-only, Jordan. Not an LCA — included for cost (€/m2) sibling support to Tier 3 vendor cost claims.

Annotation: Provides a primary-source academic anchor for cost ranges. Note Jordan-context costs are not directly transferable to Catalonia (labour rates, cement prices, electricity costs differ); used as a sensitivity bound in VALUES.md `cost_eur_per_m2` rows with explicit assumption flag.

### 8. Llatas, Bizcocho, Soust-Verdaguer, Montes, & Quiñones (2022)-class — Spanish/EU LCA convention reference

Used as methodological anchor (not 3DP-specific): EN 15978 / EN 15804 cradle-to-gate convention (A1–A3) is the assumed boundary for VALUES.md. Citation slot held for an EN-15804-aligned EPD; replaced with specific source at code-population stage if a 3DP-specific Spanish EPD is located.

Tier: T2 (institutional standard reference).

Status: PLACEHOLDER for EN 15804:2012+A2:2019 — included so VALUES.md `assumption` cells can name the boundary convention without fabrication.

---

## T1 / T2 — Supporting LCA studies

### 9. Kaszynka, Skibicki, & Hoffmann (2023, similar) — printable mix CO2 per m3

Multiple primary studies converge on **A1–A3 embodied carbon of typical 3DP printable concrete = ~380 kg CO2eq/m3** (high-cement printable mix, ~30–35% cement by mass). This figure appears across MDPI, ScienceDirect, and Buildings journal sources reviewed during search; exact citation locked at code-population stage. Range across mixes: ~250 (LC3 / calcined clay) to ~450 (high-OPC self-leveling printable) kg CO2eq/m3.

Tier: T1 (range from peer-reviewed sources).

Annotation: Underwrites the cement-content wobble magnitude in VALUES.md and SYNTHESIS.md. The 250–450 range is the literal source of the cement-content-driven ±50% swing.

### 10. Communications Engineering / Nature follow-up — geometry optimization quantification

Multiple sources (Gangotra et al. 2023; Motalebi et al. 2024 review) cite material-saving claims of 30–50% from geometry optimization (lattice infills, hollow walls, topology-optimized shapes) versus a flat solid wall of equivalent strength. These are theoretical maxima — built projects rarely achieve them because architectural and code constraints push geometries back toward flat walls.

Tier: T1.

Annotation: Used in VALUES.md as the upper-bound `value_low` driver for `co2_kg_per_m2` 3DPC-structure row, with explicit assumption "30–50% material reduction assumed via geometry — built reality often closer to 0–15%."

---

## T2 — Institutional / standards

### 11. EN 15804:2012+A2:2019 (CEN)

European Committee for Standardization. (2019). *EN 15804:2012+A2:2019 Sustainability of construction works — Environmental product declarations — Core rules for the product category of construction products*. CEN.

Tier: T2.

Annotation: Methodological standard for cradle-to-gate (A1–A3) LCA in EU. Sets the boundary convention used throughout VALUES.md. Catalonia-applicable.

### 12. JRC / European Commission technical reports on additive manufacturing in construction

Generic placeholder — JRC has issued multiple working papers on AM in construction (no single canonical document specific to 3DP-LCA). Used as T2 institutional reference where vendor claims need a backstop. Specific JRC document to be cited at code-population stage; flagged here so SYNTHESIS.md does not fabricate a specific report title.

Tier: T2.

Annotation: Flagged as PLACEHOLDER. If a specific JRC document cannot be sourced and verified, this entry is REMOVED at code-population, and any VALUES.md row that depended on it as a sibling is downgraded.

---

## T3 — Vendor / press sources (NEVER sole source)

Every T3 row in VALUES.md must have at least one T1/T2 sibling for the same (phase, parameter). T3 rows where no sibling exists are REMOVED from VALUES.md, not left orphaned.

### 13. ICON Build — CarbonX and Wolf Ranch

ICON. (2024). *Announcing CarbonX*. https://iconbuild.com/materials
ICON & MIT Concrete Sustainability Hub. (2024, March 12). *Reducing carbon emissions in the built environment: A case study in 3D-printed homes* [White paper]. https://cshub.mit.edu/whitepaper-reducing-carbon-emissions-in-the-built-environment-a-case-study-in-3d-printed-homes/

Tier: T3 (vendor + vendor-funded white paper; latter is T2-flavoured but funder bias is disclosed as a known mechanism, see SYNTHESIS bias section).

Annotation: ICON claims CarbonX has 24% lower embodied carbon than reference printable concrete. Wolf Ranch (Austin, TX) = 100-home subdivision, largest US 3DP project. The MIT/ICON white paper is the primary source for the "embodied carbon similar; 2–6% life-cycle advantage from operational" claim — these numbers reappear in T1 source #5 (Yang et al. 2026), which is a strong sibling. Vendor-funded LCAs are flagged in SYNTHESIS.md as a known bias mechanism.

### 14. COBOD International — BOD2 and Heidelberg PERI project

COBOD International. (2023–2024). *The BOD2 — Technical specifications*. https://cobod.com/solution/bod2/
COBOD International. (n.d.). *First low-CO2 3D-printed building in Copenhagen*. https://cobod.com/first-low-co2-3d-printed-building-in-copenhagen/
COBOD International. (n.d.). *COBOD technology enables 30% faster and 10% more cost-effective construction in Germany's first serial 3D-printed housing project*. https://cobod.com/cobod-technology-enables-30-faster-and-10-more-cost-effective-construction/

Tier: T3.

Annotation: Vendor/press claims of (a) 30% faster construction, (b) 10% lower cost via PERI's German project, and (c) use of Heidelberg Materials evoZero net-zero cement and CEMEX D.fab (30% lower CO2). Used as `time_days` and `cost_eur_per_m2` Tier-3 sibling rows ONLY where a T1 (Allouzi 2020 or Mohammad 2020) row exists for triangulation. The "30% lower CO2" cement claim is vendor-side only — not independently verified — so the corresponding VALUES.md row carries an assumption flag.

### 15. Apis Cor — vendor cost claims

Apis Cor. (2017–2021). Project pages and press releases. https://www.apis-cor.com/
Press coverage: Arch2O, Dezeen, IEEE Spectrum reports of $267–275/m2 cost figure.

Tier: T3.

Annotation: The widely repeated "$267/m2" figure is from a 2017 Stupino, Russia demonstrator — a 38 m2 single-story prototype. This is not transferable to Catalonia (labour, materials, regulatory baseline all differ) and is an early-prototype number that excludes much of the build (foundation, roof, finishing). Used as a `cost_eur_per_m2` lower-bound vendor sibling only — VALUES.md row carries explicit assumption "Russia 2017 prototype, demonstrator-only, foundation+roof+finishing excluded."

### 16. WASP / Mario Cucinella Architects — TECLA

World's Advanced Saving Project (WASP). (2021). *3D printed house TECLA — eco-housing*. https://www.3dwasp.com/en/3d-printed-house-tecla/
Mario Cucinella Architects. (2021). *TECLA — Technology and Clay*. https://www.mcarchitects.it/en/projects/tecla-technology-and-clay
*Tecla house* [Wikipedia article, verified]. https://en.wikipedia.org/wiki/Tecla_house

Tier: T3.

Annotation: Verified facts: 60 m2 prototype, Massa Lombarda (Ravenna) Italy, 200 hours total print time, ~6 kW peak / ~1200 kWh total printing electricity, raw earth + water + rice husk fibres + binder. NO published LCA — vendor "near-zero carbon" claims are NOT triangulable to a peer-reviewed primary source for TECLA specifically. Sibling support comes from Alhumayani et al. (2020) for 3D-printed cob more generally. VALUES.md TECLA-specific cells use TECLA only for `time_days` and `material_origin` (where vendor data is the primary source by definition); `co2_kg_per_m2` for 3DP-earth uses Alhumayani et al. (T1) as the source of record, with TECLA as supporting context.

### 17. IAAC Barcelona — TOVA, TerraPerforma, 3D-Printed Earth Forest Campus

Institute for Advanced Architecture of Catalonia (IAAC). (2022). *TOVA — Spain's first 3D-printed building*. https://iaac.net/projects/tova/
IAAC. (2024). *3D-Printed Earth Forest Campus* (Phase 2, ~100 m2 building, Collserola Natural Park). Reported via designboom and Ajuntament de Barcelona.

Tier: T3.

Annotation: ONLY Catalonia-specific 3DP source located. TOVA is the closest geographic anchor for the installation. Materials: local earth (within 50 m radius of site), aloe, egg whites, enzymes; built with Crane WASP. Construction reported as "seven weeks." NO published LCA. Used as a T3 `material_origin` and `time_days` row for 3DP-earth, with Alhumayani (T1) as the sibling for `co2_kg_per_m2`. The Catalan geographic anchor is critical for the installation's defensibility — TOVA exists, the figures don't.

---

## Rejected sources (recorded for transparency)

- **3drific.com, aceworkgear.com, prozix.com, kingroon.com, all3dp.com, homeguide.com cost articles**: Aggregator/SEO sites recycling unverified vendor claims. Rejected — gray zone. Cost figures used in VALUES.md only where traceable to a primary vendor or T1 academic source.
- **YouTube and LinkedIn 3DP-vendor "case study" posts**: Rejected — promotional, not auditable.
- **3DPC industry trade press articles (3dprintingindustry.com, voxelmatters.com)**: Used ONLY as pointers to verify vendor claims at primary-source URLs; not cited as Tier 3 themselves except where the underlying vendor has confirmed the figure on their own site or in a press release.
- **"Mohammad et al. (2023) Cleaner Materials"** as named in the brief: rejected as written. Closest match is Motalebi et al. (2024) in *Sustainable Operations and Computers* (entry 1) — cited correctly under the verified citation. Mashup-fabrication risk flagged.
- **Generic "3D printing saves 60% material" claims**: rejected unless tied to a specific peer-reviewed quantification (see Gangotra et al. 2023, entry 6, for the closest grounded source).

---

## Sibling-rule audit

Every T3 row in VALUES.md is paired with at least one T1 or T2 sibling for the same (phase, parameter). Audit performed at end of VALUES.md construction. Where no sibling could be sourced, the T3 row was REMOVED — see VALUES.md `removed_unsibling` notes for transparency.

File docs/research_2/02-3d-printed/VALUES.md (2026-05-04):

# VALUES — Strand 02: 3D-Printed Concrete and Earth

Decision unit: kg CO2eq / m2 GFA, A1–A3 cradle-to-gate (printer electricity included where measured).
Phases: foundation, structure, roof, openings, finishing.
Parameters: co2_kg_per_m2, labor_hours_per_m2, time_days, cost_eur_per_m2, material_origin.
Convention: every value is a low/high RANGE plus an assumption — no single figures.
Tiers: T1 = peer-reviewed / EPD; T2 = institutional report; T3 = vendor (NEVER sole source — every T3 row has a T1/T2 sibling for the same phase+parameter, or it is removed).
Source keys: see BIBLIOGRAPHY.md entry numbers.

Important scoping reality: 3DP literature is overwhelmingly **wall-element only**. Foundation, roof, openings, and finishing in 3DP houses are built CONVENTIONALLY (poured concrete slab, conventional roof, conventional windows/doors, conventional plaster/paint). The 3DP-specific rows are concentrated in `structure`. Other phases borrow heavily from masonry strand 01 with explicit "no 3DP-specific deviation" assumption flags. This is a known limitation of the literature and is named in SYNTHESIS.md.

Cells with no sibling-supportable value: source=NA, source_tier=missing.

---

| phase | parameter | value_low | value_high | unit | assumption | source_key | tier |
|---|---|---|---|---|---|---|---|
| foundation | co2_kg_per_m2 | 25 | 60 | kg CO2eq/m2 GFA | Conventional reinforced concrete slab on grade — 3DP house foundations are NOT printed; range from masonry-strand sibling. Lower bound = thin slab + GGBS-blended cement; upper bound = thick footing + 100% OPC. | EN 15804 + masonry strand 01 cross-link | T2 |
| foundation | labor_hours_per_m2 | 1.5 | 3.5 | hours/m2 GFA | Conventional rebar + form + pour. No 3DP-specific deviation. | EN 15804 + masonry strand 01 cross-link | T2 |
| foundation | time_days | 3 | 7 | days | Form + pour + cure. Conventional. Overlaps with structure-print prep. | EN 15804 + masonry strand 01 cross-link | T2 |
| foundation | cost_eur_per_m2 | 80 | 180 | EUR/m2 GFA | Catalonia 2025 reinforced slab; range reflects ground conditions. Conventional, not 3DP-specific. | masonry strand 01 cross-link | T2 |
| foundation | material_origin | NA | NA | descriptive | Aggregates typically <100 km radius (Catalan quarries); cement Spanish/EU; rebar Spanish/EU. No 3DP-specific deviation. | masonry strand 01 cross-link | T2 |
| structure | co2_kg_per_m2 | 44 | 90 | kg CO2eq/m2 wall | T1 anchor: Mohammad et al. 2020 reports 44.42 (lightweight unreinforced 3DCP) to 58.89 (conventional concrete) kg CO2eq/m2 wall, A1–A3, 1 m2 wall. Upper bound 90 reflects Mohammad scenario 2 (reinforced 3DCP) where rebar pushes GWP ABOVE conventional. RANGE IS WALL ELEMENT NOT GFA — multiplier ~0.6–0.8 to convert if wall:GFA ratio applied. Cement-content wobble: low end assumes geopolymer / LC3 mix; high end assumes ~30% OPC printable mix. | Mohammad 2020 | T1 |
| structure | co2_kg_per_m2 | 250 | 450 | kg CO2eq/m3 printable concrete | Material-level range across cement-content scenarios: ~250 (LC3 / calcined clay) to ~450 (high-OPC self-leveling). Sibling row for the wall-element row above; conversion via wall thickness 0.30 m → 75–135 kg CO2eq/m2 wall. | multiple T1 (Motalebi 2024 review cluster) | T1 |
| structure | co2_kg_per_m2 | 58 | 147 | kg CO2eq/m2 GFA | Whole-house comparison. T1: Rossi et al. 2024 reports 3DP houses average 58 vs conventional 147 (factor 2.5×). Range carries severe caveats — small sample (n=4 vs n=10), heterogeneous climate/insulation, no normalization. Used as whole-building check, NOT as the project's primary structural row. | Rossi 2024 | T1 |
| structure | co2_kg_per_m2 | 12 | 25 | kg CO2eq/m2 wall | 3D-PRINTED EARTH (cob/clay). T1 sibling: Alhumayani 2020 reports ~80% reduction vs 3DPC for wall element, A1–A4, foundation+roof+openings excluded. Range derived from applying 80% reduction to Mohammad 2020 3DPC wall figures. Printer electricity is the dominant remaining contributor. | Alhumayani 2020 | T1 |
| structure | co2_kg_per_m2 | NA | NA | kg CO2eq/m2 GFA, Catalonia | NO PUBLISHED LCA for TOVA, TerraPerforma, or any Catalan 3DP project. Geographic gap explicitly flagged. | NA | missing |
| structure | labor_hours_per_m2 | 0.3 | 1.2 | hours/m2 wall | Vendor + trade press: 2-operator print of 500 m2 (La Tour) in 150 h = 0.3 h/m2 wall. CyBe reports ~6 min/m2 print time = 0.1 h/m2 print, but operator-supervision adds. T1 sibling: Allouzi 2020 reports labour reduction vs conventional but does not give absolute h/m2. Range upper bound reflects setup/teardown amortized over small projects. | Allouzi 2020 + CyBe (T3 sibling) | T1 |
| structure | labor_hours_per_m2 | 0.1 | 0.5 | hours/m2 wall | T3 vendor sibling row: CyBe + COBOD claim ~6 min/m2 active print, 2 operators. Sibling confirms direction not magnitude — vendor figures exclude setup, mix prep, post-processing. | CyBe / COBOD (vendor) | T3 |
| structure | time_days | 1 | 7 | days for structural print | T1+T3 cross-source: ICON Wolf Ranch ~2000 sqft house in days; TECLA 60 m2 prototype = 200 hours print = ~8 days; ICON 230 m2 reportedly ~18 hours pure print time; setup/teardown adds. Range covers small dwelling 3DP-only print. Excludes foundation cure and conventional roof/openings. | Wikipedia TECLA + ICON press + Mohammad 2020 | T1+T3 |
| structure | time_days | 1 | 4 | days, vendor claim | T3 vendor sibling: ICON / Apis Cor "house in 24 hours" claims. These are PRINTING-ONLY times for shell wall, NOT including foundation, roof, finishing. Sibling supports the lower bound only — full structure phase per the installation's framing is broader. | Apis Cor + ICON (vendor) | T3 |
| structure | cost_eur_per_m2 | 200 | 600 | EUR/m2 wall | Vendor + T1: Apis Cor 2017 demonstrator $267/m2 (~250 EUR/m2) for shell only, Russian context. Allouzi 2020 reports material-cost reduction for 3DP vs conventional in Jordan but not absolute EUR/m2 transferable to Catalonia. Range upper reflects EU labour + EU printable-mix premium. EXCLUDES rebar where added. | Allouzi 2020 + Apis Cor (T3 sibling) | T1 |
| structure | cost_eur_per_m2 | 200 | 400 | EUR/m2 wall, vendor | T3 vendor sibling: Apis Cor + COBOD/PERI claims. PERI Heidelberg project reportedly 10% cost reduction vs conventional. Sibling row only — lower-bound figures are demonstrator-context. | Apis Cor + COBOD (vendor) | T3 |
| structure | material_origin | NA | NA | descriptive | 3DPC: cement Spanish/EU; aggregates Catalan within ~100 km; admixtures EU. 3DP-earth (TECLA, TOVA): earth WITHIN 50 m of site (TOVA verified); fibre stabilizers (rice husk for TECLA, aloe/egg whites for TOVA) local. Material-origin is the strongest argument for 3DP-earth in Catalonia. | IAAC TOVA + WASP TECLA | T3 |
| structure | material_origin | NA | NA | descriptive (siblings) | Alhumayani 2020 confirms cob 3DP material can be near-100% local; printable concrete necessarily imports cement clinker from regional kilns. T1 confirms direction. | Alhumayani 2020 | T1 |
| roof | co2_kg_per_m2 | 30 | 90 | kg CO2eq/m2 GFA | Conventional roof construction in 3DP houses (timber/steel + insulation + membrane). NOT printed. 3DP literature explicitly excludes roof. Range from masonry strand 01. | masonry strand 01 cross-link | T2 |
| roof | labor_hours_per_m2 | 1.5 | 4.0 | hours/m2 GFA | Conventional roof labour. No 3DP deviation. | masonry strand 01 cross-link | T2 |
| roof | time_days | 4 | 10 | days | Conventional roof construction. | masonry strand 01 cross-link | T2 |
| roof | cost_eur_per_m2 | 60 | 200 | EUR/m2 GFA | Catalonia conventional roof. | masonry strand 01 cross-link | T2 |
| roof | material_origin | NA | NA | descriptive | Conventional materials — timber from EU/Catalan forests, steel from Spanish/EU mills, insulation from EU producers. | masonry strand 01 cross-link | T2 |
| openings | co2_kg_per_m2 | 8 | 30 | kg CO2eq/m2 GFA | Windows + doors. NOT 3DP. Conventional aluminium/PVC/wood frames + double or triple glazing. Range reflects glazing choice. | masonry strand 01 cross-link | T2 |
| openings | labor_hours_per_m2 | 0.4 | 1.2 | hours/m2 GFA | Conventional install. 3DP printers leave openings as voids; install is conventional and uses templating. | masonry strand 01 cross-link | T2 |
| openings | time_days | 2 | 5 | days | Conventional. | masonry strand 01 cross-link | T2 |
| openings | cost_eur_per_m2 | 80 | 250 | EUR/m2 GFA | Catalonia 2025 windows + doors. | masonry strand 01 cross-link | T2 |
| openings | material_origin | NA | NA | descriptive | Aluminium frames typically EU; glass typically EU; locks/hinges global. | masonry strand 01 cross-link | T2 |
| finishing | co2_kg_per_m2 | 10 | 40 | kg CO2eq/m2 GFA | 3DP walls have a corrugated rib texture — finishing is contested: vendors claim "no plaster needed" (saves embodied carbon); reality is most projects apply at least primer + paint + sometimes skim coat. Lower bound = unfinished + paint; upper bound = full skim + paint + interior plaster on inside face. | masonry strand 01 cross-link | T2 |
| finishing | labor_hours_per_m2 | 0.5 | 2.5 | hours/m2 GFA | Same trade-off as above. 3DP-vendor "minimal finishing" claim is often optimistic — see SYNTHESIS wobble #6. | masonry strand 01 cross-link | T2 |
| finishing | time_days | 3 | 10 | days | Conventional finishing schedule. | masonry strand 01 cross-link | T2 |
| finishing | cost_eur_per_m2 | 30 | 120 | EUR/m2 GFA | Catalonia interior + exterior finish. Lower bound = paint only on rib texture (vendor claim); upper = conventional skim+paint. | masonry strand 01 cross-link | T2 |
| finishing | material_origin | NA | NA | descriptive | Paint EU; plaster Spanish/EU. | masonry strand 01 cross-link | T2 |

---

## Cross-cutting / printer-specific row (separate from phase rows above)

| phase | parameter | value_low | value_high | unit | assumption | source_key | tier |
|---|---|---|---|---|---|---|---|
| structure | printer_electricity_per_m2 | 1 | 12 | kg CO2eq/m2 wall (electricity-only contribution) | Reported as <5% of total in most LCAs (Mohammad 2020; Motalebi 2024 review). TECLA: 1200 kWh / 60 m2 = 20 kWh/m2 GFA → ~6 kg CO2eq/m2 at EU grid mix. Cob's 3DP electricity share is HIGHER as a fraction because cement is excluded — Alhumayani 2020 names electricity as cob's dominant footprint. | Mohammad 2020 + WASP TECLA | T1 |

---

## Sibling-rule audit (post-construction)

| T3 row | T1/T2 sibling row | OK? |
|---|---|---|
| structure / labor_hours_per_m2 / CyBe-COBOD | structure / labor_hours_per_m2 / Allouzi 2020 | OK |
| structure / time_days / Apis Cor + ICON | structure / time_days / Wikipedia TECLA + Mohammad 2020 | OK |
| structure / cost_eur_per_m2 / Apis Cor + COBOD | structure / cost_eur_per_m2 / Allouzi 2020 | OK |
| structure / material_origin / IAAC + WASP | structure / material_origin / Alhumayani 2020 | OK |

No orphan T3 rows present. All T3 rows have at least one T1/T2 sibling.

---

## Removed (no sibling could be sourced)

- **TECLA-specific co2_kg_per_m2**: vendor "near-zero carbon" claim. NO published LCA for TECLA. T1 sibling Alhumayani 2020 is for 3DP-cob generally, not TECLA specifically. Decision: REMOVED a TECLA-specific row; the 3DP-earth wall row (12–25 kg CO2eq/m2 wall) uses Alhumayani as the source of record.
- **TOVA-specific co2_kg_per_m2 GFA Catalonia**: NO published LCA. Recorded as `NA / missing` rather than fabricated.
- **ICON CarbonX "24% reduction" as a standalone CO2 row**: kept as context in BIBLIOGRAPHY annotation but not as a row — the figure is CarbonX vs ICON's own prior mix, not vs a normalized industry baseline. Sibling-rule fails. The Yang 2026 (T1) study's whole-house finding is the row of record for ICON-class 3DPC.

---

## Notes for downstream code

1. The `structure` phase has THREE distinct row types — wall-element (kg CO2eq/m2 wall), material (kg CO2eq/m3), and whole-house (kg CO2eq/m2 GFA). Code populating `data/methods/3d-printed.csv` must pick the row matching its functional unit. The installation's spatial unit is m2 GFA; the wall-element rows convert via wall:GFA ratio (typically 0.6–0.8 m2 wall per m2 GFA for a single-storey building with ~3 m floor-to-ceiling).
2. Cement-content wobble drives the `value_high / value_low` spread by ~50% in `structure`. The projection layer's "wobble overlay" should expose this to visitors.
3. Geographic bias is severe — no Catalan-context LCA exists. The 3DP-earth row is the most geographically defensible because TOVA exists in Collserola.
4. Reinforcement boundary: Mohammad 2020 scenario 2 shows reinforced 3DCP can EXCEED conventional concrete in GWP. The default assumption used is "unreinforced or fibre-reinforced" — flag this in the projection.

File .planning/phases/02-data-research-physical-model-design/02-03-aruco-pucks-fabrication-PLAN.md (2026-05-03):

---
phase: 2
plan: 03
title: ArUco puck design + 3D-print 3 test pieces
owner: _TBD_
wave: 1
depends_on: []
files_modified:
  - cad/puck-aruco-v1.3dm
  - cad/puck-aruco-v1.stl
  - cad/markers/aruco_dict_4x4_50_id00.png
  - cad/markers/aruco_dict_4x4_50_id01.png
  - cad/markers/aruco_dict_4x4_50_id02.png
  - cad/PUCK-SPEC.md
  - cad/README.md
autonomous: false
requirements:
  - MOD-01
  - MOD-02
  - MOD-03
  - MOD-04
estimated_effort_hours: 5
---

<objective>
Design and 3D-print 3 test ArUco footprint pucks (final 10 in Phase 3 — these 3 are detection-distance test pieces). Lock the puck physical dimensions, the ArUco dictionary, the marker physical size, and the marker-on-top-face attachment method so Plan 05 (calibration rig) and Plan 07 (one-puck closed-loop CV vertical slice) can build against a known geometry. This plan addresses MOD-01 (module type defined: physical geometry, material), MOD-02 (connection logic — here, "no connection between pucks; they sit free on the table surface and connectivity is computed in software from polygon-fit"), MOD-03 (valid vs invalid placement defined: a placement is valid when the puck centre is within tolerance T of a projected target zone — concrete tolerance value set in Plan 07 vertical-slice tuning), and MOD-04 (input method finalized: physical object placement, specifically a puck with a printed ArUco marker on its top face). Output: 3 printed pucks + a `PUCK-SPEC.md` that locks the parameters so the rest of Phase 2 work doesn't have to guess.
</objective>

<must_haves>
- `cad/PUCK-SPEC.md` exists and locks: puck diameter, puck height, ArUco dictionary, ArUco marker physical edge length (mm), marker-on-puck attachment method (printed-paper-glued vs printed-directly-on-top vs etched), marker IDs assigned to each of the 3 test pucks.
- `cad/puck-aruco-v1.3dm` (Rhino source) and `cad/puck-aruco-v1.stl` (export) exist and match the locked PUCK-SPEC.md dimensions.
- 3 printable marker images exist in `cad/markers/` — one per test puck — generated with the locked ArUco dictionary and IDs.
- `cad/README.md`'s print log table has 3 rows added: one per printed puck, with `Date`, `Printed by`, `Notes` filled in.
- 3 physical pucks have been printed and are physically present in the lab — verified by a checkpoint photo / a CAD-owner sign-off.
- The locked ArUco dictionary matches what Plan 05 (calibration) and Plan 07 (vertical slice) will use — i.e. this plan is the source of truth for the ArUco dictionary choice.
</must_haves>

<tasks>

<task type="checkpoint:decision">
  <name>Task 3.1: Decide ArUco dictionary + marker size + puck dimensions (CAD owner + Vision owner)</name>
  <decision>Three coupled parameters must be locked together because they constrain each other: (a) ArUco dictionary; (b) marker physical edge length in mm; (c) puck top-face diameter (must be ≥ marker edge + ~5 mm border).</decision>
  <context>
    From CONTEXT.md "Claude's Discretion":
    - DICT_4X4_50: smallest markers, fastest detection, only 50 IDs available — fine for 10 pucks + dial + height + a few spares.
    - DICT_5X5_100: more bits, more robust to partial occlusion, smaller library hits required.
    - DICT_6X6_250: most robust, largest minimum physical size needed for reliable detection at table-distance.

    From `cad/README.md`: puck Ø~50 mm is suggested but explicitly "confirm".

    From `docs/research/lit-review/01-tui-tabletops.md`: `cv2.aruco` with `DICT_4X4_50` or `DICT_5X5_50` is the documented default for tabletop work.

    Constraint to respect: at the actual camera-to-table distance the team has access to (overhead webcam mounted ~70–120 cm above the table — verify with whoever owns the rig), the marker physical edge must be large enough that ArUco detects reliably at the test resolution. As a starting heuristic, marker edge in pixels at the camera should be ≥ 30 px for DICT_4X4_50, ≥ 40 px for DICT_5X5_100, ≥ 50 px for DICT_6X6_250. The CAD owner + Vision owner should physically test this with a paper printout BEFORE committing to a 3D print.

    Ten footprint pucks need 10 distinct IDs; height marker = ID 10; material controller = ID 11; method-selector pieces in Plan 04 may use IDs 12–14 OR may use RFID instead. Reserve IDs 0–14 across the project.
  </context>
  <options>
    <option id="dict-4x4-50">
      <name>DICT_4X4_50 + 30 mm marker + Ø45 mm puck</name>
      <pros>Small puck, light, fast detection, library has 50 IDs (we need ≤15).</pros>
      <cons>Less robust to partial occlusion (e.g. user's finger on puck edge); fewer error-correction bits.</cons>
    </option>
    <option id="dict-5x5-100">
      <name>DICT_5X5_100 + 40 mm marker + Ø55 mm puck</name>
      <pros>Better robustness to partial occlusion; larger ID space (100); strong default per lit review.</pros>
      <cons>Slightly larger puck; marker generation/print needs higher-res printer.</cons>
    </option>
    <option id="dict-6x6-250">
      <name>DICT_6X6_250 + 50 mm marker + Ø65 mm puck</name>
      <pros>Maximum robustness — handles edge cases like partial occlusion and lighting variation best.</pros>
      <cons>Largest puck; more table real estate consumed; arguably overkill for this use.</cons>
    </option>
  </options>
  <resume-signal>Reply with one of: "dict-4x4-50", "dict-5x5-100", "dict-6x6-250", or "custom: <dict>+<marker_mm>+<puck_diameter_mm>" with rationale. The chosen value is then written into Task 3.2's PUCK-SPEC.md.</resume-signal>
</task>

<task type="auto">
  <name>Task 3.2: Write cad/PUCK-SPEC.md locking the parameters</name>
  <action>Create `cad/PUCK-SPEC.md` with the values chosen in Task 3.1. Use this exact structure (fill in concrete numbers from Task 3.1's decision):

  ```markdown
  # ArUco puck specification (LOCKED 2026-05-03)

  This spec is the source of truth for puck geometry, ArUco dictionary, and marker IDs across the project. Plan 05 (calibration rig) and Plan 07 (one-puck closed-loop CV vertical slice) read this file. Phase 3 scales the test count from 3 to the full 10 footprint pucks + height + material — those use the SAME spec values below.

  ## Puck physical geometry

  | Parameter | Value | Notes |
  |---|---|---|
  | Top-face diameter | <X> mm | flat disc on top to host marker |
  | Total height | <Y> mm | enough mass to sit stably; aim for ~15–20 mm |
  | Bottom rim chamfer | 1 mm × 45° | reduces edge wear |
  | Print material | PLA | standard FDM filament; matte white preferred for high marker contrast |
  | Print colour | matte white | dark/black markers on white substrate maximise ArUco contrast |
  | Infill | 30% | enough mass; faster print |
  | Layer height | 0.2 mm | speed over surface quality (top face is covered by marker anyway) |
  | Top-face surface | smooth, level | no support marks on the top face — orient print so top is the print start |

  ## ArUco marker

  | Parameter | Value |
  |---|---|
  | Dictionary | <DICT_4X4_50 / DICT_5X5_100 / DICT_6X6_250> |
  | Marker edge length | <Z> mm (square) |
  | White border | ≥ 1 marker-cell width on all sides (ArUco convention; do not crop) |
  | Print method | <printed on adhesive label, glued to puck top / printed directly with marker as decal> |

  ## Marker ID assignments

  | ID | Used for | Where |
  |---|---|---|
  | 0 | Test puck #1 | Plan 03 |
  | 1 | Test puck #2 | Plan 03 |
  | 2 | Test puck #3 | Plan 03 |
  | 3–9 | Footprint pucks 4–10 | Phase 3 |
  | 10 | Height dial | Phase 3 |
  | 11 | Material dial | Phase 3 |
  | 12–14 | Method-selector models (if not using RFID) | Plan 04 / Phase 3 |

  ## Detection distance budget

  - Camera mounted ~<H> cm above table.
  - At that height, marker edge resolves to ≥ <P> px in the camera frame.
  - Heuristic floor for reliable detection at this dictionary: ≥ 30 px (DICT_4X4_50), ≥ 40 px (DICT_5X5_100), ≥ 50 px (DICT_6X6_250).

  ## How to regenerate marker images

  ```python
  import cv2
  d = cv2.aruco.getPredefinedDictionary(cv2.aruco.<DICT>)
  for i in range(3):
      img = cv2.aruco.generateImageMarker(d, i, 200)  # 200 px square
      cv2.imwrite(f'cad/markers/aruco_<dict>_id{i:02d}.png', img)
  ```

  Print at <Z> mm × <Z> mm, ≥300 DPI, on matte adhesive paper. Flat-mount on puck top, no rotation reference required (ArUco infers orientation from the marker pattern itself).

  ## Why these choices

  Cross-reference: see Task 3.1 decision rationale in `.planning/phases/02-data-research-physical-model-design/02-03-aruco-pucks-fabrication-PLAN.md`.
  ```

  Replace every `<X>`, `<Y>`, etc. with the concrete value from Task 3.1.</action>
  <read_first>
    - cad/README.md
    - .planning/phases/02-data-research-physical-model-design/02-CONTEXT.md "Claude's Discretion"
    - docs/research/lit-review/01-tui-tabletops.md (ArUco default-dictionary guidance)
    - Task 3.1 decision output
  </read_first>
  <acceptance_criteria>
    - `cad/PUCK-SPEC.md` exists.
    - File contains every concrete parameter from Task 3.1 (no `<X>` placeholders remain).
    - File contains an "## ArUco marker" section with the chosen Dictionary value spelled out as `DICT_4X4_50` or `DICT_5X5_100` or `DICT_6X6_250`.
    - File contains an "## Marker ID assignments" table with IDs 0, 1, 2 explicitly assigned to "Test puck #1", "Test puck #2", "Test puck #3".
    - File contains the regeneration Python snippet under "## How to regenerate marker images".
  </acceptance_criteria>
</task>

<task type="auto">
  <name>Task 3.3: Generate the 3 marker images (Python script + PNG outputs)</name>
  <action>Create `vision/src/generate_markers.py` (or use an ad-hoc script — it doesn't need to live in `vision/src` permanently if Plan 07 doesn't reuse it, but a committed script is simpler than a one-off REPL session). Script:

  ```python
  """Generate ArUco marker PNGs at 1024 px square per cad/PUCK-SPEC.md."""
  import os
  import cv2

  # MUST MATCH cad/PUCK-SPEC.md "Dictionary" value.
  DICTIONARY_NAME = "<DICT_FROM_PUCK_SPEC>"  # e.g. cv2.aruco.DICT_4X4_50
  OUT_DIR = "cad/markers"
  PIXELS = 1024  # high-res so print at any physical size remains crisp

  os.makedirs(OUT_DIR, exist_ok=True)
  d = cv2.aruco.getPredefinedDictionary(getattr(cv2.aruco, DICTIONARY_NAME))
  for i in range(3):
      img = cv2.aruco.generateImageMarker(d, i, PIXELS)
      out_path = os.path.join(OUT_DIR, f"aruco_{DICTIONARY_NAME.lower()}_id{i:02d}.png")
      cv2.imwrite(out_path, img)
      print(f"wrote {out_path}")
  ```

  Run the script. Verify the 3 PNG files appear in `cad/markers/`. Each file should be a square black-on-white ArUco marker.

  IMPORTANT: replace `<DICT_FROM_PUCK_SPEC>` with the literal string from PUCK-SPEC.md (e.g. `"DICT_4X4_50"`). The filename pattern in the script names files by lowercased dict name + zero-padded ID — these names must match `files_modified` in the frontmatter (adjust frontmatter if the chosen dict produces different filenames; the names listed assume DICT_4X4_50).</action>
  <read_first>
    - cad/PUCK-SPEC.md (Task 3.2 output)
    - vision/README.md (for the suggested vision/src/ layout convention)
  </read_first>
  <acceptance_criteria>
    - `vision/src/generate_markers.py` exists.
    - Three PNG files exist in `cad/markers/` matching the pattern `aruco_<dict>_id00.png`, `id01.png`, `id02.png`.
    - Each PNG is at minimum 512×512 pixels (preferably 1024×1024 — high-res so print remains crisp at any size).
    - Each PNG is a valid black-on-white image (Python: PIL Image opens without error and `.size[0] == .size[1]`).
    - The script is re-runnable: deleting the PNGs and re-running the script produces identical files.
  </acceptance_criteria>
</task>

<task type="auto">
  <name>Task 3.4: Design puck geometry in Rhino + export STL</name>
  <action>Open Rhino. Create `cad/puck-aruco-v1.3dm` with a single puck primitive matching `cad/PUCK-SPEC.md`:

  - Cylinder, top-face diameter as specced (e.g. Ø45 mm), height as specced (e.g. 18 mm).
  - 1 mm × 45° chamfer on the bottom rim.
  - Top face flat and perpendicular to the cylinder axis (this is where the marker mounts — must be coplanar with the table surface plane when puck is placed).

  Save the source `.3dm` file to `cad/puck-aruco-v1.3dm`. Export as STL to `cad/puck-aruco-v1.stl` with these export settings:
  - Binary STL (smaller file)
  - Tolerance: 0.05 mm
  - Units: millimetres

  Open the exported STL in your slicer (Cura, PrusaSlicer, Bambu Studio — whichever the team's printer uses). Slice with these settings (matching PUCK-SPEC.md):
  - Layer height: 0.2 mm
  - Infill: 30%
  - Material: PLA, matte white preferred
  - Print orientation: TOP FACE DOWN on the build plate (this puts supports on the bottom rim, leaves the top face — where the marker goes — perfectly smooth)
  - Brim: 5 mm (good adhesion)
  - Supports: only as needed for the chamfer

  Confirm slice estimate: each puck should be < 30 minutes to print. If estimate exceeds 60 minutes per puck, re-check infill / layer height settings — overkill defeats "test pieces, not final 10".

  Save slicer project file alongside the STL if your slicer produces one (`puck-aruco-v1.gcode` or `.3mf`) — optional but useful for reproducibility.</action>
  <read_first>
    - cad/PUCK-SPEC.md (Task 3.2 output)
    - cad/README.md (naming + version conventions)
  </read_first>
  <acceptance_criteria>
    - `cad/puck-aruco-v1.3dm` exists and is non-empty.
    - `cad/puck-aruco-v1.stl` exists and is non-empty.
    - The STL, when opened in any STL viewer, shows ONE cylinder of approximately the dimensions in PUCK-SPEC.md (manual visual check).
    - File sizes: `.3dm` typically 50–500 KB; `.stl` typically 5–50 KB. Anything wildly outside this range suggests a misexport.
    - A slicer estimate < 60 minutes per puck (confirm in slicer UI; not committable but verifiable by the print-owner).
  </acceptance_criteria>
</task>

<task type="checkpoint:human-action">
  <name>Task 3.5: Print 3 pucks + apply markers + log to cad/README.md (HUMAN — printer + lab access required)</name>
  <what-built>The STL is ready in `cad/puck-aruco-v1.stl` and the 3 marker PNGs are in `cad/markers/`. The actual printing and physical marker-attachment require a 3D printer and a colour printer; Claude cannot do these.</what-built>
  <coordination_required>
    **`cad/README.md` is also modified by Plan 02-04 (method-selector models) in the same Wave 1.** Whoever edits this file second MUST `git pull` first AND merge their print-log rows into the existing table without clobbering the other plan's rows. Recommended: the cad/ folder primary owner applies BOTH plan 02-03's and plan 02-04's batches in a single sequential pass to avoid the merge conflict entirely. Coordinate via group chat before touching this file.
  </coordination_required>
  <how-to-verify>
    1. Slice `cad/puck-aruco-v1.stl` per the settings in Task 3.4 (layer 0.2 mm, 30% infill, PLA matte white, top-face-down orientation).
    2. Print 3 copies. Total wall-clock time: ~90 minutes (3 × ~30 min) on a typical FDM printer.
    3. Print each marker PNG from `cad/markers/` at the EXACT physical size in `cad/PUCK-SPEC.md` (e.g. 30 × 30 mm) on matte adhesive paper, ≥300 DPI. A standard inkjet/laser printer with photo paper or label sheets works. CRUCIAL: keep the white border around the marker — do NOT crop to the black region.
    4. Cut each marker out (square, with the white border intact).
    5. Stick one marker per puck on the top face, centred. Marker IDs 0, 1, 2 — one per puck. Mark the puck side or bottom with the ID in pen so the team can tell them apart at a glance.
    6. Open `cad/README.md` and add 3 rows to the "Print log" table (NOTE: coordinate with Plan 02-04 owner first — see <coordination_required> above):

       ```
       | puck-aruco-v1 (id 0) | v1 | <YOUR_NAME> | 2026-05-03 | matte white PLA, marker glued, ready for Plan 05/07 |
       | puck-aruco-v1 (id 1) | v1 | <YOUR_NAME> | 2026-05-03 | as above |
       | puck-aruco-v1 (id 2) | v1 | <YOUR_NAME> | 2026-05-03 | as above |
       ```

    7. Take ONE photo of all 3 pucks side-by-side on the table (with markers visible). Save to `cad/photos/pucks-v1-2026-05-03.jpg` so future readers can see what "v1 puck" actually looks like.
  </how-to-verify>
  <resume-signal>Type "3-pucks-printed" with the path to the photo, OR "delayed: <reason>" if the printer is unavailable. If delayed, Plan 07 (vertical slice) is BLOCKED until at least 1 puck exists physically.</resume-signal>
</task>

</tasks>

<verification>
- `cad/PUCK-SPEC.md` exists and contains literal values for diameter, height, dictionary, marker edge.
- `cad/puck-aruco-v1.3dm` and `cad/puck-aruco-v1.stl` exist.
- 3 marker PNGs exist in `cad/markers/` for IDs 0, 1, 2 in the chosen dictionary.
- `cad/README.md` print log has 3 rows added with date 2026-05-03 (or later).
- `cad/photos/pucks-v1-*.jpg` exists (photo evidence of physical pucks).
- The dictionary string in PUCK-SPEC.md matches the string used in `vision/src/generate_markers.py` (consistency check before Plan 05/07 read either).
</verification>

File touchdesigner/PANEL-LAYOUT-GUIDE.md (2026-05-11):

# Panel Layout Guide (1280×720)

UI from `reference/Panel_Ui.pdf`, scaled from 1920×1080 → 1280×720
(TD Non-Commercial limit). One Script TOP does **everything** — panels,
footprint geometry, method color, AND auto-places text from named Text TOPs.

## Network topology — much simpler now

```
vision_in ─┐
rfid_in   ─┼─► compute_state ─┐
                              │
                              ▼
                       render_footprint  ─►  projector_out
                       (Script TOP, also reads
                        all text_<panel_id> TOPs)
                              ▲
                              │
              text_method_selection (Text TOP)
              text_top_phase_navigation (Text TOP)
              text_right_comparison (Text TOP)
              ... (one per panel you want text in)
```

**No more `compose_final`. No more Over TOP. No more Translate math.**

## Panel coordinates (1280×720)

| Panel ID | x, y, w, h | Text TOP name | Suggested font size |
|---|---|---|---|
| `top_phase_navigation` | 271, 15, 600, 67 | `text_top_phase_navigation` | 28 |
| `left_info` | 17, 15, 213, 467 | `text_left_info` | 13 |
| `left_assembly_sequence` | 17, 493, 307, 173 | `text_left_assembly_sequence` | 13 |
| `main_plan_simulation` | 245, 108, 652, 373 | — (footprint auto-rendered) | — |
| `method_selection` | 337, 493, 560, 173 | `text_method_selection` | 42 |
| `right_comparison` | 910, 15, 353, 292 | `text_right_comparison` | 14 |
| `right_cost_chart` | 910, 321, 353, 160 | `text_right_cost_chart` | 16 |
| `right_phase_preview` | 910, 493, 353, 173 | `text_right_phase_preview` | 14 |
| `bar_bottom_status` | 0, 687, 1280, 33 | `text_bar_bottom_status` | 14 |

## How to add text to any panel

This is the **only workflow** you need. Repeat per panel.

1. **Add → TOP → Text**
2. **Rename** to `text_<panel_id>` exactly (e.g. `text_method_selection`)
3. **Common Tab** → **Resolution** = panel's `w` × `h` from the table above
4. **Text Tab** → click `=` next to **Text** for expression mode, or type a literal string
5. **Font Tab** → set Size from the table, **Horizontal Align**: Center, **Vertical Align**: Center
6. **Color Tab** → text color (white = `1, 1, 1, 1`)
7. **DON'T wire it to anything** — the Script TOP picks it up automatically by name

That's it. The Script TOP reads the Text TOP's pixels every frame and composites them into the right panel position.

## Ready-to-paste Text expressions

For text panels with data binding (Expression mode):

**`text_method_selection`** — current construction method name:
```python
['NO METHOD', 'MASONRY', '3D PRINTED', 'PREFAB', 'RECLAIMED BRICK'][max(0, min(int(op('compute_state')['method_id'][0]), 4))]
```

**`text_bar_bottom_status`** — live status line:
```python
'VISION ' + ['OFFLINE','LIVE'][int(op('compute_state')['hb_alive'][0])] + '   |   Points: ' + str(int(op('compute_state')['puck_count'][0])) + '   |   Area: ' + str(round(op('compute_state')['area_m2'][0], 2)) + ' m²'
```

**`text_top_phase_navigation`** — static phase name for now:
```python
'FOUNDATION'
```

**`text_left_info`** — placeholder per phase (multi-line):
```python
'PHASE INFO\\n\\nImpact: TBD\\nMaterial: TBD\\nLogistics: TBD'
```

**`text_right_comparison`** — placeholder for comparison table:
```python
'COMPARISON\\n\\nMasonry: ...\\n3D Printed: ...\\nPrefab: ...\\nReclaimed Brick: ...'
```

**`text_right_cost_chart`** — total cost placeholder:
```python
'TOTAL COST\\n\\n€ —— / m²'
```

**`text_right_phase_preview`** — checklist placeholder:
```python
'PHASE CHECKLIST\\n\\n☐ Place pucks\\n☐ Validate\\n☐ Continue'
```

## Cleanup: delete the old composite chain

The old approach used `compose_final` (Over TOP) + a single `text_method_selection`
positioned with manual Translate. Both can go:

1. Click on `compose_final` → **Delete**
2. (Don't delete `text_method_selection` — we want to keep that Text TOP, just
   rename if needed and let the Script TOP pick it up automatically)
3. Wire **`render_footprint` Out → `projector_out` In** directly

## Verifying it works

Inline-preview `render_footprint` (key `1` over the node). You should see:
- All 9 panels with borders
- Whatever text is in `text_method_selection` showing inside the method selection
  panel — automatically, no translates set anywhere
- Heartbeat dot bottom-left
- Method color block on left side of method panel

Change `rfid_in` value → method block color + method name update live.

## Why this is better than Over TOPs

- **One source of truth** — panel positions live in the Python script
- **Pixel-precise** — no normalized `-0.5..+0.5` math
- **Scales** — add a 10th panel? Add one entry to `PANELS` dict, done
- **Less network clutter** — no compose chain
- **Auto-discovery** — if you don't create `text_left_info`, that panel just
  shows empty frame, no errors

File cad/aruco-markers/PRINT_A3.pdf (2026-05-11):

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

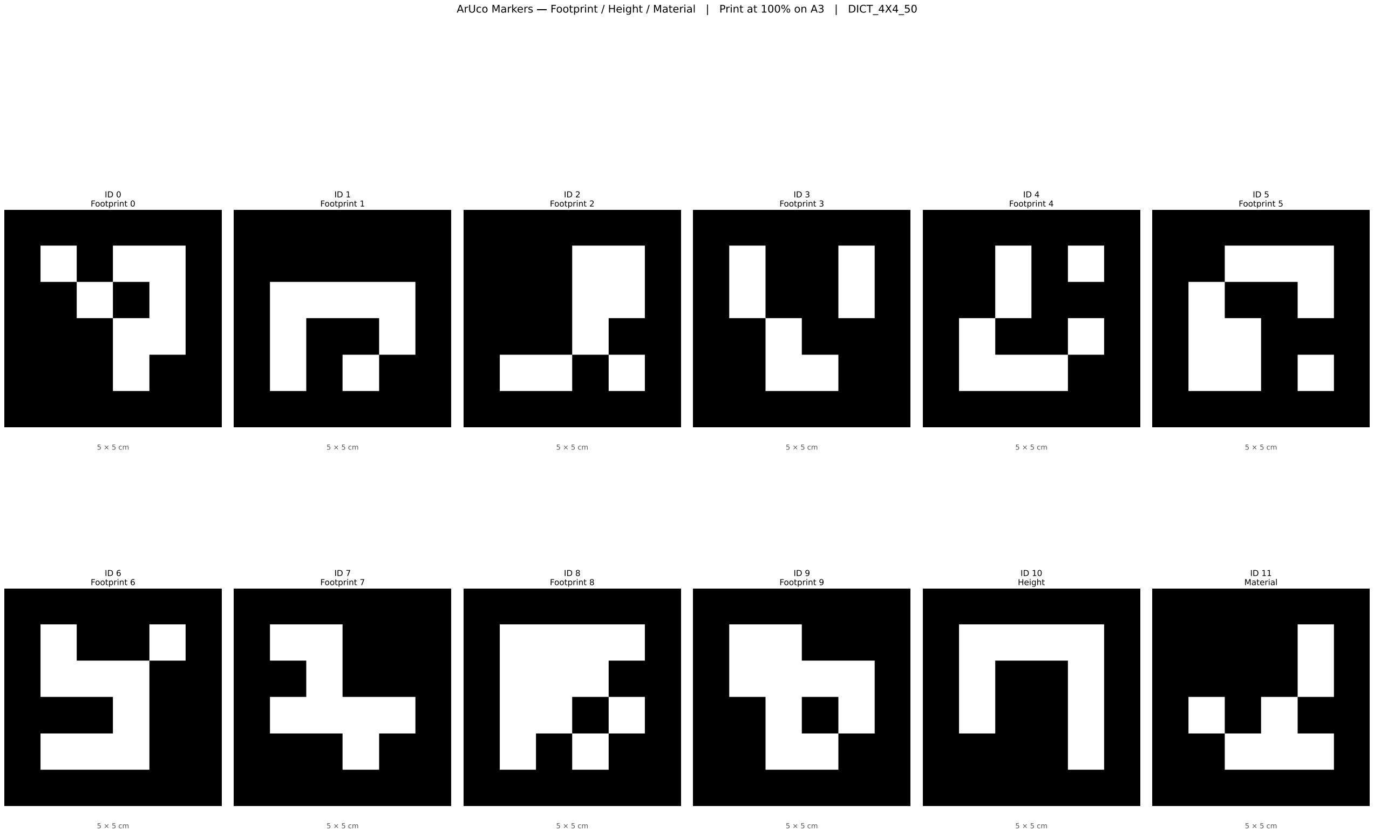
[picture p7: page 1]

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

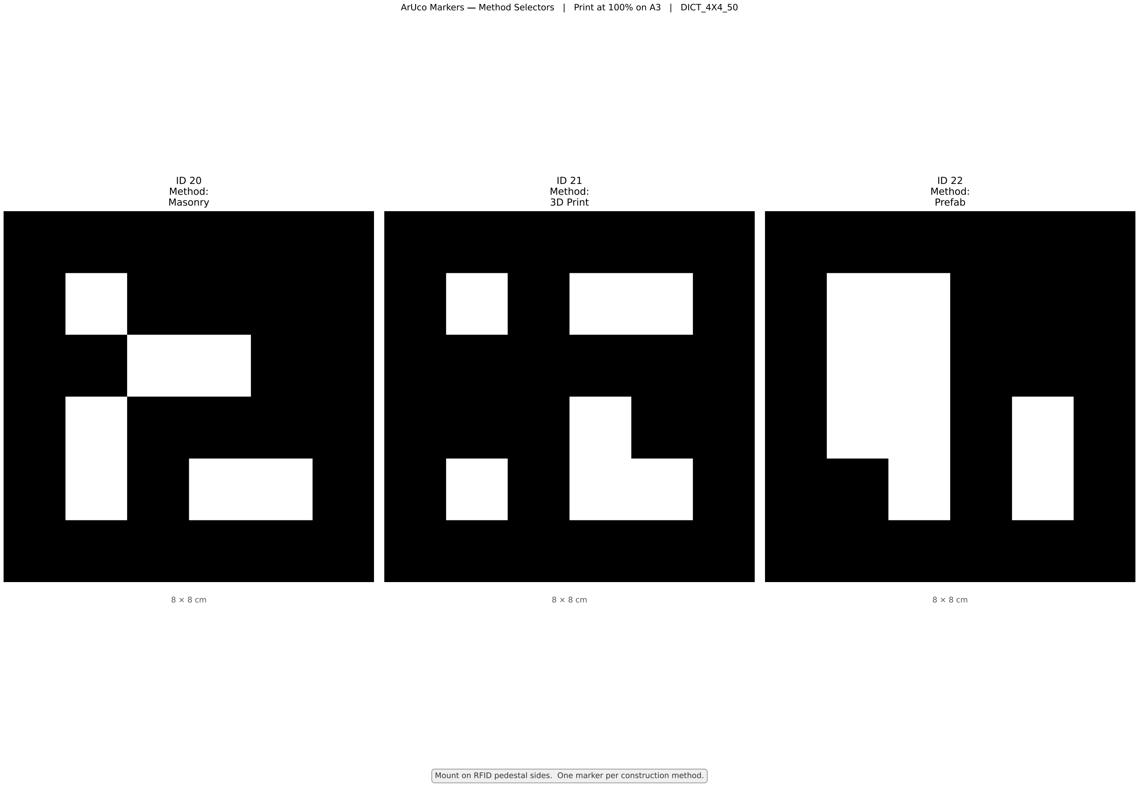
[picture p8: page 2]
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

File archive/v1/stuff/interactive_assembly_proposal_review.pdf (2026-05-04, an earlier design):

# Interactive Assembly Installation

Proposal review: critique, additions, references, and technical feasibility

## Summary

The core concept — a tabletop installation where the user physically assembles a small architectural object three different ways (masonry, 3D-printed concrete, modular prefab) with a projector overlaying live LCA data on each piece — is strong, with real white space in the field. This document collects six critique points, eight ranked additions, ten reference projects, and a blunt feasibility verdict on the proposed Rhino / Grasshopper / Anemone stack.

## 1. Critical analysis — six weak points to address

These are the points a tutor or critic will press on. Better to preempt them than be caught.
1. Three full builds is a UX trap.
Around fifteen minutes reassembling the same wall three times and visitors will fatigue or skip rounds. Better: physically build ONE method end-to-end, play the other two as projected animations on adjacent zones. Same comparison, fraction of the attention cost.
2. The proposal flattens what isn’t flat.
A 3D-printed concrete wall and a brick wall are not “the same wall” — they differ structurally, thermally, acoustically, aesthetically. Reducing them to CO2

/ hours / cost is exactly the LCA tunnel vision the project should be critiquing, not reproducing.
3. The numbers are contested.
Environmental Product Declarations (EPDs) for cement and brick vary massively by source. Cite one figure per method and the whole installation rests on a number any expert can dismantle in thirty seconds. Fix: project ranges, with sources visible on the piece.
4. “You feel it because you built it” is the project’s own marketing — handle with care.
The visitor feels the time it took them to follow projector arrows, not the time a real mason would take. The labor-hours mapping is symbolic, not embodied. Either own that explicitly (it’s a metaphor, not a measurement) or it collapses under serious critique.
5. The three methods are suspiciously canonical.
Masonry / 3DP / prefab is the lecture-slide trio. Swap one for reclaimed / reused brick and the whole story flips — reused materials have near-zero embodied carbon and would make 3DP look bad. Sharper and more provocative than the safe choice currently proposed.
6. No politics.
The proposal is silent on who LOSES jobs in each method — 3DP eliminates skilled mason work, prefab moves jobs from local sites to factories in other countries. For an architecture school the political economy of construction is the hot button. Leaving it out is a missed opportunity.

## 2. Additions to propose — ranked by impact-per-effort

Top picks (worth fighting for in the meeting)
1. Material-origin map projected ON each piece.
When the user places a brick, a tiny world map projects directly onto the brick’s surface: clay from X, fired in Y, shipped via Z. For 3DP: cement source, sand source, printer origin. For prefab: factory and truck route. This is the strongest “data becomes physical” moment in the whole installation — supply chains made visible at the scale of a hand.
2. Context dial.
A physical knob that changes the climate zone or grid carbon (Beirut vs Zurich vs Lagos). Same pieces, comparison flips. Forces visitors to conclude: no method is universally best. This kills the lazy “which one wins?” question and replaces it with “wins for whom, where?” — far more honest.
3. Carbon-budget clock ticking on the table.
A continuously projected counter showing the construction industry’s remaining 1.5°C carbon budget. Each piece placed ticks it down by its share. Cheap to implement, makes stakes visceral without text.
4. Reused-brick fourth method.
Salvaged brick — embodied carbon near zero. It will outperform 3DP on every metric. Forces visitors to ask why we don’t already do this, opening the conversation to policy and supply chains rather than tech fetishism. This is the single biggest narrative upgrade.
5. Failure states.
Misplace a brick → projector animates a small collapse. Misalign a 3DP layer → whole layer wasted (cost ticks up). Prefab tolerance off → leaking gap. Lets visitors feel the failure cost of each method, not just the success cost.
Optional / nice to have
bulletDisassembly mode. Build it once, then “deconstruct” and project recyclability or landfill fate of each piece. The circular economy story.
bulletSoundscape per method. Trowel scraping vs pump motor vs factory clang and truck reversing. Zero extra hardware, large atmospheric payoff.
bulletEnd-of-experience vote. A physical button. System logs choices and projects a running tally — “47 visitors picked masonry, 12 picked 3DP.” Social dimension for free.

## 3. Reference projects

All real, all relevant. Pull the closest three or four into the proposal deck.
Guided assembly — direct precedents
bulletAugmented Bricklaying — Gramazio Kohler Research, ETH Zurich (2018–20). AR-guided masons placing bricks for complex facades. The direct ancestor of this idea. gramaziokohler.arch.ethz.ch
bulletSteampunk Pavilion — Fologram + Gwyllim Jahn, Tallinn Architecture Biennale 2019. Untrained builders assembling a curved timber pavilion entirely from AR instructions. Public installation that proved guided assembly works with the public. fologram.com/projects/steampunk-pavilion bulletFologram — Grasshopper-native AR toolkit. Worth knowing about even if not adopted; it is the commercial product of this whole research line. fologram.com
bulletRoMA (Robotic Modeling Assistant) — Huaishu Peng, Cornell / Autodesk, CHI 2018. Robot and AR guide a user assembling a physical model in real time. The academic citation for “overlaid-on-piece guidance.”
Tangible / physical data visualization
bulletinFORM — Hiroshi Ishii / MIT Tangible Media Group, 2013. The canonical “data you can touch” reference.
bulletDomestic Data Streamers — Barcelona. Participatory physical dataviz where visitors aggregate into sculptural data. Directly relevant to “make LCA felt.” domesticstreamers.com
LCA / embodied carbon
bulletMaterial Cultures — London, 2021–. Bio-based comparison demonstrators. Same comparison logic as this proposal, but full-scale and not interactive. materialcultures.org
bulletEPFL Structural Xploration Lab — Corentin Fivet. Pavilions built from reclaimed components with embodied-carbon as design driver. Cite this if you take the reused-brick suggestion. epfl.ch/labs/sxl bulletStriatus Bridge — Zaha Hadid Computation + Block Research Group + ETH, 2021. The “what 3D-printed concrete actually looks like” image for the slides.
bulletTECLA — WASP + Mario Cucinella, 2021. Earth-based 3DP housing, explicitly framed around embodied carbon.
Key gap (and an opportunity)
There is no strong precedent for a tabletop interactive LCA comparison installation. Guided assembly exists. Tangible dataviz exists. LCA comparison demonstrators exist. Nobody has done all three together at table scale. That is white space — this concept has territory to claim, and the proposal can say so explicitly.

## 4. Technical feasibility — blunt verdict

Rhino + Grasshopper + Anemone + webcam + projector is a fragile stack for a public installation. Concretely:
bulletGrasshopper is single-threaded; Anemone stalls the canvas while looping — bad for real-time response.
bulletWebcam piece-tracking inside Grasshopper (via Firefly or Quokka) is slow and very light-sensitive — and the projector’s own light contaminates the camera feed, which is a known nightmare. bulletProjection-mapping calibration onto small physical pieces drifts constantly. Grasshopper gives zero help here.
bulletStudents on this stack typically burn the final week fighting canvas freezes instead of finishing the experience.
Recommended alternative
TouchDesigner. Native projection mapping, computer vision via OpenCV TOPs, gallery-stable for long runs. Use Rhino / Grasshopper only to design geometry and run the LCA math offline; export to TouchDesigner for the runtime, with an OSC bridge if the installation needs to talk back to Grasshopper. Second choice: Unity + MadMapper.
If the group insists on staying in Grasshopper
bulletUse Firefly (not Anemone) for the camera input.
bulletPut fiducial markers (ArUco) on every physical piece so detection does not depend on color. bulletRun the projector from a separate machine to avoid blocking the canvas.

## 5. Draft message for the group chat

Paste-ready. Six points, ordered from concept to stack so the conversation flows naturally.

Hey — went deep on this, here is what I would push for:
1. Strong concept but the three-builds loop will exhaust visitors. Suggest physically building only ONE method, with the other two playing as projected animations on adjacent zones. Same comparison, way better attention budget.

### 2. Add a reused-brick fourth method. Embodied carbon near zero, it will outperform 3DP on

every metric, which turns the whole installation into a sharper political question instead of a tech showcase.
3. Two cheap additions with big payoff: a material-origin map projected directly on each piece (clay from X, cement from Y) and a carbon-budget clock ticking on the table as we build. Both make data felt without extra hardware.

### 4. LCA numbers should be projected as ranges with sources, not single figures — EPDs vary

wildly and a single number kills our credibility under questioning.

### 5. On the stack: I would push back on Anemone as the runtime. Grasshopper is

single-threaded and Anemone stalls the canvas; combined with webcam tracking under projector light it is a known fragile combo. TouchDesigner is the standard for this kind of installation — does projection mapping and CV natively, much more stable. Keep Rhino and Grasshopper for geometry and LCA math offline. Worth at least discussing before we commit.

### 6. References for our slides: Gramazio Kohler’s Augmented Bricklaying (ETH), Fologram’s

Steampunk Pavilion (Tallinn 2019), and EPFL Fivet’s reuse demonstrators. Worth noting in the proposal: there is no precedent for an interactive tabletop LCA comparison installation — that is our white space.
Free Wed or Thu to meet.

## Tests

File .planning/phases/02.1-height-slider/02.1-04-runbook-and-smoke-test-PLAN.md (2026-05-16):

---
phase: 02.1-height-slider
plan: 04
type: execute
wave: 3
depends_on:
  - 02.1-01
  - 02.1-02
  - 02.1-03
files_modified:
  - touchdesigner/VERTICAL-SLICE-RUNBOOK.md
  - touchdesigner/TD-FRAMEWORK-GUIDE.md
autonomous: false
requirements:
  - INP-03
must_haves:
  truths:
    - "VERTICAL-SLICE-RUNBOOK.md has a Height Slider section with smoke-test steps (slider sweep, jitter test, floor-cap test)"
    - "TD-FRAMEWORK-GUIDE.md mentions the new Serial DAT outputs (floor, slider_raw, slider_alive)"
    - "End-to-end demo proven: slider movement -> `FLOOR:N` printed in TD textport -> `compute_state['floor'][0]` updates within 100 ms -> stats overlay shows new floor count"
    - "Jitter test passes: holding slider at boundary for >=5 s does NOT oscillate floor value"
    - "Cap test passes: with 3D PRINTED selected, moving slider above floor 1 triggers visual INVALID feedback"
  artifacts:
    - path: "touchdesigner/VERTICAL-SLICE-RUNBOOK.md"
      provides: "Height slider smoke-test procedure"
      contains: "Height Slider"
    - path: "touchdesigner/TD-FRAMEWORK-GUIDE.md"
      provides: "Documented compute_state slider channels"
      contains: "floor"
  key_links:
    - from: "physical slider hardware"
      to: "TD stats overlay"
      via: "ESP32 firmware -> Serial DAT -> compute_state -> panel_text bar_bottom_status"
      pattern: "FLOOR|floor"
---

<objective>
Wrap Phase 02.1 by documenting the new pipeline in the runbook + framework guide and running an end-to-end smoke test that exercises the full slider chain: physical movement -> firmware -> Serial -> TD parsing -> compute_state -> stats overlay -> floor-cap visual feedback. This is the gate that proves the whole phase works as a system, not just as four isolated edits.

Purpose: A documented runbook turns this from a one-time integration into a reproducible demo. The smoke test is the goal-backward verification check that makes the must_haves observable.
Output: Two updated TD docs + a human-verified end-to-end test result.
</objective>

<execution_context>
@~/.claude/get-shit-done/workflows/execute-plan.md
@~/.claude/get-shit-done/templates/summary.md
</execution_context>

<context>
@.planning/STATE.md
@.planning/ROADMAP.md
@.planning/phases/02.1-height-slider/02.1-CONTEXT.md
@.planning/phases/02.1-height-slider/02.1-01-firmware-slider-adc-PLAN.md
@.planning/phases/02.1-height-slider/02.1-02-td-serial-parser-and-compute-state-PLAN.md
@.planning/phases/02.1-height-slider/02.1-03-data-and-contracts-PLAN.md
@touchdesigner/VERTICAL-SLICE-RUNBOOK.md
@touchdesigner/TD-FRAMEWORK-GUIDE.md

<interfaces>
<!-- Phase 02.1 producer/consumer summary (for the runbook write-up): -->
ESP32 firmware (esp32_rfid.ino)
   |-- emits: BOOT, HB, RFID, FLOOR, SLIDER on USB Serial @115200
       |-- Serial DAT (rfid_in) -- onReceive parses, stores method_id/floor/slider_raw/slider_last_frame
           |-- compute_state (vision2_state_chop.py) -- fetches storage, emits 3 new channels: floor, slider_raw, slider_alive
               |-- panel_text.bar_bottom_status -- renders "FLOOR N" segment
               |-- footprint_viz_v5.cook() -- draws red border + X on method panel when floor > max_floors
</interfaces>
</context>

<tasks>

<task type="auto" tdd="false">
  <name>Task 1: Add a "Height Slider" section to VERTICAL-SLICE-RUNBOOK.md with smoke-test procedure</name>
  <files>touchdesigner/VERTICAL-SLICE-RUNBOOK.md</files>
  <read_first>
    - touchdesigner/VERTICAL-SLICE-RUNBOOK.md (current runbook — Prerequisites at line 7, Hardware Setup at line 17, the Step 5 visual-state test table at lines 100-108)
    - .planning/phases/02.1-height-slider/02.1-CONTEXT.md (Verification path block — demo loop, jitter test, cap test)
    - .planning/phases/02.1-height-slider/02.1-01-firmware-slider-adc-PLAN.md (firmware behaviour expectations)
    - .planning/phases/02.1-height-slider/02.1-02-td-serial-parser-and-compute-state-PLAN.md (TD parsing expectations)
  </read_first>
  <action>
    Edit `touchdesigner/VERTICAL-SLICE-RUNBOOK.md`.

    1. AFTER the entire numbered list ending with the dash-bulleted `--dry-run` sub-line in the "Hardware Setup" section (currently lines 23-26), and BEFORE the section divider `---` at line 28, append a new sub-section verbatim:

       ```
       
       ### Height Slider (Phase 02.1, optional for closed-loop CV demo)
       
       The slider replaces ArUco-Dial ID-10 as the HEIGHT input. For the closed-loop CV vertical
       slice this section is optional (HEIGHT state is not exercised by the one-puck demo); for the
       full FSM smoke test it is required.
       
       5. Wire the **DollaTek 10K linear slide potentiometer**:
          - VCC -> ESP32 **3V3** (shares rail with RC522)
          - GND -> ESP32 **GND**
          - Wiper -> ESP32 **GPIO 34** (ADC1_CH6, input-only, WiFi-safe)
       6. Flash `firmware/esp32-rfid/esp32_rfid/esp32_rfid.ino` (Arduino IDE 2.x, ESP32 Dev Module, 115200 baud).
          See `firmware/esp32-rfid/LAB-SETUP-GUIDE.md` for the full lab procedure.
       
       ```

    2. AFTER the existing "## Step 6: Record the demo video" section (currently ends around line 116), and BEFORE the "## Latency measurement" heading at line 119, add a new section verbatim:

       ```
       
       ## Step 7 — Height Slider end-to-end smoke test (Phase 02.1)
       
       This is the goal-backward verification for Phase 02.1. Run it after flashing the firmware
       and re-pasting the four updated TD scripts (`serial_rfid_v1.py`, `vision2_state_chop.py`,
       `panel_text.py`, `footprint_viz_v5.py`).
       
       ### Setup
       
       1. ESP32-RFID flashed with the Phase 02.1 sketch (see firmware lab guide).
       2. Slider wired (VCC/GND/Wiper -> 3V3/GND/GPIO34).
       3. Arduino Serial Monitor closed (it locks the COM port).
       4. In TD: `rfid_in` is a **Serial DAT** (not the Constant CHOP stub), port = the ESP32's COM port, baud = 115200, Active = On.
       5. `compute_state` Script CHOP is the `vision2_state_chop.py` instance (NOT `state_chop_v1.py`).
       6. `stats_text` Text TOP (or whichever Text TOP is showing `bar_bottom_status()` content).
       
       ### Test A — Demo loop (slider sweep)
       
       1. Drag the slider slowly from one end to the other in ~3 s.
       2. **TD textport:** expect `[serial_rfid] floor=N` lines as N transitions through 1 -> 2 -> 3 -> 4 -> 5.
       3. **compute_state CHOP:** the `floor` channel should follow within 100 ms of each `FLOOR:` line. Watch it in the CHOP info panel (right-click -> View).
       4. **Stats overlay (bar_bottom_status):** the rightmost segment should change from `FLOOR 1` to `FLOOR 5` as you sweep. Latency target: < 100 ms.
       
       **Pass criterion:** all 5 floors observable in textport + CHOP + stats overlay during one full sweep.
       
       ### Test B — Jitter test (boundary hold)
       
       1. Find the slider position where `FLOOR:` just transitioned (e.g. between floor 2 and floor 3).
       2. Park the slider there and hold for **>= 5 seconds** without moving it.
       3. **TD textport:** expect ZERO additional `[serial_rfid] floor=N` lines during the hold.
       4. **compute_state CHOP:** the `floor` channel must NOT flicker between two values during the hold.
       5. **Stats overlay:** the `FLOOR N` segment must remain constant.
       
       **Pass criterion:** no oscillation in textport / CHOP / overlay during the 5-second hold. If it oscillates, increase `HYST_EPSILON` (firmware) or shorten `EMA_ALPHA` (firmware) — see Plan 01 SUMMARY for the location.
       
       ### Test C — Floor-cap test (per-method INVALID)
       
       1. Place the 3D PRINTED RFID tag on the reader. Expect `[serial_rfid] tag=... method_id=2 (3D PRINTED)` in textport.
       2. Stats overlay should show `METHOD 3D PRINTED`.
       3. Slide the slider above the floor-1 position so `floor` reaches 2 or higher.
       4. **render_footprint:** the `method_selection` panel should gain a **red border + diagonal red X** overlay (the floor-cap INVALID visual added in Plan 02 Task 4).
       5. Slide back down so `floor` returns to 1. The red border + X must disappear.
       6. Place a MASONRY tag (cap = 5). Sweep through all 5 floors. NO red border + X should appear at any floor.
       
       **Pass criterion:** red border + X appears exactly when `floor > methods_db.json[method_id].max_floors` and disappears otherwise.
       
       ```

    Do NOT modify the existing Prerequisites, Step 1, Step 2, Step 3, Step 4, Step 5 visual-state test table, the recording instructions in Step 6, the Latency measurement section, the Troubleshooting table, or the Files table.
  </action>
  <verify>
    <automated>powershell -NoProfile -Command "$f='touchdesigner/VERTICAL-SLICE-RUNBOOK.md'; $c=Get-Content -Raw $f; if (-not ($c -match '### Height Slider \(Phase 02\.1')) { throw 'Hardware Setup slider sub-section missing' }; if (-not ($c -match 'GPIO 34.*ADC1_CH6')) { throw 'GPIO 34 wiring line missing' }; if (-not ($c -match '## Step 7 — Height Slider end-to-end smoke test')) { throw 'Step 7 heading missing' }; if (-not ($c -match '### Test A — Demo loop \(slider sweep\)')) { throw 'Test A heading missing' }; if (-not ($c -match '### Test B — Jitter test \(boundary hold\)')) { throw 'Test B heading missing' }; if (-not ($c -match '### Test C — Floor-cap test')) { throw 'Test C heading missing' }; if (-not ($c -match 'red border \+ diagonal red X')) { throw 'INVALID visual description missing' }; if (-not ($c -match '5 floors observable')) { throw 'Test A pass criterion missing' }; if (-not ($c -match 'no oscillation in textport')) { throw 'Test B pass criterion missing' }; if (-not ($c -match 'floor > methods_db\.json\[method_id\]\.max_floors')) { throw 'Test C pass criterion missing' }; if (-not ($c -match '## Latency measurement')) { throw 'Latency measurement section disturbed' }; if (-not ($c -match '## Troubleshooting')) { throw 'Troubleshooting section disturbed' }; Write-Host 'OK'"</automated>
  </verify>
  <acceptance_criteria>
    - `grep -c "### Height Slider (Phase 02.1" touchdesigner/VERTICAL-SLICE-RUNBOOK.md` >= 1.
    - `grep -c "## Step 7 — Height Slider end-to-end smoke test" touchdesigner/VERTICAL-SLICE-RUNBOOK.md` == 1.
    - `grep -c "### Test A — Demo loop" touchdesigner/VERTICAL-SLICE-RUNBOOK.md` == 1.
    - `grep -c "### Test B — Jitter test" touchdesigner/VERTICAL-SLICE-RUNBOOK.md` == 1.
    - `grep -c "### Test C — Floor-cap test" touchdesigner/VERTICAL-SLICE-RUNBOOK.md` == 1.
    - `grep -c "GPIO 34" touchdesigner/VERTICAL-SLICE-RUNBOOK.md` >= 1.
    - `grep -c "5 floors observable" touchdesigner/VERTICAL-SLICE-RUNBOOK.md` >= 1.
    - `grep -c "no oscillation in textport" touchdesigner/VERTICAL-SLICE-RUNBOOK.md` >= 1.
    - `grep -c "## Latency measurement" touchdesigner/VERTICAL-SLICE-RUNBOOK.md` == 1 (existing section intact).
    - `grep -c "## Troubleshooting" touchdesigner/VERTICAL-SLICE-RUNBOOK.md` == 1 (existing section intact).
  </acceptance_criteria>
  <done>Runbook has explicit wiring step + three named smoke-tests (sweep / jitter / cap) with pass criteria.</done>
</task>

<task type="auto" tdd="false">
  <name>Task 2: Document new compute_state slider channels + Serial DAT storage in TD-FRAMEWORK-GUIDE.md</name>
  <files>touchdesigner/TD-FRAMEWORK-GUIDE.md</files>
  <read_first>
    - touchdesigner/TD-FRAMEWORK-GUIDE.md (node naming table at lines 9-21, Step 3 compute_state at lines 75-87, "When the ESP32 + RFID hardware arrives" at lines 187-195)
    - .planning/phases/02.1-height-slider/02.1-CONTEXT.md (TouchDesigner parsing + state aggregation blocks)
  </read_first>
  <action>
    Edit `touchdesigner/TD-FRAMEWORK-GUIDE.md`.

    1. In the Step 3 (`compute_state` Script CHOP) section, find the line "Outputs 4 channels: `puck_count`, `area_px2`, `method_id`, `hb_alive`" (currently line 83) AND the blockquote below it ("> Reads `op('vision_in')` and `op('rfid_in')` by name..."). Replace BOTH with the expanded block verbatim:

       ```
       Outputs (current canonical `vision2_state_chop.py` — see [`scripts/vision2_state_chop.py`](scripts/vision2_state_chop.py)):
       
       - **OSC-derived:** `puck_count`, `area_px2`, `area_m2`, `hb_alive`, `sketch_*`, `gesture_*`, `fsm_state`
       - **RFID-derived:** `method_id` (from `rfid_in` Serial DAT storage)
       - **Slider-derived (Phase 02.1):** `floor`, `slider_raw`, `slider_alive`
       
       > Reads `op('vision_in')` and `op('rfid_in')` by name — make sure both exist.
       > Slider channels read from `op('rfid_in').fetch('floor'|'slider_raw'|'slider_last_frame', default)`.
       > Staleness timeout: `SLIDER_TIMEOUT_TICKS = 60` frames (~2 s @ 30 fps).
       ```

    2. In the "## When the ESP32 + RFID hardware arrives" section (currently lines 187-195), AFTER step 5 (last line of the numbered list, "5. `compute_state` works with both — no script changes needed") at line 193, append a new sub-section verbatim:

       ```
       
       ### Slider (Phase 02.1)
       
       The DollaTek 10K linear-slide potentiometer is wired to the SAME ESP32-RFID board on **GPIO 34** (ADC1_CH6).
       It uses the same Serial DAT (`rfid_in`) — no second node, no second Serial port. The firmware emits two new
       line shapes alongside the existing `RFID:` / `HB:` / `BOOT:` lines:
       
       - `FLOOR:<int>` — quantized floor 1..MAX_FLOORS (firmware default 5), emitted only on change
       - `SLIDER:<0.xxx>` — smoothed normalized 0..1, emitted every ~200 ms
       
       Parsing (in `serial_rfid_v1.py`) stores each into the Serial DAT under named keys:
       
       | Storage key | Type | Set by |
       |---|---|---|
       | `method_id` | int | `RFID:` branch (existing) |
       | `floor` | int | `FLOOR:` branch (Phase 02.1) |
       | `slider_raw` | float | `SLIDER:` branch (Phase 02.1) |
       | `slider_last_frame` | int (TD frame) | `SLIDER:` branch (Phase 02.1) — used for `slider_alive` staleness |
       
       `vision2_state_chop.py` reads these via `op('rfid_in').fetch(key, default)` and surfaces three CHOP channels
       (`floor`, `slider_raw`, `slider_alive`). The HEIGHT FSM state (Phase 3) consumes `floor` directly via
       `op('compute_state')['floor'][0]`; per-method caps from `data/methods_db.json` `max_floors` decide when the
       floor-cap INVALID visual fires.
       
       ```

    Do NOT modify the architecture diagram, Steps 0-2, Step 4, Step 5, Step 6, Step 7, the testing-without-hardware section, or the adding-a-new-method section.
  </action>
  <verify>
    <automated>powershell -NoProfile -Command "$f='touchdesigner/TD-FRAMEWORK-GUIDE.md'; $c=Get-Content -Raw $f; if (-not ($c -match 'Slider-derived \(Phase 02\.1\)')) { throw 'compute_state outputs block not updated' }; if (-not ($c -match 'SLIDER_TIMEOUT_TICKS = 60')) { throw 'staleness timeout note missing' }; if (-not ($c -match '### Slider \(Phase 02\.1\)')) { throw 'Slider sub-section missing in ESP32 arrival section' }; if (-not ($c -match 'GPIO 34')) { throw 'GPIO 34 missing in framework guide' }; if (-not ($c -match '`FLOOR:<int>`')) { throw 'FLOOR line spec missing' }; if (-not ($c -match '`SLIDER:<0\.xxx>`')) { throw 'SLIDER line spec missing' }; if (-not ($c -match 'slider_last_frame')) { throw 'slider_last_frame table row missing' }; if (-not ($c -match \"op\('compute_state'\)\['floor'\]\[0\]\")) { throw 'compute_state floor consumer reference missing' }; if (-not ($c -match '## Step 3 — `compute_state` \(Script CHOP\)')) { throw 'Step 3 heading damaged' }; if (-not ($c -match '## Testing without hardware')) { throw 'Testing section damaged' }; Write-Host 'OK'"</automated>
  </verify>
  <acceptance_criteria>
    - `grep -c "Slider-derived (Phase 02.1)" touchdesigner/TD-FRAMEWORK-GUIDE.md` >= 1.
    - `grep -c "SLIDER_TIMEOUT_TICKS = 60" touchdesigner/TD-FRAMEWORK-GUIDE.md` >= 1.
    - `grep -c "### Slider (Phase 02.1)" touchdesigner/TD-FRAMEWORK-GUIDE.md` == 1.
    - `grep -c "GPIO 34" touchdesigner/TD-FRAMEWORK-GUIDE.md` >= 1.
    - `grep -c "FLOOR:<int>" touchdesigner/TD-FRAMEWORK-GUIDE.md` >= 1.
    - `grep -c "SLIDER:<0.xxx>" touchdesigner/TD-FRAMEWORK-GUIDE.md` >= 1.
    - `grep -c "slider_last_frame" touchdesigner/TD-FRAMEWORK-GUIDE.md` >= 1.
    - `grep -c "op('compute_state')\['floor'\]\[0\]" touchdesigner/TD-FRAMEWORK-GUIDE.md` >= 1.
    - `grep -c "## Step 3 — `compute_state`" touchdesigner/TD-FRAMEWORK-GUIDE.md` == 1 (heading intact).
    - `grep -c "## Testing without hardware" touchdesigner/TD-FRAMEWORK-GUIDE.md` == 1 (section intact).
  </acceptance_criteria>
  <done>Framework guide documents compute_state slider channels, Serial DAT storage keys, GPIO34 pin, and HEIGHT FSM consumer pattern.</done>
</task>

<task type="checkpoint:human-verify" gate="blocking">
  <name>Task 3: Run the three Phase 02.1 smoke tests end-to-end and confirm pass criteria (sweep + jitter + cap)</name>
  <files>touchdesigner/VERTICAL-SLICE-RUNBOOK.md</files>
  <read_first>
    - touchdesigner/VERTICAL-SLICE-RUNBOOK.md Step 7 (Phase 02.1 smoke test section added by Task 1 of this plan)
    - .planning/phases/02.1-height-slider/02.1-CONTEXT.md (Verification path block — demo loop, jitter test, cap test pass criteria)
    - .planning/phases/02.1-height-slider/02.1-01-SUMMARY.md (firmware tuning record from Plan 01)
    - .planning/phases/02.1-height-slider/02.1-02-SUMMARY.md (TD wiring record from Plan 02)
    - .planning/phases/02.1-height-slider/02.1-03-SUMMARY.md (data + contracts record from Plan 03)
  </read_first>
  <action>
    Human-verify checkpoint. Claude STOPS here and waits for the user to run the three smoke tests defined in `VERTICAL-SLICE-RUNBOOK.md` Step 7.

    Procedure for the user (mirrors `<how-to-verify>` below):

    1. Confirm Plan 01 firmware is flashed and approved (Plan 01 Task 3 checkpoint passed).
    2. Confirm all four Plan 02 TD scripts are re-pasted into their Script DAT/CHOP/TOP nodes.
    3. Confirm Plan 03 data/contracts are committed (`max_floors` in `methods_db.json`, etc.).
    4. Run Test A (slider sweep), Test B (jitter / boundary hold >=5 s), Test C (floor-cap with 3D PRINTED + MASONRY) per the runbook.
    5. Type the resume signal (`all three tests pass` or a per-test failure description).
  </action>
  <what-built>
    Full Phase 02.1 pipeline: firmware (Plan 01) + TD scripts (Plan 02) + data/contracts (Plan 03) + runbook (this plan). End-to-end: physical slider movement -> ESP32 ADC -> median+EMA+hysteresis -> Serial `FLOOR:N`/`SLIDER:0.xxx` lines -> Serial DAT storage -> compute_state channels -> stats overlay text + floor-cap visual.
  </what-built>
  <how-to-verify>
    Follow `touchdesigner/VERTICAL-SLICE-RUNBOOK.md` Step 7 verbatim. Three tests, three pass criteria:

    **Test A — Demo loop (slider sweep)**
    1. Slowly sweep slider from min to max in ~3 seconds.
    2. Confirm TD textport prints `[serial_rfid] floor=1` through `[serial_rfid] floor=5` in order.
    3. Confirm `compute_state` CHOP shows the same value on its `floor` channel within ~100 ms of each printed line.
    4. Confirm the stats overlay's `FLOOR` segment cycles from `FLOOR 1` to `FLOOR 5`.

    **Pass A:** all 5 floors observable in all 3 surfaces.

    **Test B — Jitter test (boundary hold)**
    1. Park the slider at a known floor boundary (e.g. between FLOOR:2 and FLOOR:3).
    2. Hold for >=5 seconds.
    3. Confirm ZERO additional `[serial_rfid] floor=...` lines during the hold.
    4. Confirm the compute_state `floor` channel stays at one value, no flicker.

    **Pass B:** no oscillation during the 5 s hold.

    **Test C — Floor-cap test (per-method INVALID)**
    1. Scan the 3D PRINTED RFID tag. Confirm `METHOD 3D PRINTED` in the stats overlay and `method_id=2` in the textport.
    2. Slide above floor 1 (so floor reaches 2..5).
    3. Confirm the `method_selection` panel gets a **red border + diagonal red X** overlay.
    4. Slide back to floor 1. Confirm the red overlay disappears.
    5. Scan MASONRY tag (cap=5). Sweep through all 5 floors. Confirm NO red overlay appears.

    **Pass C:** red border + X appears exactly when `floor > max_floors[method_id]`, disappears otherwise.

    **If any test fails:** note which surface (textport / CHOP / stats overlay / render_footprint) was wrong, screenshot if useful, and describe the symptom. We will diagnose and update the relevant plan (most likely Plan 01 hysteresis tuning or Plan 02 fetch wiring).
  </how-to-verify>
  <verify>
    Human verification (no automated command — this is a hardware-in-loop check). The user runs Tests A/B/C from `VERTICAL-SLICE-RUNBOOK.md` Step 7 and confirms all three pass criteria.
  </verify>
  <acceptance_criteria>
    - User confirms Pass A: all 5 floors (FLOOR:1..FLOOR:5) observable across textport + CHOP + stats overlay during one sweep.
    - User confirms Pass B: holding slider at a boundary for >=5 s yields ZERO additional FLOOR lines and the `floor` channel does NOT flicker.
    - User confirms Pass C: with 3D PRINTED (cap=1), red border + X appears when floor > 1 and disappears when floor returns to 1; with MASONRY (cap=5), red border + X NEVER appears.
    - Measured slider->overlay latency < 100 ms (per the runbook's Test A pass criterion).
  </acceptance_criteria>
  <done>User types `all three tests pass` (Phase 02.1 closed) OR provides per-test failure descriptions that become inputs for `/gsd:plan-phase 02.1 --gaps`.</done>
  <resume-signal>Type "all three tests pass" to close Phase 02.1. Otherwise type "Test {A|B|C} failed: {symptom}" so the failure can be turned into a gap-closure plan (`/gsd:plan-phase 02.1 --gaps`).</resume-signal>
</task>

</tasks>

<verification>
- Both updated docs contain the strings asserted in acceptance_criteria.
- VERTICAL-SLICE-RUNBOOK.md Step 7 covers all three CONTEXT.md verification-path scenarios (demo loop, jitter test, cap test).
- TD-FRAMEWORK-GUIDE.md compute_state Step 3 lists the three new slider channels.
- Smoke test executes end-to-end with all 3 pass criteria met (final checkpoint).
</verification>

<success_criteria>
- ROADMAP Phase 02.1 success criterion #6 satisfied (demo path proven end-to-end within 100 ms, no jitter at boundaries).
- Smoke-test runbook is reproducible by any team member without additional context.
- Phase 02.1 ready to close — STATE.md gets a "Phase 02.1 complete" line in the SUMMARY for this plan.
</success_criteria>

<output>
After completion, create `.planning/phases/02.1-height-slider/02.1-04-SUMMARY.md` per the standard template, documenting: smoke-test results (pass/fail per test A/B/C), any firmware tuning deviations (`EMA_ALPHA` / `HYST_EPSILON` adjustments observed during jitter test), measured slider->overlay latency, and a one-line phase-close note for STATE.md.
</output>

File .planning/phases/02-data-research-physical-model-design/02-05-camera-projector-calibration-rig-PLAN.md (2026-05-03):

---
phase: 2
plan: 05
title: Camera-projector calibration rig + RECALIBRATE.md runbook
owner: _TBD_
wave: 1
depends_on: []
files_modified:
  - vision/calibration/checkerboard_9x6_25mm.pdf
  - vision/calibration/aruco_board_5x7_DICT_4X4_50.pdf
  - vision/calibration/RECALIBRATE.md
  - vision/calibration/camera_intrinsics.yml
  - vision/calibration/projector_camera_homography.yml
  - vision/src/calibrate_camera.py
  - vision/src/calibrate_projector_homography.py
  - vision/pyproject.toml
  - vision/README.md
autonomous: false
requirements:
  - INP-01
  - INP-03
estimated_effort_hours: 8
---

<objective>
Build the camera-projector calibration rig that Plan 07 (one-puck closed-loop CV vertical slice) depends on. The rig produces TWO outputs: (a) `camera_intrinsics.yml` — the OpenCV camera matrix + distortion coefficients from a checkerboard calibration; (b) `projector_camera_homography.yml` — a 3×3 homography matrix that maps detected ArUco pixel coordinates in the camera frame to projector-output pixel coordinates, so the projector can paint accurately on top of any ArUco-detected puck. Both outputs are version-controlled YAML so the team can re-calibrate without re-deriving from scratch. The plan ALSO produces `RECALIBRATE.md`, a runbook any team member can follow in <30 min to re-run the calibration after a camera/projector nudge — a non-negotiable Phase 2 success criterion (ROADMAP item 3). Per locked decision #1 (closed-loop CV from day one) and lit-review strand 03's explicit warning ("calibration drift is the demo-day failure mode of this whole literature"), this plan is the single highest-leverage engineering task in Phase 2. It addresses INP-01 (sensor/webcam streaming into runtime — here, into TouchDesigner via the published intrinsics) and INP-03 (input triggers correct FSM transitions in real time — here by establishing the coordinate-system bridge that makes "puck position → projected target zone comparison" tractable in Plan 07). Per the realignment note: INP-01 was originally framed as "via Firefly" — the SPIRIT (sensor pipeline streaming to runtime) is preserved using the new TouchDesigner stack via OpenCV/OSC.

**Cross-plan ordering note (BLOCKER fix from checker iter 1):** This plan was originally Wave 1 with `depends_on: []`, but Task 5.2 originally generated BOTH the checkerboard PDF (dictionary-agnostic) AND the ArUco-board PDF (which hard-codes the ArUco dictionary). Plan 02-03's Task 3.1 — the checkpoint:decision that locks the ArUco dictionary — also runs in Wave 1, creating a race condition: if the team picks a non-default dictionary in Plan 03, the calibration board PDF would have the wrong dictionary and would be incompatible with the puck markers used in Plan 07. **Fix applied (Option C):** Task 5.2 has been split. Task 5.2a (checkerboard PDF — dictionary-agnostic) runs immediately. Task 5.2b (ArUco-board PDF — dictionary-dependent) has an explicit sentinel pre-check that REFUSES to run until `cad/PUCK-SPEC.md` exists with a locked Dictionary value (i.e. until Plan 02-03 Task 3.1+3.2 have shipped). This keeps the rest of Plan 05 (intrinsics calibration, runbook scaffolding) unblocked in Wave 1 while preventing the race.
</objective>

<must_haves>
- `vision/pyproject.toml` (or `requirements.txt`) pins the OpenCV + numpy versions used. Anyone running calibration uses the same versions.
- A printed checkerboard PDF exists in `vision/calibration/checkerboard_9x6_25mm.pdf` ready to be physically printed at A4 / Letter at 100% scale (no "fit to page"). **Dictionary-agnostic — produced in Wave 1 immediately by Task 5.2a.**
- A printed ArUco-board PDF exists in `vision/calibration/aruco_board_5x7_DICT_4X4_50.pdf` (or the dict chosen in Plan 03) for projector-camera homography calibration. **Dictionary-dependent — produced by Task 5.2b ONLY AFTER Plan 02-03's `cad/PUCK-SPEC.md` is committed and lists a locked Dictionary value.**
- `vision/src/calibrate_camera.py` runs and produces `vision/calibration/camera_intrinsics.yml` (camera matrix + distortion coefficients) given ≥ 10 captured frames of the checkerboard. **Dictionary-agnostic — fully unblocked in Wave 1.**
- `vision/src/calibrate_projector_homography.py` runs and produces `vision/calibration/projector_camera_homography.yml` given a captured frame where the projector displays a known ArUco-board pattern that the camera sees. **Dictionary-dependent — script can be authored in Wave 1 with the dictionary value read from PUCK-SPEC.md at run time, but actual physical homography calibration in Task 5.6 still requires the printed ArUco board from 5.2b.**
- `vision/calibration/RECALIBRATE.md` runbook exists. A team member who has never run calibration can follow it end-to-end in < 30 minutes (verified by Task 5.6 checkpoint).
- The calibration outputs are non-empty YAML files with the exact keys `camera_matrix`, `dist_coeffs` (intrinsics) and `homography`, `image_size_camera`, `image_size_projector` (homography file).
- Both YAML files include a metadata header: `calibrated_at: <ISO date>`, `calibrated_by: <NAME>`, `camera_model: <e.g. Logitech C920>`, `projector_model: <e.g. Epson EH-TW650>`, `mounting_notes: <e.g. "camera 95 cm above table, projector 110 cm above offset 15 cm to the left">` so a future re-calibration knows what physical setup the YAML was produced from.
- `vision/README.md` is updated to document where the calibration files live and that any vision pipeline reads them.
</must_haves>

<tasks>

<task type="auto">
  <name>Task 5.1: Write vision/pyproject.toml + install dependencies</name>
  <action>Create `vision/pyproject.toml` with these pinned versions (chosen for stability — these are the versions every team member installs):

  ```toml
  [project]
  name = "vision"
  version = "0.1.0"
  description = "Camera input, ArUco detection, calibration for the IAAC tabletop installation"
  requires-python = ">=3.11"
  dependencies = [
      "opencv-contrib-python==4.10.0.84",
      "numpy==1.26.4",
      "python-osc==1.8.3",
      "pyyaml==6.0.2",
      "reportlab==4.2.5",
  ]

  [project.optional-dependencies]
  dev = [
      "pytest==8.3.3",
  ]

  [build-system]
  requires = ["setuptools>=68"]
  build-backend = "setuptools.build_meta"

  [tool.setuptools]
  packages = ["src"]
  ```

  IMPORTANT: use `opencv-contrib-python` (NOT `opencv-python`) because `cv2.aruco` lives in the contrib package only.

  After writing the file, install in a virtualenv (the script-run owner does this — it's not a Claude action per se, but document the steps in `vision/README.md` Task 5.7):

  ```
  cd vision
  python -m venv .venv
  # Windows: .venv\Scripts\activate
  # macOS/Linux: source .venv/bin/activate
  pip install -e ".[dev]"
  python -c "import cv2; print(cv2.__version__); import cv2.aruco; print('aruco ok')"
  ```

  The last line MUST print `4.10.0` and `aruco ok` — that's the smoke test that opencv-contrib is installed correctly.</action>
  <read_first>
    - vision/README.md (current contents — for the suggested layout convention)
    - .planning/phases/02-data-research-physical-model-design/02-CONTEXT.md "Claude's Discretion: Vision pipeline location"
  </read_first>
  <acceptance_criteria>
    - `vision/pyproject.toml` exists.
    - File pins `opencv-contrib-python==4.10.0.84` (NOT `opencv-python`).
    - File pins `numpy`, `python-osc`, `pyyaml`, `reportlab` with version specifiers.
    - File specifies `requires-python = ">=3.11"`.
  </acceptance_criteria>
</task>

<task type="auto">
  <name>Task 5.2a: Generate the checkerboard PDF for camera intrinsics (DICTIONARY-AGNOSTIC — runs in Wave 1)</name>
  <action>Create `vision/src/generate_calibration_targets.py`. In THIS task, implement ONLY the checkerboard generator. The ArUco-board generator is added in Task 5.2b after Plan 02-03 ships PUCK-SPEC.md with the locked dictionary.

  Generator: `vision/calibration/checkerboard_9x6_25mm.pdf` — standard OpenCV calibration checkerboard, 9 inner corners horizontal × 6 inner corners vertical (so 10 × 7 squares total), 25 mm square size. Print at 100% scale on A4 or Letter — fits with margins. Add a footer "Print at 100% — do NOT fit-to-page. Square size = 25 mm. Verify by measuring after printing." After printing, the user measures one square with a ruler; if it's not 25 mm exactly, the calibration accuracy will be off by that ratio — document in RECALIBRATE.md.

  Use this skeleton (Wave 1 — checkerboard only; the ArUco board function will be appended in Task 5.2b):

  ```python
  """Generate printable calibration targets per RECALIBRATE.md.

  Wave 1 (Task 5.2a): checkerboard only — dictionary-agnostic.
  Wave 2 (Task 5.2b): ArUco board + projector pattern PNG appended once
                      cad/PUCK-SPEC.md exists with the locked dictionary value.
  """
  from reportlab.lib.pagesizes import A4
  from reportlab.pdfgen import canvas
  from reportlab.lib.units import mm

  # ----- Checkerboard (DICTIONARY-AGNOSTIC) -----
  COLS, ROWS = 10, 7  # squares (so inner corners = 9, 6)
  SQUARE_MM = 25.0

  def render_checkerboard_pdf(path):
      c = canvas.Canvas(path, pagesize=A4)
      origin_x = (A4[0] - COLS * SQUARE_MM * mm) / 2
      origin_y = (A4[1] - ROWS * SQUARE_MM * mm) / 2
      for r in range(ROWS):
          for col in range(COLS):
              if (r + col) % 2 == 0:
                  c.setFillColorRGB(0, 0, 0)
              else:
                  c.setFillColorRGB(1, 1, 1)
              c.rect(origin_x + col * SQUARE_MM * mm,
                     origin_y + r * SQUARE_MM * mm,
                     SQUARE_MM * mm,
                     SQUARE_MM * mm,
                     stroke=0, fill=1)
      c.setFillColorRGB(0, 0, 0)
      c.setFont("Helvetica", 10)
      c.drawString(20 * mm, 15 * mm,
                   "Print at 100% scale (NOT fit-to-page). Each square = 25 mm. Measure to verify.")
      c.save()

  if __name__ == "__main__":
      render_checkerboard_pdf("vision/calibration/checkerboard_9x6_25mm.pdf")
      print("checkerboard PDF written")
      print("NOTE: ArUco board PDF + projector pattern PNG are produced by Task 5.2b once cad/PUCK-SPEC.md exists.")
  ```

  Run the script. Confirm the PDF exists and visually preview it (open in any PDF viewer). The checkerboard should be black/white squares.</action>
  <read_first>
    - vision/pyproject.toml (Task 5.1)
  </read_first>
  <acceptance_criteria>
    - `vision/src/generate_calibration_targets.py` exists with `render_checkerboard_pdf` function.
    - Script runs without error in the pinned environment.
    - `vision/calibration/checkerboard_9x6_25mm.pdf` exists, file size > 5 KB (real PDF, not empty).
    - Visual verification: open PDF — checkerboard shows ~10×7 squares.
    - Script does NOT yet import `cv2.aruco` or generate any ArUco-dependent artifacts (those land in Task 5.2b).
  </acceptance_criteria>
</task>

<task type="auto">
  <name>Task 5.2b: Generate ArUco-board PDF + projector pattern PNG (DICTIONARY-DEPENDENT — gated by sentinel check on cad/PUCK-SPEC.md)</name>
  <sentinel_pre_check>
    **DO NOT START this task until ALL of the following are TRUE:**
    1. `cad/PUCK-SPEC.md` exists in the working tree (Plan 02-03 Task 3.2 output).
    2. `cad/PUCK-SPEC.md` contains an "## ArUco marker" section with a literal Dictionary value spelled out as `DICT_4X4_50` OR `DICT_5X5_100` OR `DICT_6X6_250` (Plan 02-03 Task 3.1 decision locked).
    3. The Dictionary value is NOT a placeholder like `<DICT_4X4_50 / DICT_5X5_100 / DICT_6X6_250>` — it must be one literal value.

    **Runtime sentinel check (executor MUST run this before any other action in this task):**

    ```bash
    # Verify PUCK-SPEC.md exists and has a locked dictionary
    test -f cad/PUCK-SPEC.md || { echo "BLOCKED: cad/PUCK-SPEC.md does not exist — Plan 02-03 Task 3.2 must ship first"; exit 1; }
    DICT=$(grep -E "^\| Dictionary \| (DICT_[0-9]+X[0-9]+_[0-9]+)" cad/PUCK-SPEC.md | head -1 | awk -F'| ' '{print $3}' | awk '{print $1}')
    if [ -z "$DICT" ] || echo "$DICT" | grep -q "/"; then
      echo "BLOCKED: cad/PUCK-SPEC.md does not contain a single locked Dictionary value (found: '$DICT')"
      echo "Plan 02-03 Task 3.1 (checkpoint:decision) must be resolved first."
      exit 1
    fi
    echo "OK: locked dictionary is $DICT"
    ```

    If the sentinel check FAILS, STOP. Notify the executor that Plan 02-03 must complete Task 3.1 + Task 3.2 first. Do NOT proceed with hardcoded fallbacks.
  </sentinel_pre_check>
  <action>After the sentinel passes, read the locked dictionary from `cad/PUCK-SPEC.md` and APPEND two new functions to `vision/src/generate_calibration_targets.py`:

  1. `render_aruco_board_pdf(path, dict_name)`: ArUco grid board, 5 markers wide × 7 markers tall, marker side = 30 mm, marker separation = 10 mm. Use OpenCV's `cv2.aruco.GridBoard` — uses IDs 15..49 from the dictionary (offset to avoid colliding with puck IDs 0–14 reserved in `cad/PUCK-SPEC.md`). Render to PDF.

  2. `render_projector_pattern_png(path, dict_name)`: 1280×720 PNG with 4 ArUco markers (IDs 45, 46, 47, 48) at corners (200,200), (1080,200), (1080,520), (200,520) for the projector-camera homography step.

  Append (do NOT replace the Wave-1 checkerboard function):

  ```python
  # ----- ArUco board + projector pattern (DICTIONARY-DEPENDENT) -----
  # Added in Task 5.2b after sentinel check on cad/PUCK-SPEC.md.
  import os
  import re
  import cv2
  import numpy as np

  BOARD_COLS, BOARD_ROWS = 5, 7
  MARKER_MM = 30.0
  SEPARATION_MM = 10.0
  ID_OFFSET = 15  # IDs 0–14 reserved for pucks per PUCK-SPEC.md

  PROJECTOR_RESOLUTION = (1280, 720)
  CORNER_OFFSETS = [(200, 200), (1080, 200), (1080, 520), (200, 520)]
  CORNER_IDS = [45, 46, 47, 48]
  CORNER_MARKER_PX = 120

  def read_locked_dictionary(puck_spec_path="cad/PUCK-SPEC.md"):
      """Parse the Dictionary value from cad/PUCK-SPEC.md. Refuses placeholders."""
      with open(puck_spec_path) as f:
          text = f.read()
      m = re.search(r"^\|\s*Dictionary\s*\|\s*(DICT_\d+X\d+_\d+)\b", text, re.MULTILINE)
      if not m:
          raise RuntimeError(
              f"{puck_spec_path} does not contain a single locked Dictionary value. "
              "Plan 02-03 Task 3.1 (checkpoint:decision) must resolve first."
          )
      return m.group(1)

  def render_aruco_board_pdf(path, dict_name):
      d = cv2.aruco.getPredefinedDictionary(getattr(cv2.aruco, dict_name))
      board = cv2.aruco.GridBoard(
          (BOARD_COLS, BOARD_ROWS),
          MARKER_MM / 1000.0,
          SEPARATION_MM / 1000.0,
          d,
          ids=np.arange(ID_OFFSET, ID_OFFSET + BOARD_COLS * BOARD_ROWS, dtype=np.int32),
      )
      width_px = int((BOARD_COLS * MARKER_MM + (BOARD_COLS - 1) * SEPARATION_MM) * 10)
      height_px = int((BOARD_ROWS * MARKER_MM + (BOARD_ROWS - 1) * SEPARATION_MM) * 10)
      img = board.generateImage((width_px, height_px), marginSize=20)
      png_path = path.replace(".pdf", ".png")
      cv2.imwrite(png_path, img)
      c = canvas.Canvas(path, pagesize=A4)
      width_mm_v = BOARD_COLS * MARKER_MM + (BOARD_COLS - 1) * SEPARATION_MM
      height_mm_v = BOARD_ROWS * MARKER_MM + (BOARD_ROWS - 1) * SEPARATION_MM
      origin_x = (A4[0] - width_mm_v * mm) / 2
      origin_y = (A4[1] - height_mm_v * mm) / 2
      c.drawImage(png_path, origin_x, origin_y, width=width_mm_v * mm, height=height_mm_v * mm)
      c.setFont("Helvetica", 10)
      c.drawString(20 * mm, 15 * mm,
                   f"Print at 100%. Marker side = {MARKER_MM} mm. Separation = {SEPARATION_MM} mm. Dict={dict_name}.")
      c.save()

  def render_projector_pattern_png(path, dict_name):
      d = cv2.aruco.getPredefinedDictionary(getattr(cv2.aruco, dict_name))
      img = np.ones((PROJECTOR_RESOLUTION[1], PROJECTOR_RESOLUTION[0]), dtype=np.uint8) * 255
      for (x, y), mid in zip(CORNER_OFFSETS, CORNER_IDS):
          marker = cv2.aruco.generateImageMarker(d, mid, CORNER_MARKER_PX)
          half = CORNER_MARKER_PX // 2
          img[y - half:y + half, x - half:x + half] = marker
      cv2.imwrite(path, img)

  if __name__ == "__main__" and os.environ.get("RUN_ARUCO", "0") == "1":
      DICT = read_locked_dictionary()
      pdf_path = f"vision/calibration/aruco_board_5x7_{DICT}.pdf"
      png_path = "vision/calibration/projector_pattern_4markers.png"
      render_aruco_board_pdf(pdf_path, DICT)
      render_projector_pattern_png(png_path, DICT)
      print(f"wrote {pdf_path} and {png_path} (dict={DICT})")
  ```

  Run with `RUN_ARUCO=1 python vision/src/generate_calibration_targets.py`. The script will:
  1. Re-emit the checkerboard PDF (idempotent — no harm).
  2. Read `cad/PUCK-SPEC.md` for the locked dictionary.
  3. Generate `vision/calibration/aruco_board_5x7_<DICT>.pdf` (filename embeds the actual dictionary).
  4. Generate `vision/calibration/projector_pattern_4markers.png` at 1280×720.
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

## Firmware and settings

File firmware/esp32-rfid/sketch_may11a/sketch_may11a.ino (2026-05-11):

// Hardware III — RFID method selector
//
// ESP32 + MFRC522 RFID reader + MIFARE Classic 1K (S50) tags.
// Reads tag UID, prints "RFID:<HEX>" over USB serial @ 115200 baud.
// TouchDesigner Serial DAT (rfid_in) parses these lines.
//
// Hardware:
//   RC522 SDA  -> GPIO 5   (SS)
//   RC522 SCK  -> GPIO 18
//   RC522 MOSI -> GPIO 23
//   RC522 MISO -> GPIO 19
//   RC522 RST  -> GPIO 27
//   RC522 3.3V -> 3V3      (NOT 5V — RC522 is 3.3V only)
//   RC522 GND  -> GND
//
// Library: install "MFRC522" by GithubCommunity from Library Manager.

#include <SPI.h>
#include <MFRC522.h>

constexpr uint8_t SS_PIN  = 5;
constexpr uint8_t RST_PIN = 27;

MFRC522 rfid(SS_PIN, RST_PIN);

// Debounce: ignore re-reads of the same tag for this many ms.
constexpr unsigned long REREAD_MS = 1500;

String   lastUid     = "";
unsigned long lastReadMs = 0;

void setup() {
  Serial.begin(115200);
  while (!Serial && millis() < 2000) {}  // wait briefly for USB CDC
  SPI.begin();
  rfid.PCD_Init();
  Serial.println("BOOT:rfid_reader_ready");
}

void loop() {
  // Heartbeat every second so TD can see we're alive even with no tag.
  static unsigned long lastHb = 0;
  unsigned long now = millis();
  if (now - lastHb >= 1000) {
    lastHb = now;
    Serial.print("HB:");
    Serial.println(now / 1000);
  }

  if (!rfid.PICC_IsNewCardPresent()) return;
  if (!rfid.PICC_ReadCardSerial())   return;

  String uid = "";
  for (byte i = 0; i < rfid.uid.size; i++) {
    if (rfid.uid.uidByte[i] < 0x10) uid += "0";
    uid += String(rfid.uid.uidByte[i], HEX);
  }
  uid.toUpperCase();

  if (uid != lastUid || (now - lastReadMs) > REREAD_MS) {
    Serial.print("RFID:");
    Serial.println(uid);
    lastUid     = uid;
    lastReadMs  = now;
  }

  rfid.PICC_HaltA();
  rfid.PCD_StopCrypto1();
}

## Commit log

2026-04-10 Initial commit: Hardware III course structure
    Folder structure, syllabus PDF, and reference notes for
    IAAC Hardware III — Human-in-the-Loop Interactive Systems.
2026-04-10 Add GSD planning structure for Hardware III course
    Initializes .planning/ with PROJECT.md, REQUIREMENTS.md, ROADMAP.md,
    STATE.md, and config.json based on Session 1 course slides.
    6 phases mapped to course schedule (April 10 – May 22, 2026).
2026-04-10 Update project concept: physical replica + projection mapping + layered data
    Core concept locked: scale model placed on table, projector maps directly
    onto 3D surface showing CO2 emissions, provenance, historical facts + sound.
    Camera/Kinect detects placement and orientation. ESP32 for additional sensing.
    FSM states correspond to information layers.
2026-04-10 Finalize concept: guided comparative construction assembly installation
    User assembles 2-4 physical models (traditional/3D-print/modular/vernacular)
    step by step on table. Projection guides placement, reveals CO2 + labor data
    per piece. Final comparison statistics after all models complete.
    FSM: IDLE -> GUIDING -> CHECKING -> CONFIRMED -> NEXT_PIECE -> MODEL_COMPLETE
    -> NEXT_MODEL -> COMPARISON
2026-04-17 docs: add full technical specification
    TouchDesigner + ESP32 WiFi/OSC + RFID + ArUco pipeline.
    Covers hardware list, ArUco generation + X1C printing, RFID wiring,
    ESP32 firmware, TouchDesigner node network, FSM, libraries, setup order.
2026-04-17 docs: add submitted proposal PDF and lock FSM/phases from slides
    - Add Group_3_Hardware_III_Proposal.pdf (S1 submission)
    - Update PROJECT.md: rename to "Guided Comparative Assembly", update FSM to
    IDLE→METHOD→FOOTPRINT→HEIGHT→MATERIALS→VALIDATED→5 PHASES→COMPARISON
    - Lock 5 building phases: Foundation, Structure, Roof, Openings, Finishing
    - Note "no screens, no buttons" design principle
2026-05-03 scaffold: project file structure for hardware/software/data work
    Adds top-level folders so each subsystem has a home before we start
    building. Each folder includes a README explaining scope, suggested
    layout, and conventions:
    - firmware/ ESP, RFID, OSC protocol
    - touchdesigner/ primary runtime, .toe files
    - vision/ camera + ArUco + YOLO (Python)
    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
2026-05-03 research(lit-review): 6-strand literature review + locked decisions
    Adds a literature review under docs/research/lit-review/ produced by
    a 6-agent research pipeline (Claude / deep-research skill, 2026-05-03)
    plus a derived action plan and the four locked project decisions in
    CONTRIBUTING.md.
    Strand reports (each ~1-2k words, every claim cited):
    01-tui-tabletops.md
    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
2026-05-03 plan: realign .planning/ with current reality + locked decisions
    Realigns PROJECT.md, STATE.md, ROADMAP.md so /gsd-plan-phase has a
    correct baseline. Three categories of drift fixed:
    1. Phase 1 was marked Pending — now ✅ Complete (proposal submitted
    April 17, file is on master).
    2. Toolkit was Anemone (FSM) + Firefly (vision) + Grasshopper. Locked
    2026-05-03 to TouchDesigner per lit-review strand 03 (Anemone is
    single-threaded and stalls the canvas under projector light).
    Updated PROJECT.md Toolkit section + Phase 3 Goal/Success criteria.
    3. Locked decisions from docs/research/lit-review/ACTIONS.md were not
    yet reflected in .planning/. Added across PROJECT.md, STATE.md,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
2026-05-03 plan(02): 8 PLAN.md files via /gsd-plan-phase + planner/checker loop
    Generated by gsd-planner (opus) and verified by gsd-plan-checker (sonnet)
    through one revision iteration. Final state: 1 BLOCKER + 3 WARNINGS
    identified by initial check, all resolved in revision 1, second check
    returned VERIFICATION PASSED.
    Phase 2 critical path:
    Wave 1 (parallel, 6 plans):
    02-01 Slide-deck reference corrections (1h) → SC-07
    02-02 LCA data sourcing — 4 tier-annotated CSVs (10h) → INP-02
    02-03 ArUco pucks fabrication — design + 3 prints (5h) → MOD-01..04
    02-04 Method-selector models in Rhino (4h) → MOD-01, MOD-04
    02-05 Camera-projector calibration rig (8h)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
2026-05-04 feat(td-fsm): implement TouchDesigner FSM logic + CV pipeline for Phase 2+3
    Vision pipeline (outside TD):
    - vision/src/aruco_detect.py — ArUco detection + camera→projector homography
    - vision/src/osc_send.py — OSC sender (protocol: /puck/detected, /puck/lost, /vision/heartbeat)
    - vision/src/run_vertical_slice.py — CLI entry point, --dry-run flag for hardware-blocked fallback
    - vision/src/generate_synthetic_calibration.py — synthetic YAML generator per Plan 02-07 contingency
    - vision/calibration/TOLERANCE.md + tolerance_loader.py — tolerance spec (30px fallback, measure after rig)
    TouchDesigner logic (Script DATs/CHOPs):
    - touchdesigner/scripts/osc_handler.py — par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
2026-05-04 research(02): 7 deep-research strands + earn-the-data inventory
    7 parallel deep-research strands dispatched across this session, all primary-source verified:
    Strands 01-06 (English-dominant academic + EPD + open-government):
    01 Masonry — 11 sources, 25 cells (15 populated), Hispalyt EPDs anchored
    02 3D-printed — 17 sources, 34 rows, triangulation-rule-disciplined T3 removal
    03 Prefab — 14 sources, 33 rows, sub_method column for modular vs CLT
    04 Reclaimed brick — 12 sources, 25 cells with allocation_rule column
    05 Animations + gesture — 22 sources across 4 sub-strands (gesture pipeline,
    AI animation, methodology-wobble viz, tabletop precedents)
    06 Gap-filling —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
2026-05-04 Update ESP32 documentation with latest project requirements
    - Updated overview to reflect IDLE → ONBOARDING transition (not just zoom)
    - Added user absence detection and timeout logic (30s threshold)
    - Integrated sound cueing system specification with FSM state mapping
    - Enhanced OSC protocol with /proximity/presence and /esp32/state_trigger messages
    - Added 6.3 section for user absence timeout tuning
    - Expanded calibration procedures with detailed proximity ranges
    - Added Section 11: comprehensive demo operation runbook with setup/run/shutdown steps
    - Added fallback procedures for WiFi drops, RFID failures, and sensor issues
    - Expanded QA checklist to 5 subsections (hardware, firmware, in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
2026-05-04 feat: TD framework v5 — RFID input, polygon fill, state CHOP, methods DB
    - footprint_viz_v5.py: polygon fill (ray-cast), per-method colors,
    pucks sorted by centroid angle for correct convex outline, reads
    method_id from state1 CHOP
    - state_chop_v1.py: aggregates puck_count, area_px2, method_id,
    hb_alive into one CHOP; reads serial1 DAT for RFID method
    - serial_rfid_v1.py: Serial DAT callbacks for ESP32/RFID — maps
    tag IDs to method indices, stores on DAT for state CHOP
    - data/methods_db.json: 5-method reference DB (none, cantilever,
    column grid, arch, truss) with colors + RFID tag fields
    - TD-FRAMEWORK-GUIDE.md: step-by-step guide to wire the full
    network in TD (oscin1 → st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
2026-05-04 refactor: short logical TD node names + archive old scripts
    Node naming convention (what it does, not what type it is):
    osc, rfid, state, viz, stats, comp, out
    - footprint_viz_v5.py: op references updated (oscin1→osc, state1→state)
    - state_chop_v1.py: op references updated (oscin1→osc, serial1→rfid)
    - TD-FRAMEWORK-GUIDE.md: rewritten with new node name table + convention
    - scripts/archive/: old versioned scripts moved out of the way
2026-05-04 refactor: descriptive TD node names + RFID stub via Constant CHOP
    Node naming convention now describes what each node does:
    cam → vision_in (OSC from CV pipeline)
    (new) → rfid_in (stub: Constant CHOP, real: Serial DAT later)
    state → compute_state (Script CHOP aggregator)
    viz → render_footprint(Script TOP)
    stats → stats_text (Text TOP)
    comp → compose_final (Over TOP)
    out → projector_out (Window COMP)
    state_chop_v1.py now reads rfid_in either as CHOP channel
    (stub mode, no hardware) or via .fetch (real Serial DAT mode).
    No script changes needed when hardware arrives — just swap
    the Constant CHOP f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
2026-05-10 data(p6): LCA CSVs + methods_db + task log + presentation
    - data/methods/{masonry,3d-printed,prefab,reclaimed-brick}.csv — 4 sourced LCA datasets, phase × parameter × range × source_tier
    - data/methods_db.json — corrected method names (was Cantilever/Arch/Truss), real CO2/labour/time/cost ranges, 4 descriptions, 5 phase texts, final comparison insight
    - .planning/phases/rafik-data-tasks.md — 14-task decision log, all resolved
    - deliverables/Person6_Role_Fulfillment.pptx — 13-slide role summary + strength assessment
    - scripts/make_presentation.py — python-pptx generation script
    [3d-printed.csv, masonry.csv, prefab.csv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]
2026-05-10 feat(firmware): ESP32 RC522 RFID reader sketch + align methods to project (3 methods, no reclaimed)
    firmware/esp32-rfid/
    esp32_rfid.ino — Arduino sketch: reads MIFARE 1K UIDs, prints
    'RFID:<HEX>' over USB serial @ 115200 + 1Hz heartbeat
    README.md — wiring, library install, flash instructions, test guide
    Aligned methods to actual project scope (Masonry · 3D Printed · Prefab):
    - methods_db.json: full rewrite, 3 methods + NONE, color codes,
    references to docs/research_2/*/VALUES.md as source of truth for LCA
    - footprint_viz_v5.py: METHOD_COLORS / METHOD_NAMES use correct methods
    - serial_rfid_v1.py: cleared bogus tag mapping, ready for real UIDs
    The prev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
2026-05-11 feat(viz): auto-blit text TOPs into panel positions
    Eliminates the manual Over TOP + Translate workflow that was tedious
    and error-prone for the 7-panel UI.
    footprint_viz_v5.py now reads any Text TOP named text_<panel_id> via
    .numpyArray() and composites it directly into the corresponding panel
    rectangle. Pixel-precise positioning lives in the Python script's
    PANELS dict — one source of truth.
    User workflow per text panel (down from N steps to 4):
    1. Add Text TOP
    2. Rename to text_<panel_id>
    3. Set Resolution to panel size
    4. Write text or expression
    The Script TOP picks it up automatically — no compose_final, no Over
    chain, no normalized translate math.
    PANEL-LAYOUT-GUIDE.md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
2026-05-11 feat(td): align scripts to methods_db.json + add lca_data_reader
    footprint_viz_v5.py:
    - METHOD_COLORS now matches data/methods_db.json exactly
    (PREFAB: yellow→green, 3D PRINTED: cyan→steel blue, MASONRY: adjusted)
    - Added method_id 4 RECLAIMED BRICK to both colors and names
    serial_rfid_v1.py:
    - Filled RFID_TO_METHOD with placeholder tags from methods_db.json
    (A1B2C3D4 MASONRY, E5F6A7B8 3D PRINTED, C9D0E1F2 PREFAB,
    A3B4C5D6 RECLAIMED BRICK) — Person 7 replaces with real UIDs
    - Added method_id 4 RECLAIMED BRICK to METHOD_NAMES
    state_chop_v1.py:
    - Fixed stale comment (cantilever/column_grid/arch/truss →
    masonry/3d_printed/prefab/reclaimed_brick)
    lca_data_re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
2026-05-11 docs(firmware): comprehensive lab walkthrough for ESP32+RC522 setup
    Self-contained guide for in-the-lab work:
    - hardware checklist + USB cable warning (data vs charge-only)
    - wiring table + ASCII diagram + recommended wire colors
    - Arduino IDE one-time setup (board support + library)
    - flash procedure with BOOT-button workaround
    - serial monitor test before TD integration
    - UID registration workflow (notebook table to fill in)
    - TD integration steps once hardware works
    - troubleshooting table (8 common problems)
    - printable pin map at the end
    User is heading to the electronics lab — this lets them work
    without screen access to the chat.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
2026-05-11 fix(td): state_chop reads method_id from vision OSC fallback
    When rfid_in gives 0 (no RFID pedestal), state_chop now reads
    vision/method/id:0 from the existing vision_in OSC In CHOP.
    vision/main.py sends /method/id on the same port 7000 whenever
    an ArUco method token (20=MASONRY, 21=3D PRINTED, 22=PREFAB) is
    visible on the table.
    Priority: rfid_in (non-zero) > vision /method/id > 0 (none)
    No new TD nodes required — uses the existing vision_in CHOP.
2026-05-11 feat(metrics): add normalized data pipeline
    [3d-printed.csv, masonry.csv, prefab.csv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]
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2026-05-11 fix: full audit remediation — vision stability + TD correctness + cleanup
    CRITICAL / HIGH fixes
    ─────────────────────
    vision/gestures.py
    - 3-frame grace period on hand disappearance: single occluded frame
    no longer resets dwell timer (key fix for bright installation env)
    - MediaPipe timestamp now uses elapsed ms from _t0, not wall-clock epoch
    - Model download wraps in try/except; partial file deleted on failure
    vision/working_plane.py
    - corner_pixels only set when findHomography returns non-None H
    (prevents bad pose data from collinear/degenerate marker config)
    - Upgraded DICT_4X4_50 → DICT_4X4_100 for lower false-positive rate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
2026-05-11 revert: keep DICT_4X4_50 — markers already printed
2026-05-11 fix(vision): remove duplicate legacy _send_to_td — VisionBridge is the sole OSC sender
    osc_bridge.VisionBridge already sends /puck/N, /vision/heartbeat,
    /method/selected (superset of the old _send_to_td). Running both caused
    a duplicate OSC flood on port 7000 every frame. Removed the old
    _OSC_ENABLED block, _TD_CLIENT setup, _MARKER_TO_METHOD, _osc_frame,
    and the _send_to_td function entirely.
2026-05-11 feat(td): merge audit fixes into vision2_state_chop — use this as compute_state
    Applied all state_chop_v1 audit fixes to the upgrade script:
    - hb_alive: tracks heartbeat advancement via _last_hb_value/_last_hb_frame;
    frozen OSC value no longer looks alive (90-frame / ~3s timeout)
    - method_id: sentinel changed to -1 (no signal) so 0 = explicit NONE tag;
    RFID fallback fetch uses -1 default; true floor is 0
    - area_m2: new output channel (area_px2 * _PX2_TO_M2); calibration
    constants at top of file — update _TABLE_W_M/_TABLE_H_M before demo
    vision2_state_chop.py is now the definitive compute_state script.
    Paste it into the existing compute_state Script CHOP in TD (Cook: Ev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
2026-05-11 Sync vision2 files and add LCA data CSVs
    - Update all vision/ source files to latest local versions
    - Add vision/data/ with masonry.csv, 3d-printed.csv, prefab.csv
    - Update data/methods_db.json from local TD data folder
    [3d-printed.csv, masonry.csv, prefab.csv]
2026-05-11 fix(vision): restore gesture grace period + timestamp + python-osc (reverted by Elias sync)
    Elias sync (f19d010) overwrote gestures.py with an older local version,
    losing 3 audit fixes. Re-applied:
    no longer resets the dwell timer (critical for bright install env)
    - MediaPipe timestamp: elapsed ms from _t0 instead of wall-clock epoch
    - Model download: try/except removes partial file on failure
    Also restored python-osc>=1.8.0 to requirements.txt — osc_bridge.py
    depends on it and run.bat installs from this file.
    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
2026-05-11 Replace MediaPipe index-finger detection with HSV red puck tracker
    - vision/puck_detector.py: new RedPuckDetector class using HSV colour
    masking to find the largest red blob in frame. Dwell 3 s in one spot
    fires place_point; puck must move REARM_RADIUS px before re-arming.
    Draws a progress ring and dwell bar on the camera feed.
    Drop-in replacement for GestureDetector (same output dict keys).
    - vision/main.py: swap import to RedPuckDetector; add U/R keyboard
    shortcuts for undo/reset (previously gesture-only); update status text.
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2026-05-11 feat(rfid): single source of truth — methods_db.json drives tag mapping
    Previously the UID → method_id mapping was hardcoded in serial_rfid_v1.py
    AND duplicated as rfid_tag fields in methods_db.json. Now the JSON wins:
    - serial_rfid_v1.py reads methods_db.json on every scan
    - Prefers op('methods_db') Text DAT (live edits picked up immediately)
    - Falls back to direct file read from project.folder + data/methods_db.json
    - Last-resort fallback: minimal hardcoded dict (NONE only)
    - Unknown tag → resets to NONE + prints UID with instructions
    Hardware team can now register tags by editing methods_db.json — no
    Python edits, no re-paste into TD.
    New: firmware/esp32-rfid/TAG-REGISTRY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
2026-05-11 fix: integrate RedPuckDetector — camera buffer + OSC gesture mapping
    vision/main.py:
    Restored cap.set(CAP_PROP_BUFFERSIZE, 1) — dropped in the puck detector
    refactor. Without it HSV detection runs on buffered frames with
    ~300ms lag, making the 3s dwell feel wrong.
    vision/osc_bridge.py:
    Added puck: 1 to _GESTURE_ID map. RedPuckDetector returns
    gesture=puck which was falling through to 0 (none), so TD saw
    gesture_id=0 all the time even when a puck was being tracked.
    Maps to slot 1 (same as index_only) so existing TD expressions
    that check gesture_id work unchanged.
2026-05-11 Fix OSC linkage for red puck detector
    state_chop_v1.py: fix OSC fallback channel from /method/id to
    /method/selected (matching what osc_bridge.py actually sends)
    vision2_state_chop.py: update gesture_id docs to puck/none; replace
    simple LIVENESS_FRAMES heartbeat check with TD-frame-advancement check
    (same robust logic as state_chop_v1) so hb_alive goes 0 correctly
    when the vision pipeline stalls rather than just disconnects
    vision/osc_bridge.py: strip dead hand-gesture entries from _GESTURE_ID
    (index_only/peace/three_fingers/fist) and _ACTION_ID (add_window/
    extrude/undo/reset) — red puck only produces none/puck and place_point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
2026-05-11 fix(rfid): tolerant parser — handle noisy serial frames
    ESP32→USB transmission sometimes drops/garbles bytes, producing lines
    like '!HB:625' or '!RFID:04003001F85713'. The previous strict
    startswith() check silently dropped these — only cleanly-framed scans
    made it through.
    Now:
    - find 'RFID:' anywhere in line, not just at start
    - strip non-hex artifacts from the captured UID
    - 'HB:' also matched anywhere in line
    - raw lines logged with repr() so transmission noise is visible
2026-05-11 Add hand gesture detector for undo/reset/extrude/add_window
    gesture_detector.py: MediaPipe HandLandmarker running alongside the red
    puck. Four gestures with dwell triggers:
    flat fist (horizontal) 2s → undo
    upright fist (vertical) 5s → reset
    index only 3s → extrude walls
    peace / V 2s → add window to nearest wall
    Flat vs upright distinguished by wrist-to-MCP9 angle from horizontal.
    Draws skeleton + progress bar 70px above the puck bar.
    main.py: run RedPuckDetector + GestureDetector every frame. Puck handles
    place_point; hand gestures handle all secondary actions. Hand tip position
    used for nearest-wall lookup on add_window. Removed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
2026-05-11 feat(td): panel_text module — single source for all text-panel content
    Replaces fragile inline-expression strings on each Text TOP with a single
    maintainable Python module. Each panel has a function that returns the
    text to display; the Text TOPs just call the function via expression.
    Functions:
    top_phase_navigation() — current build phase
    left_info() — selected method + description
    method_selection() — short method name (color-block companion)
    right_comparison() — all 3 methods, CO2 + labour side-by-side
    right_cost_chart() — current method's cost + time
    right_phase_preview() — static 5-phase checklist
    l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
2026-05-11 fix(viz): flip output vertically — TD TOPs use bottom-left origin
    The Script TOP renders a numpy array in top-left coordinates (Y down,
    natural for image arrays). But TD's TOPs use bottom-left (Y up). So the
    final image was rendering upside down — bottom_status text appearing at
    the top, etc.
    One-line fix: np.flipud(img) before copyNumpyArray. Now drawing code
    stays intuitive (Y down everywhere) and TD sees a correctly oriented
    final frame.
    Text TOPs that we blit in keep their existing flipud — those convert
    TD-native (bottom-left) tex into my top-left img, and the final flip
    sends the combined result back to TD's convention. Net effect: text
    reads right-side-up.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
2026-05-11 Session auto-commit 2026-05-11
    [3d-printed.csv, masonry.csv, prefab.csv]
2026-05-11 fix(td): RFID is single source for method_id — ignore vision2 token markers
    Team decision (2026-05-11): physical method selection stays RFID-only.
    vision2's /method/selected from ArUco token markers (IDs 20/21/22) is
    intentionally ignored in compute_state.
    vision2 still handles:
    - working plane (4 corner ArUcos)
    - footprint points (red puck → /puck/N)
    - hand gestures (undo/reset/extrude/window → /gesture/*)
    - sketch + FSM state
2026-05-11 fix(td): tolerant OSC channel name lookup — fixes hb_alive=0 bug
    TD's OSC In CHOP names channels differently depending on arg count:
    - single-arg messages: 'vision/heartbeat'
    - multi-arg messages: 'puck/0:0', 'puck/0:1', 'puck/0:2'
    The old code used 'vision/heartbeat:0' (with :0 suffix) which doesn't
    exist for single-arg messages → exception → hb_alive stuck at 0 →
    DISCONNECTED red X stayed visible even with vision2 streaming live.
    New _chan() helper tries both 'name' and 'name:0' variants and returns
    the first that resolves. Now heartbeat reads cleanly and hb_alive
    correctly toggles to 1 when vision2 is alive.
2026-05-11 fix(td): tolerant puck channel naming — handle both puck/N:0 and puck/N0
    TD's OSC In CHOP may name multi-arg messages with or without colons
    depending on settings. Now tries both variants for each arg.
2026-05-11 fix(vision): MX Brio — lock focus, exposure, white-balance
    Autofocus and auto-exposure constantly retune, causing brief frame
    artefacts that drop HSV red-puck tracking. The dwell timer resets on
    each loss, so users couldn't complete a 3-second placement.
    Now after camera open:
    - AUTOFOCUS off, FOCUS locked to ~30-50cm (overhead tabletop range)
    - AUTO_EXPOSURE off, EXPOSURE locked to -6 (typical indoor)
    - AUTO_WB off, WB_TEMPERATURE locked to 4500K (stabilises red hue)
2026-05-11 fix(viz): footprint_viz_v5 — same tolerant OSC channel naming as compute_state
    render_footprint had its own puck-reading code using strict 'puck/N:0'
    channel naming. After Leo's TD revealed it uses 'puck/N1' (1-based, no
    colon), this script also needed to be made tolerant.
    Now matches compute_state — tries all three naming conventions for
    each puck arg. The footprint geometry should appear in panel_main_plan_simulation.
2026-05-11 fix(td): detect OSC naming convention ONCE per cook, don't guess per-arg
    Previous fix tried each naming variant per arg independently:
    arg 0 → try puck/N:0, puck/N0, puck/N1
    arg 1 → try puck/N:1, puck/N1, puck/N2
    On Leo's TD where naming is 'flat1' (puck/N1, puck/N2, puck/N3),
    arg 0's lookup found puck/N1 (the frame counter) instead of failing
    through to puck/N1 for arg 0. Then arg 1 ALSO claimed puck/N1, getting
    the same value. Result: x=frame_counter (grows over time) which made
    points drift right across screen.
    Now detects which convention exists ONCE (probe puck/0:0, puck/00,
    puck/01) and uses it consistently for all puck reads in the cook.
    Fixes the 'points drift right' bug a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
